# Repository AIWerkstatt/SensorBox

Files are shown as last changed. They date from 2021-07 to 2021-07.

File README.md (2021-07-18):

**[aiWerkstatt™](https://www.aiwerkstatt.com)** works on the development of a **Visual AI research platform**, 
we call the **SensorBox™**.

R&D (Research and Development) of a Visual AI (Artificial Intelligence) system requires 
the use of a flexible embedded sensor suite that allows for experimentation and that can 
be used in the real environment. Using available benchmark datasets can only get you so far, 
and may not even be representative for your particular application. Building such a 
sensor suite can be quite complex and arguably is not really part of developing a 
software application.

Our goal is to build a research platform that can be used to develop state estimation, 
mapping and scene understanding applications. Our sensor suite consists of **stereo RGB cameras**, 
a **RGB-Depth camera**, a **thermal camera**, an **ultrasonic range finder**, a 
**GNSS** (Global Navigation Satellite System) receiver, **IMU**s (Inertial Measurement Unit), 
a **pressure sensor**, a **temperature sensor** and a **power sensor**. Our embedded processing platform 
consists of an **Arduino Zero** microcontroller and an **NVIDIA Jetson Xavier NX**. Our 
embedded power source consists of a **USB-C power bank**. 

As a  research platform, we are looking for maximum flexibility and re-use. We leverage 
existing and popular eco-systems for robotics, computer vision and artificial intelligence, 
in particular the [NVIDIA Jetson](https://developer.nvidia.com/embedded-computing) embedded 
processing platform, [SparkFun](https://www.sparkfun.com)’s microcontroller and sensors 
and [Arducam](https://www.arducam.com)’s suite of cameras. 

We provide this **GitHub repository** with all design and source code files and detailed documentation 
with step-by-step instructions and **[YouTube videos](https://www.youtube.com/channel/UCgJB5recIT7bXP8dV0AoSTw/videos)** 
on how to build the SensorBox™.

So far, we completed the design, 3D printing, hardware assembly and basic software setup. 
Next, we are going to work on a ROS2 based infrastructure, a qt-based GUI, sensor calibration 
and sensor synchronization.

**[aiWerkstatt™](https://www.aiwerkstatt.com)** provides the **SensorBox™** as an **open source product** in the hope that it will provide 
researchers in Visual AI with a jump start and when used by many that it will enable 
collaborations and create synergies.

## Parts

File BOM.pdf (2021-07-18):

aiWerkstattTM | SensorBoxTM v1.0 | 1/8

# Bill of Materials (BOM)

SensorBox v1.0 | $2,015.69
Sensors & Processing and Display | $1,455.86
Embedded Processor | $502.98
NVIDIA Jetson Xavier NX Dev. Kit | 1 | $399.00
Micro SD Card | 1 | $23.99
NVMe SSD Drive | 1 | $79.99
Microcontroller | | $24.95
| 1 | $24.95
Sensors | $103.35
1 | $69.95
| 1 | $16.95

Pressure (air)

SparkFun LPS25HB Pressure Sensor | 1 | $9.95

Temperature (internal)

SparkFun TMP102 Temperature Sensor | 1 | $6.50

The complete SensorBox as shown here will cost you around $2,000 (not counting tools). But you can also get started considerably cheaper, with a NVIDIA Jetson Nano (same form factor), a low cost power bank and just the cameras.

Amazon (https://www.amazon.com/NVIDIA-Jetson-Xavier-Developer-812674024318/dp/B086874Q5R?hvadid=459454121958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)

Amazon (https://www.amazon.com/Samsung-MicroSD-Adapter-MB-ME64GA-AM/dp/B06XX29S9Q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)

Amazon (https://www.amazon.com/Samsung-970-EVO-Plus-250GB/dp/B07M7Q21N7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)

SparkFun RedBoard Turbo Dev. Board
Arduino Zero | SparkFun (https://www.sparkfun.com/products/14812)

GNSS (Global Navigation Satellite System)

SparkFun NEO-M9N GPS | SparkFun (https://www.sparkfun.com/products/15733)

IMU (Inertial Measurement Unit)

SparkFun ICM-20948 9DoF IMU | SparkFun (https://www.sparkfun.com/products/15335)

SparkFun (https://www.sparkfun.com/products/14767)

SparkFun (https://www.sparkfun.com/products/16304)

Vision Sensors | | $612.82
Stereo RGB (rolling-shutter) Cameras with IMU
Arducam Sony IMX219 Camera Module | 2 | $19.99
FPC 15 pin Ribbon Cables | 1 | $5.99
SparkFun LSM9DS1 9DoF IMU | 2 | $15.95
SparkFun Qwiic Adapter | 2 | $1.50

RGB-D Camera with IMU

Intel Realsense D435i | 1 | $199.00

Thermal Camera

FLIR Lepton 3.5 | 1 | $199.00
GroupGets PureThermal 2 | 1 | $99.00

Ultrasonic Range Finder

SparkFun Ultrasonic Range Finder | 1 | $34.95
Power | $163.77
USB-C Charger | 1 | $25.99
Poweradd USB-C Power Bank | 1 | $82.99
SparkFun USB-C Power Delivery Board | 1 | $24.95
Zio INA219 Current and Voltage Sensor | 1 | $7.95

UCTRONICS (https://www.uctronics.com/arducam-8-mp-sony-visible-light-ir-fixed-focus-camera-module-for-nvidia-jetson-nano.html)

Amazon (https://www.amazon.com/gp/product/B089LM5D1T/ref=ppx_yo_dt_b_asin_title_o04_s00?ie=UTF8&psc=1)

SparkFun (https://www.sparkfun.com/products/13944)

SparkFun (https://www.sparkfun.com/products/14495)

Intel (https://www.intelrealsense.com/depth-camera-d435i/)

GroupGets (https://store.groupgets.com/collections/frontpage/products/flir-lepton-3-5)

GroupGets (https://store.groupgets.com/products/purethermal-2)

SparkFun (https://www.sparkfun.com/products/11309)

Amazon (https://www.amazon.com/gp/product/B08F7NHMLB/ref=ox_sc_act_title_1?smid=A1AEYAFEWEFJJF&psc=1)

Amazon (https://www.amazon.com/gp/product/B015VXJL2S/ref=ppx_yo_dt_b_asin_title_o08_s00?ie=UTF8&psc=1)

SparkFun (https://www.sparkfun.com/products/15801)

SparkFun (https://www.sparkfun.com/products/15176)

Power Button | 2 | $5.95
| 1 | $9.99
Display | $47.99
UCTRONICS 5 Inch Touch Screen Display | 1 | $47.99
3D Print | $129.27
Filaments | $49.98
PETG Blue 1.75mm (1kg) | 1 | $24.99
PETG Grey 1.75mm (1kg) | 1 | $24.99
Post-Processing | | $79.29
Super Glue | 1 | $7.99
Sandpaper 150 | 1 | $4.59
Sandpaper 400 | 1 | $7.59
Wet Sandpaper 1500 | 1 | $7.59
| 1 | $8.83
Scraper | 1 | $4.65

SparkFun (https://www.sparkfun.com/products/11967)

5x DC Barrel Jack Connector 5.5mm x 2.5mm Amazon (https://www.amazon.com/gp/product/B07DJ63MJP/ref=ppx_yo_dt_b_asin_title_o03_s00?ie=UTF8&psc=1)

UCTRONICS (https://www.uctronics.com/index.php/uctronics-5-inch-touch-screen-for-raspberry-pi.html)

MatterHackers (https://www.matterhackers.com/store/l/polymaker-polylite-petg-blue-175mm-1kg/sk/MH7R7F2N)

MatterHackers (https://www.matterhackers.com/store/l/polymaker-polylite-petg-grey-175mm-1kg/sk/MUR5Z8PG)

Amazon (https://www.amazon.com/gp/product/B00JN1E4TK/ref=ox_sc_act_title_1?smid=ATVPDKIKX0DER&psc=1)

Ace Hardware (https://www.acehardware.com/departments/paint-and-supplies/painting-tools-and-supplies/sandpaper/17613)

Ace Hardware (https://www.acehardware.com/departments/paint-and-supplies/painting-tools-and-supplies/sandpaper/19807)

Ace Hardware (https://www.acehardware.com/departments/paint-and-supplies/painting-tools-and-supplies/sandpaper/19805)

Bondo Filler | Amazon (https://www.amazon.com/gp/product/B00PB3NTZ4/ref=ox_sc_act_title_3?smid=ATVPDKIKX0DER&psc=1)
| Amazon (https://www.amazon.com/Spatula-Scraper-Multipurpose-Kitchen-Pieces/dp/B088WN9LR6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)

Automotive Primer and Filler | 1 | $13.53
1 | $12.60
| 1 | $11.92
Assembly | $430.56
100x M3x6 Screws | 1 | $8.19
100x M3x5 Screws | 1 | $7.49
25x M2x6 Screws | 1 | $6.49
100x M2x4 Screws | 1 | $7.99
100x M3x6x4.5 Threaded Heat Inserts | 1 | $9.79
100x M3x4x5 Threaded Heat Inserts | 1 | $7.91
100x M2x4x3.5 Threaded Heat Inserts | 1 | $7.91
250x M2/M2/M3 Threaded Heat Inserts | 1 | $15.88
Self-Adhesive Cleat Pads | 1 | $4.99
1 | $3.59
Break Away Headers | 1 | $1.50

Amazon (https://www.amazon.com/Dupli-Color-EFP101007-General-Purpose-Sandable/dp/B000B6DG7C)

Automotive Silver Matt Spray | Amazon (https://www.amazon.com/gp/product/B00407TVGS/ref=ppx_yo_dt_b_asin_title_o01_s00?ie=UTF8&psc=1)
Automotive Clear Matt Spray | Amazon (https://www.amazon.com/gp/product/B07CZBBDF5/ref=ppx_yo_dt_b_asin_title_o01_s00?ie=UTF8&psc=1)

Amazon (https://www.amazon.com/gp/product/B00W8YSCIS/ref=ppx_yo_dt_b_asin_title_o07_s01?ie=UTF8&psc=1)

Amazon (https://www.amazon.com/gp/product/B01C3LHQ0K/ref=ppx_yo_dt_b_asin_title_o08_s00?ie=UTF8&psc=1)

Amazon (https://www.amazon.com/gp/product/B01FL88Y76/ref=ppx_yo_dt_b_asin_title_o07_s01?ie=UTF8&psc=1)

Amazon (https://www.amazon.com/gp/product/B01B1OD83Y/ref=ppx_yo_dt_b_asin_title_o00_s00?ie=UTF8&psc=1)

Amazon (https://www.amazon.com/gp/product/B087NBYF65/ref=ppx_yo_dt_b_asin_title_o07_s01?ie=UTF8&psc=1)

Amazon (https://www.amazon.com/Hilitchi-Threaded-Embedment-Projects-M2x4mmx3-5mm/dp/B07VBRF7P2)

Amazon (https://www.amazon.com/gp/product/B07VBRF7P2/ref=ppx_yo_dt_b_asin_title_o06_s00?ie=UTF8&psc=1)

Amazon (https://www.amazon.com/gp/product/B0784VYCYY/ref=ppx_yo_dt_b_asin_title_o06_s00?ie=UTF8&psc=1)

ACE Hardware (https://www.acehardware.com/departments/home-and-decor/cabinet-and-furniture-hardware/protective-furniture-pads/5044524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)

8x 14inch Cable Ties | ACE Hardware (https://www.acehardware.com/departments/lighting-and-electrical/cable-management-cable-ties-and-electrical-tape/cable-ties/34807)

SparkFun (https://www.sparkfun.com/products/116)

40x 2 pin Screw Terminal Block Connector | 1 | $6.99
SparkFun Qwicc Cable Kit | 1 | $7.95
SparkFun Qwicc Cable 50mm | 1 | $0.95
22 AWG Wires | 1 | $16.95
Heat Shrink Tubes | 1 | $7.99
100x Quick Disconnect Terminal Connector | 1 | $7.75
Duck Tape | 1 | $5.93
Double-Sided Tape | 1 | $8.99
| 1 | $9.90
| 1 | $6.24
2x USB-C direct-through Keystone Jacks | 1 | $9.90

Amazon (https://www.amazon.com/gp/product/B07B791NMQ/ref=ppx_yo_dt_b_asin_title_o00_s00?ie=UTF8&psc=1)

SparkFun (https://www.sparkfun.com/products/15081)

SparkFun (https://www.sparkfun.com/products/14426)

SparkFun (https://www.sparkfun.com/products/11367)

Amazon (https://www.amazon.com/gp/product/B073R69KNB/ref=ppx_yo_dt_b_asin_title_o05_s02?ie=UTF8&psc=1)

Amazon (https://www.amazon.com/gp/product/B01EE3QGG0/ref=ppx_yo_dt_b_asin_title_o05_s01?ie=UTF8&psc=1)

Amazon (https://www.amazon.com/3M-Contractor-Grade-Multi-Use-Silver/dp/B00DJWTGAG?s=industrial)

Amazon (https://www.amazon.com/gp/product/B07T1PWMTT/ref=ppx_yo_dt_b_asin_title_o00_s00?ie=UTF8&psc=1)

5x USB 3.0 direct-through Keystone Jacks | Amazon (https://www.amazon.com/gp/product/B078935SFG/ref=ppx_yo_dt_b_asin_title_o01_s02?ie=UTF8&psc=1)
HDMI direct-through Keystone Jack | Amazon (https://www.amazon.com/gp/product/B005VKKB7Q/ref=ppx_yo_dt_b_asin_title_o01_s01?ie=UTF8&psc=1)
| Amazon (https://www.amazon.com/gp/product/B078495TVK/ref=ppx_yo_dt_b_asin_title_o01_s03?ie=UTF8&psc=1)

PC Computer Air Filter | 1 | $8.99
2x HDMI Male to Female Cable | 1 | $7.99
2 | $6.49
DisplayPort Male to HDMI Female Cable | 1 | $13.99
HDMI Male to Male Cable | 1 | $7.36
Micro USB to USB Cable | 2 | $6.49
USB-C Male to Male 100W Cable | 1 | $9.99
USB-C Male to Male 100W Cable | 1 | $9.99
Long USB Cable | 1 | $10.99
Long HDMI Cable | 1 | $9.99
HDMI Monitor | 1 | $93.99
Dual USB & Bluetooth Keyboard and Mouse | 1 | $47.99

Amazon (https://www.amazon.com/gp/product/B000FJU8BC/ref=ppx_yo_dt_b_asin_title_o01_s03?ie=UTF8&psc=1)

Amazon (https://www.amazon.com/gp/product/B06WGPT999/ref=ppx_yo_dt_b_asin_title_o06_s00?ie=UTF8&psc=1)

90° Micro USB to USB Cable | Amazon (https://www.amazon.com/gp/product/B003YKX6WC/ref=ppx_yo_dt_b_asin_title_o01_s00?ie=UTF8&psc=1)

Amazon (https://www.amazon.com/gp/product/B019Q652AG/ref=ppx_yo_dt_b_asin_title_o02_s00?ie=UTF8&psc=1)

Amazon (https://www.amazon.com/gp/product/B07KSP1SMS/ref=ppx_yo_dt_b_asin_title_o02_s00?ie=UTF8&psc=1)

Amazon (https://www.amazon.com/6in-Micro-USB-Cable-6-inches/dp/B002L5ZEYY)

Amazon (https://www.amazon.com/gp/product/B072M7GH29/ref=ppx_yo_dt_b_asin_title_o00_s00?ie=UTF8&psc=1)

Amazon (https://www.amazon.com/gp/product/B08816SYKY/ref=ppx_yo_dt_b_asin_title_o09_s02?ie=UTF8&psc=1)

Amazon (https://www.amazon.com/gp/product/B00HSS9L6G/ref=ppx_yo_dt_b_asin_title_o04_s00?ie=UTF8&psc=1)

Amazon (https://www.amazon.com/AmazonBasics-High-Speed-HDMI-Cable-1-Pack/dp/B014I8T0YQ?s=electronics)

Amazon (https://www.amazon.com/Acer-SB220Q-Ultra-Thin-Frame-Monitor/dp/B07CVL2D2S?s=electronics)

Amazon (https://www.amazon.com/gp/product/B0899DRDYR/ref=ppx_yo_dt_b_asin_title_o07_s00?ie=UTF8&psc=1)

30x Circuit Board Jumper Caps | 1 | $5.08
Jumper Wires | 1 | $6.98
Tools | $998.38
Caliper | 1 | $8.99

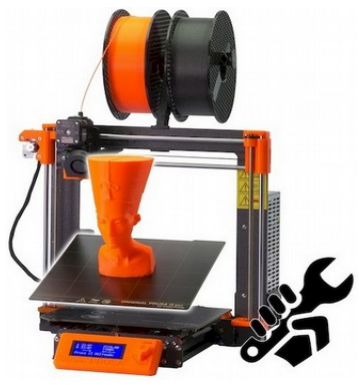
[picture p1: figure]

1 | $749.00
Carving Craft Knife | 1 | $9.99
Needle File Set | 1 | $16.05
Sander | 1 | $36.38
Sanding Discs | 1 | $14.99
Soldering Iron | 1 | $20.99
Helping Hands | 1 | $22.99

Amazon (https://www.amazon.com/gp/product/B077957RN7/ref=ppx_yo_dt_b_search_asin_title?ie=UTF8&psc=1&fpw=alm)

Amazon (https://www.amazon.com/Elegoo-EL-CP-004-Multicolored-Breadboard-arduino/dp/B01EV70C78)

Amazon (https://www.amazon.com/gp/product/B07VSVMWTJ/ref=ppx_yo_dt_b_asin_title_o00_s00?ie=UTF8&psc=1)

3D Printer | Prusa Research (https://shop.prusa3d.com/en/3d-printers/180-original-prusa-i3-mk3s-kit.html#)

Amazon (https://www.amazon.com/Mlife-Precision-Carving-Stainless-Cutting/dp/B074P34MFB)

Amazon (https://www.amazon.com/gp/product/B07TSK23LY/ref=ppx_yo_dt_b_asin_title_o07_s00?ie=UTF8&psc=1)

Amazon (https://www.amazon.com/gp/product/B08B6G2X2H/ref=ppx_yo_dt_b_asin_title_o03_s00?ie=UTF8&psc=1)

Amazon (https://www.amazon.com/gp/product/B06XQH4PVM/ref=ppx_yo_dt_b_asin_title_o03_s00?ie=UTF8&psc=1)

Amazon (https://www.amazon.com/gp/product/B06XZ31W3M/ref=ppx_yo_dt_b_asin_title_o08_s00?ie=UTF8&psc=1)

Amazon (https://www.amazon.com/gp/product/B07MDKXNPC/ref=ppx_yo_dt_b_asin_title_o08_s00?ie=UTF8&psc=1)

| 1 | $7.95
| 1 | $12.95
Crimper | 1 | $22.29
Heat Gun | 1 | $12.99
Allen Keys | 1 | $15.29
Screwdrivers | 1 | $18.69
Precision Screwdrivers | 1 | $13.89
Multimeter | 1 | $14.95

## Computers

Solder | SparkFun (https://www.sparkfun.com/products/9325)
Wire Strippers | SparkFun (https://www.sparkfun.com/products/14762) Amazon (https://www.amazon.com/IWISS-SN-28B-Crimping-AWG28-18-Dupont/dp/B00OMM4YUY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)
| Amazon (https://www.amazon.com/gp/product/B07P5WFHJ7/ref=ppx_yo_dt_b_asin_title_o05_s01?ie=UTF8&psc=1)

Amazon (https://www.amazon.com/Eklind-Tool-Company-10222-Combination/dp/B000189PRU?s=hi)

Amazon (https://www.amazon.com/VHEONET-Screwdriver-Precision-Professional-Improvement/dp/B08GX4SSJM?s=hi)

Amazon (https://www.amazon.com/dp/B07SL25J5J)

SparkFun (https://www.sparkfun.com/products/12966)

Ubuntu 18 Host Computer
preferable with a NVIDIA graphics card

Windows 10 Computer
only for use with SparkFun NEO-M9N GPS

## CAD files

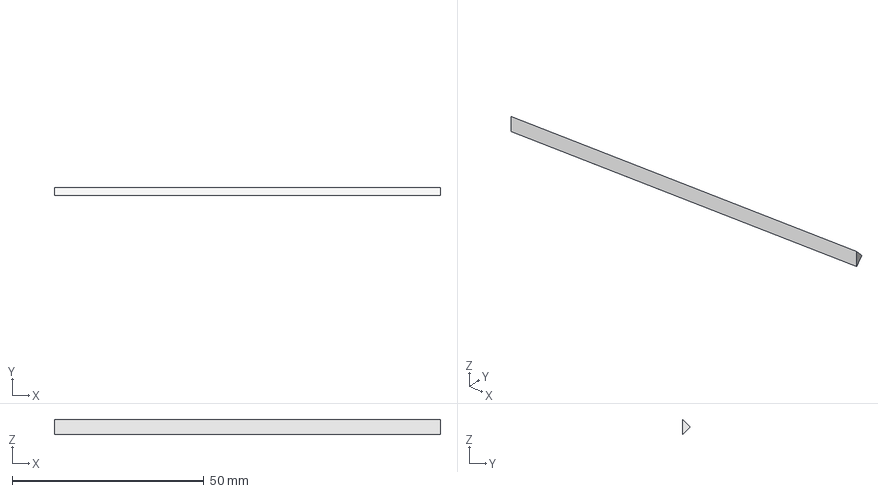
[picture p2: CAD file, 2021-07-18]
1-CAD/Design/Cover/Display_Wall_Groove_Triangle_w4xd2xl100.7.step
100.7 x 2.00 x 4.00 mm

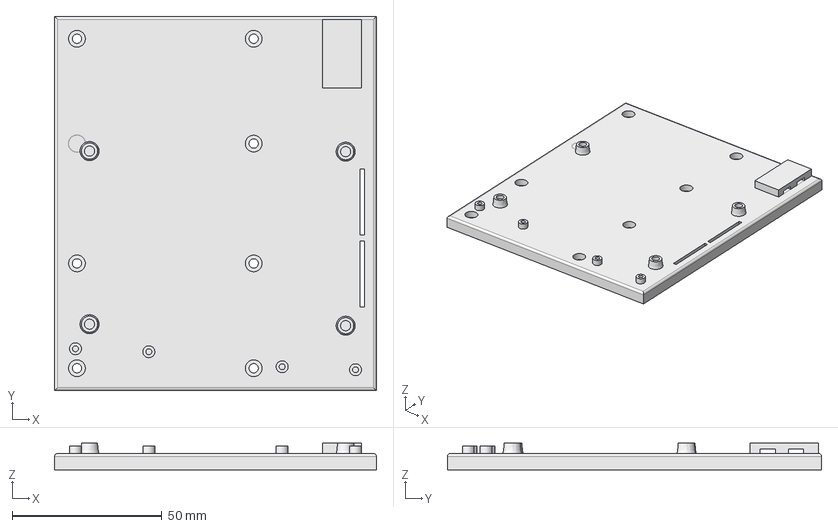
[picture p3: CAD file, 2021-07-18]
1-CAD/Design/Sensors & Processing Board/Processing_Board.FCStd
107.5 x 125.0 x 9.00 mm

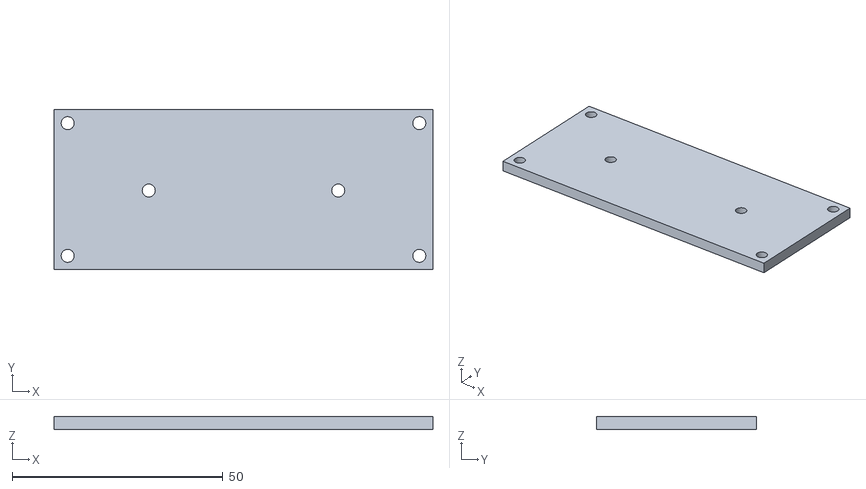
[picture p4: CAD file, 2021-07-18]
1-CAD/STL-files/IntelRS_Support.stl
90.0 x 38.0 x 3.00

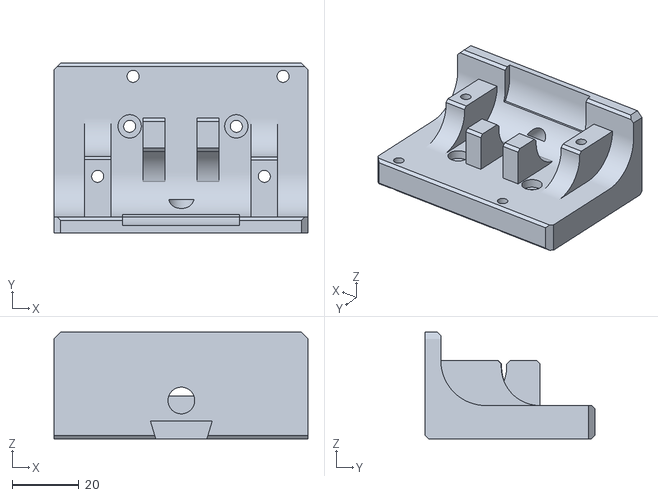
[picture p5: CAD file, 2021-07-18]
4-Setup/sw/NVIDIA_Jetson_Xavier_NX/Intel_RealSense_D435i/librealsense/examples/tracking-and-depth/bracket_t265nd435_external.stl
76.2 x 51.0 x 32.0

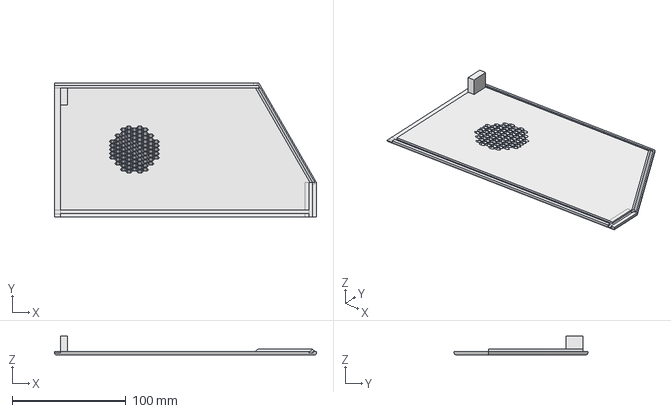
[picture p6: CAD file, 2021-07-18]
1-CAD/Design/Cover/Side_Wall.step
230.0 x 117.2 x 16.5 mm

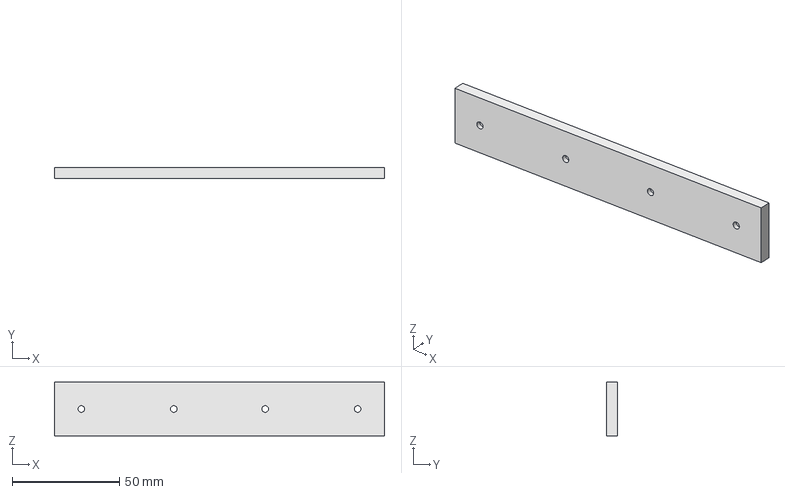
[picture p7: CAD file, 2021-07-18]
1-CAD/Design/Sensors & Processing Board/Support.step
153.5 x 5.00 x 25.0 mm

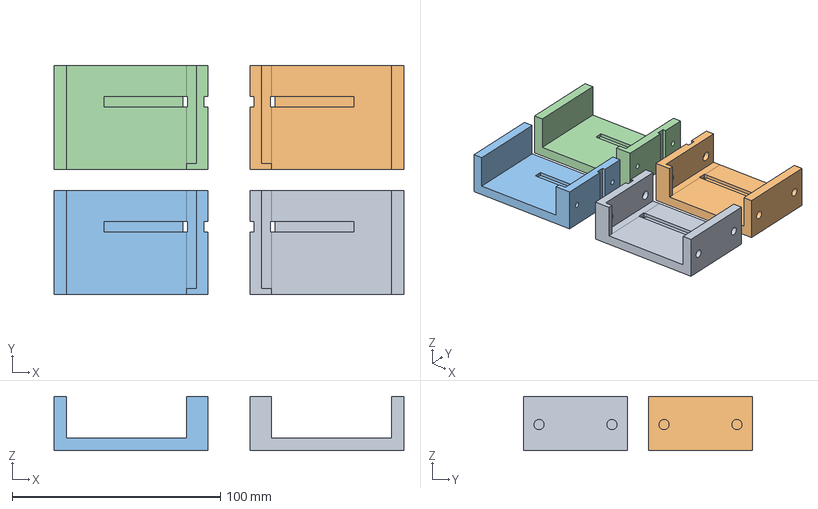
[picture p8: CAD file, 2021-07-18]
1-CAD/Design/Sensors & Processing Board/Battery_Stand.FCStd
168.0 x 110.0 x 26.0 mm
Battery Stand Blueprint (back/right)
Battery Stand (front/left) without holes in the back
Battery Stand (front/right) (Mirror #1)
Battery Stand (back/left) (Mirror #2)

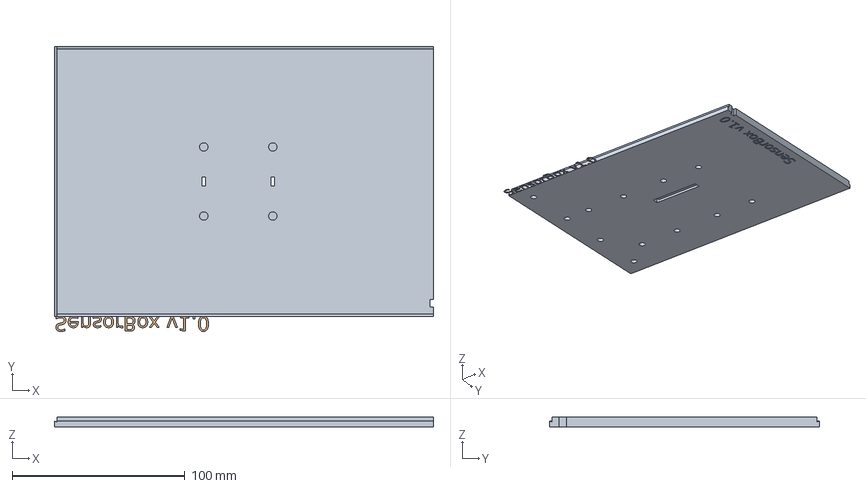
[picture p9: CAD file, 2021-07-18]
1-CAD/Design/Sensors & Processing Board/Bottom_Plate.FCStd
219.6 x 165.2 x 6.00 mm
Bottom Plate
ShapeString
Product Name

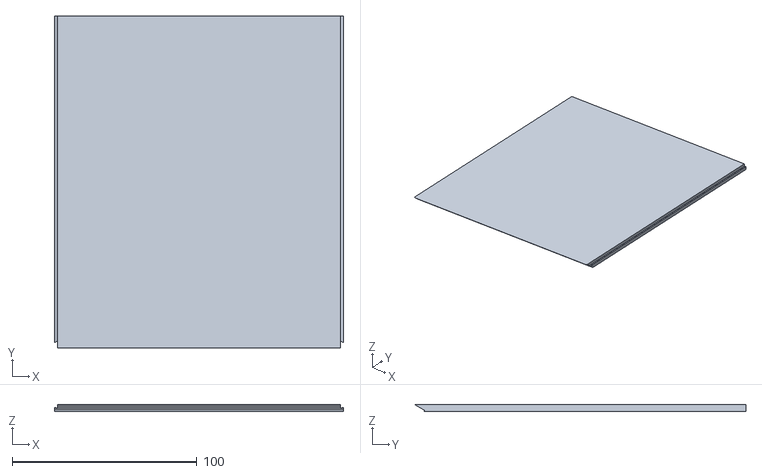
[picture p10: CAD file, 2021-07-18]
1-CAD/STL-files/Top_Wall.stl
156.5 x 179.6 x 4.00

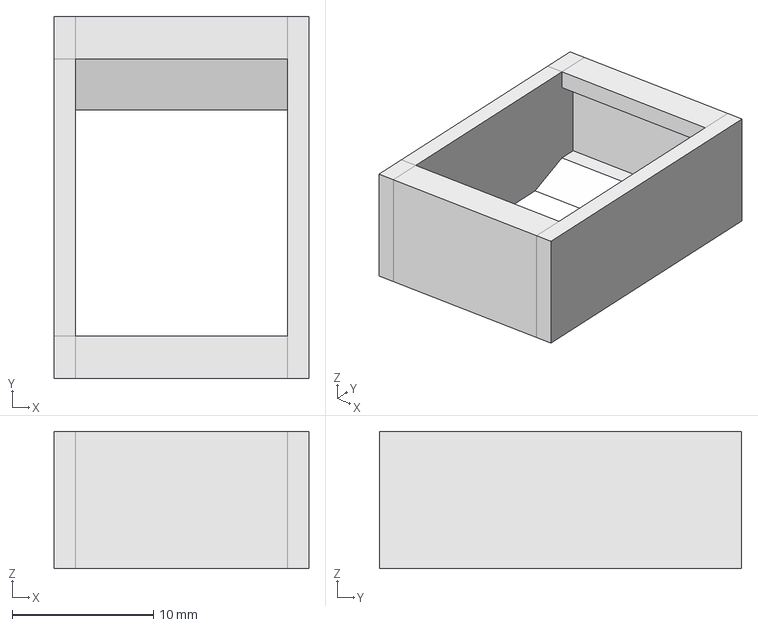
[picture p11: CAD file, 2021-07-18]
1-CAD/Design/Cover/Keystone_Insert.step
18.0 x 25.6 x 9.70 mm

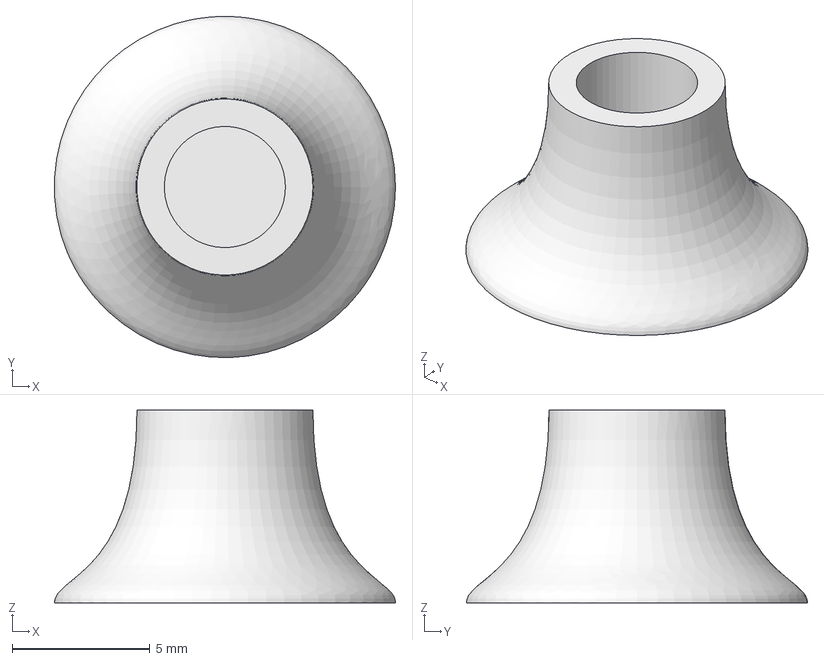
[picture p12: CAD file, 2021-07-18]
1-CAD/Design/Sensors & Processing Board/MXxXxX_Stand.FCStd
12.4 x 12.4 x 7.00 mm

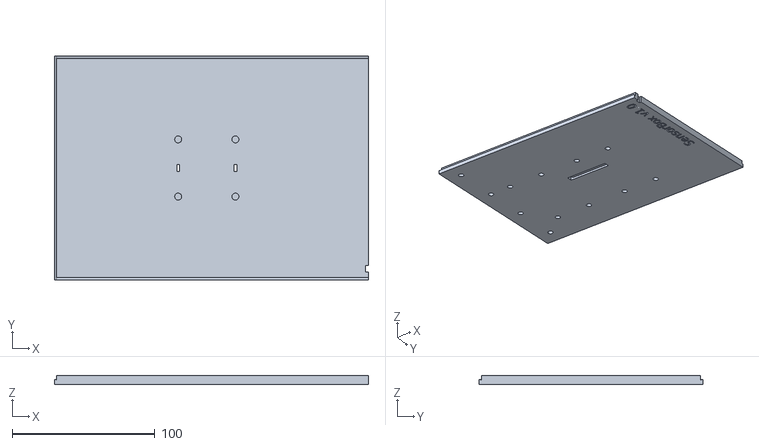
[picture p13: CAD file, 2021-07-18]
1-CAD/STL-files/Bottom_Plate.stl
219.6 x 156.5 x 6.00

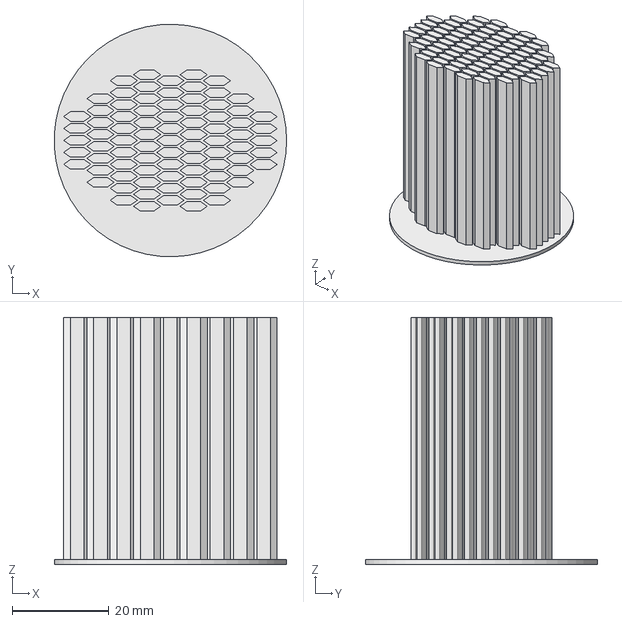
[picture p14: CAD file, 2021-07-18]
1-CAD/Design/Cover/Air_Holes.step
48.0 x 48.0 x 51.0 mm

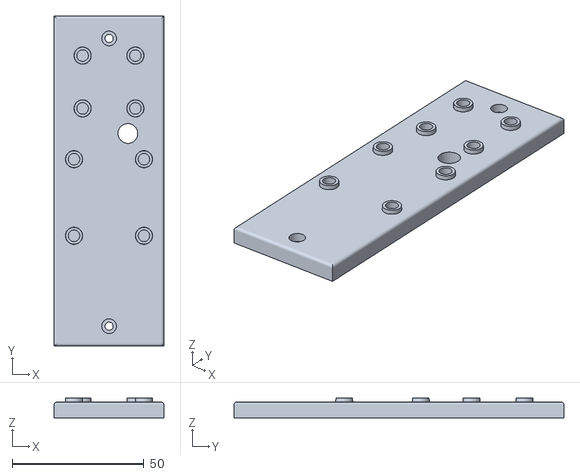
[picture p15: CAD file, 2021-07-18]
1-CAD/STL-files/Power_Board.stl
41.6 x 125.0 x 7.50

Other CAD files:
1-CAD/STL-files/Processing_Board.stl
1-CAD/Design/Cover/Display_Wall_Groove_Railing_Triangle.FCStd
1-CAD/STL-files/Battery_Stand.stl
1-CAD/Design/Cover/Display_Wall_Groove_Triangle.FCStd
1-CAD/Design/Cover/Air_Holes.FCStd
1-CAD/Design/Cover/Back_Wall.FCStd
1-CAD/Design/Cover/Display_Wall.FCStd
1-CAD/Design/Cover/Display_Wall.step
1-CAD/Design/Cover/Display_Wall_Groove_Railing_Triangle_w3.9xd2xl100.7.step
1-CAD/Design/Cover/Keystone_Insert.FCStd
1-CAD/Design/Cover/Side_Wall.FCStd
1-CAD/Design/Cover/Side_Wall_Left.FCStd
1-CAD/Design/Cover/Side_Wall_Right.FCStd
1-CAD/Design/Cover/Top_Wall.FCStd
1-CAD/Design/Sensors & Processing Board/Intel_RealSense_Support.FCStd
1-CAD/Design/Sensors & Processing Board/M2x6x3.5_Stand.step
1-CAD/Design/Sensors & Processing Board/M3x6x4.5_Stand.step
1-CAD/Design/Sensors & Processing Board/Power_Board.FCStd
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

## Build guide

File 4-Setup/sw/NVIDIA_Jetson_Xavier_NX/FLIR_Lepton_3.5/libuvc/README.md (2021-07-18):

`libuvc` is a cross-platform library for USB video devices, built atop `libusb`.
It enables fine-grained control over USB video devices exporting the standard USB Video Class
(UVC) interface, enabling developers to write drivers for previously unsupported devices,
or just access UVC devices in a generic fashion.

## Getting and Building libuvc

Prerequisites: You will need `libusb` and [CMake](http://www.cmake.org/) installed.

To build, you can just run these shell commands:

    git clone https://github.com/groupgets/libuvc
    cd libuvc
    mkdir build
    cd build
    cmake ..
    make && sudo make install

and you're set! If you want to change the build configuration, you can edit `CMakeCache.txt`
in the build directory, or use a CMake GUI to make the desired changes.

## Developing with libuvc

The documentation for `libuvc` can currently be found at https://int80k.com/libuvc/doc/.

Happy hacking!

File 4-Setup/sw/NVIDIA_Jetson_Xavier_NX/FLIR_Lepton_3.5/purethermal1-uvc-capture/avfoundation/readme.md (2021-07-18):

About PT1Recorder
================

This example very lightly modified from Apple's AVRecorder example.

PT1Recorder demonstrates usage of AV Foundation capture API for recording movies and using transport controls.

The main components are:

• AVRecorderDocument.[h,m] -- The core PT1Recorder code
• AVCaptureDeviceFormat_AVRecorderAdditions.[h,m] -- Prints a pretty device format NSString
• AVFrameRateRange_AVRecorderAdditions.[h,m] -- Prints a pretty frame rate NSString

Using the Sample
----------------
Begin and complete video recording with the Record button. If the selected video device supports transport controls, use the Rewind, Play, Stop, and FF buttons to control the tape.

How It Works
------------

PT1Recorder makes use of the following AV Foundation AVCapture classes to provide movie recording:

AVCaptureDevice
AVCaptureFileOutput
AVCaptureInput
AVCaptureMovieFileOutput
AVCaptureOutput
AVCaptureSession
AVCaptureVideoPreviewLayer

See the AV Foundation documentation for more information.

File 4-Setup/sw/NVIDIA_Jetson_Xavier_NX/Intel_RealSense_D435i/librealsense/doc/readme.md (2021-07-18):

## Useful Links
* White papers and further documents are available at: [intel-realsense-downloads](https://realsense.intel.com/intel-realsense-downloads/)
* [Intel RealSense Community](https://communities.intel.com/community/tech/realsense) - Official support, Q&A and other useful content
* [Support Site](http://www.intel.com/content/www/us/en/support/emerging-technologies/intel-realsense-technology.html) - Contains content and web ticket capability for 1:1 interaction
* [Intel RealSense Stereoscopic Depth Cameras](https://arxiv.org/abs/1705.05548) - A technical paper describing the R200, LR200, SR300 and RS400 in detail. Includes theoretical background, performance expectations, post-processing suggestions, etc.  
* [Build an Autonomous Mobile Robot with the Intel® RealSense™ D400 Series Camera, ROS*, and SAWR](https://software.intel.com/en-us/articles/build-an-autonomous-mobile-robot-with-the-intel-realsense-camera-ros-and-sawr)

## librealsense Wiki
* [API How-To](https://github.com/IntelRealSense/librealsense/wiki/API-How-To) - List ot questions and answers related to the camera API
* [Troubleshooting Q&A](https://github.com/IntelRealSense/librealsense/wiki/Troubleshooting-Q&A) - List of questions and answers related to camera setup
* [Build Configuration](https://github.com/IntelRealSense/librealsense/wiki/Build-Configuration) - List of supported CMake flags
* [Projection In RealSense SDK 2.0](https://github.com/IntelRealSense/librealsense/wiki/Projection-in-RealSense-SDK-2.0) - A comprehensive document on Projection, Deprojection, and related helper processing-blocks the SDK provides

## Documentation

* [Depth from Stereo](depth-from-stereo.md) - Tutorial introducing users to depth from stereo technology 
* [API Architecture](api_arch.md) - Overview of the high-level concepts
* [C API](../include/librealsense2) - With doxygen-style API comments
  * [Latest Doxygen Output](http://intelrealsense.github.io/librealsense/doxygen/annotated.html)
  * To build documentation locally from sources, on Ubuntu run the following commands:
    * `sudo apt-get install doxygen`
    * `cd doc/doxygen`
    * `doxygen doxyfile`
  * Please also refer to [API How-To](https://github.com/IntelRealSense/librealsense/wiki/API-How-To) for further doc how to use the APIs
* [Frame Management](frame_lifetime.md) - Frame Memory Management, Threading Model and Synchronization
* [Frame Metadata](frame_metadata.md) - Support for frame-metadata attributes
* [Post-Processing Filters](post-processing-filters.md) - Post-acquisition Depth enhancement techniques
* [Getting Started](stepbystep/getting_started_with_openCV.md) - Getting started with OpenCV
* [Error Handling](error_handling.md) - Documents librealsense error handling policy
* Device specific topics:
  * [D400 at realsense.intel.com/](https://realsense.intel.com/stereo) - Camera specifications
  * [D400 Advanced Mode](rs400/rs400_advanced_mode.md) - Overview of the Advanced Mode APIs
  * [D400 cameras with Raspberry Pi](./RaspberryPi3.md) - Example of low-end system without USB3 interface
  * [D400 cameras on **rooted** Android devices](./android.md) - Instructions of how to build the RealSense SDK for Android OS.
  * [D435i depth camera with IMU](./d435i.md) - An introduction to the D435i depth camera and it's IMU
  * [T265 tracking module](./t265.md) - An introduction to the T265 tracking module
* [Record and Playback](../src/media/readme.md) - SDK Record and Playback functionality using ROS-bag file format

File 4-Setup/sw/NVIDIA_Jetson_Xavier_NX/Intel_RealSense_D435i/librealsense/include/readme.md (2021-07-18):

# librealsense2 API

# File-System Structure

Under `librealsense2` folder you will find two subfolers:
* [h](./librealsense2/h) - Contains headers for the C language
* [hpp](./librealsense2/hpp) - Contains headers for the C++ language, depends on C headers

In addition, you can include [<librealsense2/rs.h>](./librealsense2/rs.h) and [<librealsense2/rs.hpp>](./librealsense2/rs.hpp) to get most of SDK functionality in C and C++ respectively. 

[<librealsense2/rs_advanced_mode.h>](./librealsense2/rs_advanced_mode.h) and [<librealsense2/rs_advanced_mode.hpp>](./librealsense2/rs_advanced_mode.hpp) can be included to get the extra [Advanced Mode](../doc/rs400_advanced_mode.md) functionality (in C and C++ respectively).

[<librealsense2/rsutil.h>](./librealsense2/rsutil.h) contains mathematical helper functions for projection of 2D points into 3D space and back. 

# Files and Classes

> For full up-to-date class documentation see [Doxygen class-list](http://intelrealsense.github.io/librealsense/doxygen/annotated.html)

## [rs_types.hpp](librealsense2/hpp/rs_types.hpp):

This file contains common functionality like the exception types. See [Error Handling](..doc/error_handling.md)

|Class|Description|
|-----|---|
|[error](librealsense2/hpp/rs_types.hpp#L76)| Common base-class for all exceptions thrown from the SDK |
|[recoverable_error](librealsense2/hpp/rs_types.hpp#L113)| Base class for all recorverable (in software) errors |
|[unrecoverable_error](librealsense2/hpp/rs_types.hpp#L114)| Base class for non-recoverable errors |
|[camera_disconnected_error](librealsense2/hpp/rs_types.hpp#L115)| Camera Disconnected error |
|[backend_error](librealsense2/hpp/rs_types.hpp#L116)| Error from the underlying OS-specific driver |
|[device_in_recovery_mode_error](librealsense2/hpp/rs_types.hpp#L117)| Device requires firmware update |
|[invalid_value_error](librealsense2/hpp/rs_types.hpp#L118)| Invalid input was passed to a function |
|[wrong_api_call_sequence_error](librealsense2/hpp/rs_types.hpp#L119)| Methods were called in wrong order |
|[not_implemented_error](librealsense2/hpp/rs_types.hpp#L120)| Functionality is not available error |

## [rs_context.hpp](librealsense2/hpp/rs_context.hpp):
Context can be used to enumerate and iterate over connected device, and also get notifications of device events. 

|Class|Description|
|-----|---|
|[context](librealsense2/hpp/rs_context.hpp#L81)| Context serve as a factory for all SDK devices |
|[device_hub](librealsense2/hpp/rs_context.hpp#L185)| Helper class that simplifies handling device change events |
|[event_information](librealsense2/hpp/rs_context.hpp#L16)| Information about device change |

## [rs_device.hpp](librealsense2/hpp/rs_device.hpp):
This file defines the concept of RealSense device. 

|Class|Description|
|-----|---|
|[device](librealsense2/hpp/rs_device.hpp#L109)| Encapsulates Intel RealSense device |
|[device_list](librealsense2/hpp/rs_device.hpp#L186)| Wrapper around list of devices |
|[debug_protocol](librealsense2/hpp/rs_device.hpp#L151)| Debug-extension that allows to send data directly to the firmware |

## [rs_processing.hpp](librealsense2/hpp/rs_processing.hpp):
The SDK offers many types of post-processing in form of the Processing Blocks. These primitives can be pipelined using queues and configured using options. 

|Class|Description|
|-----|---|
|[syncer](librealsense2/hpp/rs_processing.hpp#L260)| Processing block that accepts frames one-by-one and outputs coherent framesets|
|[frame_queue](librealsense2/hpp/rs_processing.hpp#L136)| Basic primitive abstracting a concurrent queue of frames|
|[processing_block](librealsense2/hpp/rs_processing.hpp#L105)| Base class for frame processing functions |
|[pointcloud](librealsense2/hpp/rs_processing.hpp#L196)| Processing block that accepts depth and texture frames and outputs 3D points with texture coordinates |
|[asynchronous_syncer](librealsense2/hpp/rs_processing.hpp#L232)| Non-blocking version of the syncher processing block |
|[align](librealsense2/hpp/rs_processing.hpp#L316)| Processing block that accepts frames from different viewports and generates new synthetic frames from a single given viewport |
|[colorizer](librealsense2/hpp/rs_processing.hpp#L356)| Processing block that accepts depth frames in Z16 format and outputs depth frames in RGB format, applying some depth coloring |
|[decimation_filter](librealsense2/hpp/rs_processing.hpp#L391)| Processing block that intelligently reduces the resolution of a depth frame |
|[temporal_filter](librealsense2/hpp/rs_processing.hpp#L428)| Processing block that filters depth data by looking into previous frames |
|[spatial_filter](librealsense2/hpp/rs_processing.hpp#L465)| Processing block that applies edge-preserving smoothing of depth data|

## [rs_sensor.hpp](librealsense2/hpp/rs_sensor.hpp):
RealSense devices contain sensors. Sensors are units of streaming, each sensor can be controlled individually. 

|Class|Description|
|-----|---|
|[sensor](librealsense2/hpp/rs_sensor.hpp#L392)| Base class for all supported sensors|
|[roi_sensor](librealsense2/hpp/rs_sensor.hpp#L446)| Sensor that has the ability to focus on a given ROI|
|[notification](librealsense2/hpp/rs_sensor.hpp#L15)| Asynchronious message that can be passed to the application |
|[depth_sensor](librealsense2/hpp/rs_sensor.hpp#L479)| Sensor that can provide depth frames |

## [rs_frame.hpp](librealsense2/hpp/rs_frame.hpp):
The output of sensors are frames. There are different kinds of frames, not all video frames. 

|Class|Description|
|-----|---|
|[frame](librealsense2/hpp/rs_frame.hpp#L157)| Base class for all frames |
|[points](librealsense2/hpp/rs_frame.hpp#L423)| Set of 3D points with texture coordinates |
|[video_frame](librealsense2/hpp/rs_frame.hpp#L348)| 2D image (with width, height and bpp) |
|[depth_frame](librealsense2/hpp/rs_frame.hpp#L480)| Depth frame |
|[frameset](librealsense2/hpp/rs_frame.hpp#L502)| A set of frames |
|[stream_profile](librealsense2/hpp/rs_frame.hpp#L24)| Base class for sensor configuration |
|[video_stream_profile](librealsense2/hpp/rs_frame.hpp#L113)| Video stream configuration |

## [rs_pipeline.hpp](librealsense2/hpp/rs_pipeline.hpp):
Pipeline is a high-level primitive combining several sensors and processing steps into one simple API. 

|Class|Description|
|-----|---|
|[pipeline](librealsense2/hpp/rs_pipeline.hpp#L345)| High level data-processor combining several sensors, queues and processing blocks |
|[pipeline_profile](librealsense2/hpp/rs_pipeline.hpp#L22)| Selected pipeline configuration |
|[config](librealsense2/hpp/rs_pipeline.hpp#L128)| Desired pipeline configuration |

## [rs_record_playback.hpp](librealsense2/hpp/rs_record_playback.hpp):
This file adds playback and record capability using ROS-bag files. See [src/media](src/media)

|Class|Description|
|-----|---|
|[playback](librealsense2/hpp/rs_record_playback.hpp#L30)| Device that mimiks live device from given input file |
|[recorder](librealsense2/hpp/rs_record_playback.hpp#L206)| Device that records live device into an output file |

## [rs_internal.hpp](librealsense2\hpp\rs_internal.hpp):
This file is not intented to be included by SDK users, but rather is used in SDK unit-tests. It allows to record everything that will happen in a specific test into a file and later use that file for dependency injection. 

|Class|Description|
|-----|---|
|[recording_context](librealsense2\hpp\rs_internal.hpp#L19)| Context that records all backend activity to file |
|[mock_context](librealsense2\hpp\rs_internal.hpp#L41)| Context that replays all activity from file |

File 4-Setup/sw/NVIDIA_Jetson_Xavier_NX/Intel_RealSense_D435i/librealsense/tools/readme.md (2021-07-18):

# Tools for Intel® RealSense™ Camera

1. [RealSense-Viewer](./realsense-viewer) - This application allows you to quickly access your Intel® RealSense™ Depth cameras and modules.  It allows you to view the depth stream, record and playback streams, configure your camera and much more.
2. [Depth Quality Tool](./depth-quality) - Application that calculates and visualizes depth metrics to assess and characterize the quality of the depth data.
3. [Convert Tool](./convert) - Console application for converting ROS-bag files to various formats
4. [Recorder](./recorder) - Simple command line data recorder

### Debug Tools

3. [Enumerate-Devices](./enumerate-devices) - Console application providing information about connected devices
4. [Firmware-Logger](./fw-logger) - Console application for collecting internal camera logs.
5. [Data-Collect](./data-collect) - Console application capable of generating CSV report of frame statistics
6. [Terminal](./terminal) - Troubleshooting tool that sends commands to the camera firmware
7. [ROS Bag Inspector](./rosbag-inspector) - GUI application for inspecting `.bag` files

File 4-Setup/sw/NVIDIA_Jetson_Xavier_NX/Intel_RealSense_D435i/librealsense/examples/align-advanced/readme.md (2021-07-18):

# rs-align-advanced Sample

## Overview

This sample demonstrates one possible use-case of the `rs2::align` object, which allows users to align between the depth and other streams and vice versa. <br>

The alignment utility performs per-pixel geometric transformation based on the depth data provided and is not suited for aligning images that are intrinsically 2D, such Color, IR or Fisheye. In addition the transformation requires undistorted (rectified) images to proceed, and therefore is not applicable to the IR calibration streams.  

In this example, we align depth frames to their corresponding color frames.
We generate a new frame sized as color stream but the content being depth data calculated in the color sensor coordinate system. In other word to reconstruct a depth image being "captured" using the origin and dimensions of  the color sensor.
Then, we use the original color and the re-projected depth frames (which are aligned at this stage) to determine the depth value of each color pixel.

Using this information, we "remove" the background of the color frame that is further (away from the camera) than some user-define distance.

The example displays a GUI for controlling the maximum distance to show from the original color image.

## Expected Output

The application should open a window and display a video stream from the camera.

<p align="center">screenshot gif</p>

The window should have the following elements:
- On the left side of the window is a vertical slider for controlling the depth clipping distance.
- A color image with grayed out background
- A corresponding (colorized) depth image.

## Code Overview

As with any SDK application we include the Intel RealSense Cross Platform API:

```cpp
#include <librealsense2/rs.hpp>
```

In this example we will also use the auxiliary library of `example.hpp`:

```cpp
#include "../example.hpp"    
```

`examples.hpp` lets us easily open a new window and prepare textures for rendering.

We include 2 more header files which will help us to render GUI controls in our window application:

```cpp
#include <imgui.h>
#include "imgui_impl_glfw.h"
```

These headers are part of the [ImGui](https://github.com/ocornut/imgui) library which we use to render GUI elements.

Next, we declare several functions to help the code look clearer:
```cpp
void render_slider(rect location, float& clipping_dist);
void remove_background(rs2::video_frame& color, const rs2::depth_frame& depth_frame, float depth_scale, float clipping_dist);
float get_depth_scale(rs2::device dev);
rs2_stream find_stream_to_align(const std::vector<rs2::stream_profile>& streams);
bool profile_changed(const std::vector<rs2::stream_profile>& current, const std::vector<rs2::stream_profile>& prev);
```

`render_slider(..)`  is where all the GUI code goes, and we will not cover this function in this overview.

`remove_background(..)` takes depth and color images (that are assumed to be aligned to one another), the depth scale units, and the maximum distance the user wishes to show, and updates the color frame so that its background (any pixel with depth distance larger than the maximum allowed) is removed.

`get_depth_scale(..)` tries to find a depth sensor from the pipeline's device and retrieves its depth scale units.

`find_stream_to_align(..)` goes over the given streams and verify that it has a depth profile and tries to find another profile to which depth should be aligned.

`profile_changed()` checks if the current streaming profiles contains all the previous one.

Heading to `main`:

We first define some variables that will be used to show the window and render the images and GUI to the screen:

```cpp
// Create and initialize GUI related objects
window app(1280, 720, "CPP - Align Example"); // Simple window handling
ImGui_ImplGlfw_Init(app, false);      // ImGui library intializition
rs2::colorizer c;                          // Helper to colorize depth images
texture renderer;                     // Helper for renderig images
```

Next, we define a `rs2::pipeline` which is a top level API for using RealSense depth cameras.
`rs2::pipeline` automatically chooses a camera from all connected cameras, so we can simply call `pipeline::start()` and the camera is configured and streaming:

```cpp
// Create a pipeline to easily configure and start the camera
rs2::pipeline pipe;
//Calling pipeline's start() without any additional parameters will start the first device
// with its default streams.
//The start function returns the pipeline profile which the pipeline used to start the device
rs2::pipeline_profile profile = pipe.start();
```

At this point of the program the camera is configured and streams are available from the pipeline.

Before actually using the frames, we try to get the depth scale units of the depth camera. Depth scale units are used to convert the depth pixel data (16-bit unsigned) into metric units.

```cpp
// Each depth camera might have different units for depth pixels, so we get it here
// Using the pipeline's profile, we can retrieve the device that the pipeline uses
float depth_scale = get_depth_scale(profile.get_device());
```

These units are expressed as depth in meters corresponding to a depth value of 1. For example if we have a depth pixel with a value of 2 and the depth scale units are 0.5 then that pixel is `2 X 0.5 = 1` meter away from the camera.

Then, we create an `align` object:

```cpp
//Pipeline could choose a device that does not have a color stream
//If there is no color stream, choose to align depth to another stream
rs2_stream align_to = find_stream_to_align(profile.get_streams());

// Create a rs2::align object.
// rs2::align allows us to perform alignment of depth frames to others frames
//The "align_to" is the stream type to which we plan to align depth frames.
rs2::align align(align_to);
```

`rs2::align` is a utility class that performs image alignment (registration) of 2 frames.
Basically, each pixel from the first image will be transformed so that it matches its corresponding pixel in the second image.
A `rs2::align` object transforms between two input images, from a source image to some target image which is specified with the `align_to` parameter.

Now comes the interesting part of the application. We start our main loop, which breaks only when the window is closed:

```cpp
while (app) // Application still alive?
{
```

Inside the loop, the first thing we do is block the program until the `align` object returns a `rs2::frameset`. A `rs2::frameset` is an object that holds a set of frames and provides an interface for easily accessing them.

```cpp
  // Using the align object, we block the application until a frameset is available
  rs2::frameset frameset = pipe.wait_for_frames();
```

The `frameset` returned from `wait_for_frames` should contain a set of aligned frames. In case of an error getting the frames an exception could be thrown, but if the pipeline manages to reconfigure itself with a new device it will do that and return a frame from the new device.
In the next lines we check if the pipeline switched its device and if so update the align object and the rest of objects required for the sample.

```cpp
// rs2::pipeline::wait_for_frames() can replace the device it uses in case of device error or disconnection.
// Since rs2::align is aligning depth to some other stream, we need to make sure that the stream was not changed
//  after the call to wait_for_frames();
if (profile_changed(pipe.get_active_profile().get_streams(), profile.get_streams()))
{
    //If the profile was changed, update the align object, and also get the new device's depth scale
    profile = pipe.get_active_profile();
    align_to = find_stream_to_align(profile.get_streams());
    align = rs2::align(align_to);
    depth_scale = get_depth_scale(profile.get_device());
}
```

At this point the `align` object is valid and will be able to align depth frames with other frames.

```cpp
    //Get processed aligned frame
    auto processed = align.process(frameset);

    // Trying to get both color and aligned depth frames
    rs2::video_frame other_frame = processed.first_or_default(align_to);
    rs2::depth_frame aligned_depth_frame = processed.get_depth_frame();

    //If one of them is unavailable, continue iteration
    if (!aligned_depth_frame || !other_frame)
    {
        continue;
    }
```
Notice that the color frame is of type `rs2::video_frame` and the depth frame if of type `rs2::depth_frame` (which derives from `rs2::video_frame` and adds special depth related functionality).

After getting the two aligned color and depth frames, we call the `remove_background(..)` function to strip the background from the color image.
This is a simple function that performs a naive algorithm for background segmentation.
```cpp
    // Passing both frames to remove_background so it will "strip" the background
    // NOTE: in this example, we alter the buffer of the color frame, instead of copying it and altering the copy
    //  This behavior is not recommended in real application since the color frame could be used elsewhere
    remove_background(color_frame, aligned_depth_frame, depth_scale, depth_clipping_distance);

```

The  rest of the loop contains code that takes care of rendering and GUI controls. We will not elaborate on it. Let's go over `remove_background(..)` instead:

```cpp
void remove_background(rs2::video_frame& other_frame, const rs2::depth_frame& depth_frame, float depth_scale, float clipping_dist)
{
```

In the beginning of function, we take a pointer to the raw buffer of both frames, so that we could alter the color image (instead of creating a new buffer).

```cpp
    const uint16_t* p_depth_frame = reinterpret_cast<const uint16_t*>(depth_frame.get_data());
    uint8_t* p_other_frame = reinterpret_cast<uint8_t*>(const_cast<void*>(other_frame.get_data()));
```

Next, we go over each pixel of the frame.

```cpp
    //Using OpenMP to try to parallelise the loop
    #pragma omp parallel for schedule(dynamic)
    for (int y = 0; y < height; y++)
    {
        auto depth_pixel_index = y * width;
        for (int x = 0; x < width; x++, ++depth_pixel_index)
        {
```
Calculate the depth distance of that pixel:
```cpp
            // Get the depth value of the current pixel
            auto pixels_distance = depth_scale * p_depth_frame[depth_pixel_index];

```

If that distance is invalid (`pixels_distance <= 0.f`) or further away than the maximum distance that the user requested (`pixels_distance > clipping_dist`) then we should strip off that pixel from the resulted color image.
```cpp
            // Check if the depth value is invalid (<=0) or greater than the threashold
            if (pixels_distance <= 0.f || pixels_distance > clipping_dist)
            {
```
By "strip off" we mean that we simply paint that pixel with a gray color.

```cpp
                // Calculate the offset in other frame's buffer to current pixel
                auto offset = depth_pixel_index * other_bpp;

                // Set pixel to "background" color (0x999999)
                std::memset(&p_other_frame[offset], 0x99, other_bpp);
            }
        }
    }
```

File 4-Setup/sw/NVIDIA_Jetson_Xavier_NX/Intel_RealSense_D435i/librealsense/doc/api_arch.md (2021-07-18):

# API Architecture

RealSense API provides access to configuration, control and streaming of data from RealSense depth cameras. You can get started with the  basic functionality using the high level API, or get full control of all camera settings using the low level API:

1. [High-Level Pipeline API](#high-level-pipeline-api)  
The Pipeline interface configures the Intel® RealSense™ device with the best recommended settings and manages hardware resources and threading. It is accompanied by processing blocks, which abstract and simplify common processing of the camera raw data. Use this API when you require the Camera to work but do not need to fine tune the camera settings or control the streamings threads. Recommended for **Application Developers**.

2. [Low-Level Device API](#low-level-device-api)  
 The Low Level Device interface enables you to take direct control of the individual device sensors, fine tune all camera settings, and manage the streaming threads, time synchronization and spatial mapping. Recommended for **Advanced Researches**, **Framework and Tool Developers** and Developers in emerging fields like **VR/AR**.

## High-Level Pipeline API

The High-Level Pipeline API allows the developer to focus on the output of the camera, or selected processing blocks. The `pipeline` class selects the best camera settings, according to the output required by the application. It acquires and activates the camera, manages the different streams threads, and provides time synchronized frames of the active streams. The pipeline provides access to the low level device interface, which it encapsulates. Thus, the sensors information and fine tuning capabilities are still accessible to the application.   
The pipeline API is accompanied by the processing blocks, which provide tools to execute common image processing operations:

* **Synchronize** any set of different asynchronous streams with respect to hardware timestamps using the `syncer` class
* **Align** streams to a common viewport, using the `align` class. You can also use your own calibration data to align devices that were not otherwise calibrated.
* **Project** depth data into the 3D space using the `pointcloud` class. 
* Future releases will add **computer vision plugins** capabilities to the pipeline, for easy enriching available outputs based on camera streams. The pipeline makes sure all synchronization and alignment requirements of those plugins are met and takes care of threading and resource management.

## Low-Level Device API
Intel RealSense™ devices use sensors, some commonplace like a regular RGB camera and some more exotic like the D400 Stereo module or SR300 Structured-Light sensor:
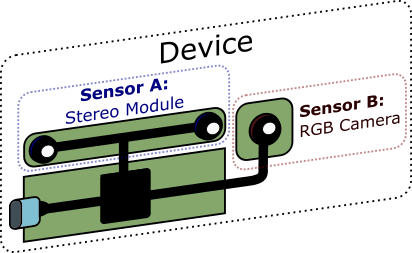
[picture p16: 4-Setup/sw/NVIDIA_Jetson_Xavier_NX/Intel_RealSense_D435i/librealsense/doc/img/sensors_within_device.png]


The Low-Level Device API provides you with the means to take direct control of the individual device sensors.   
* Each sensor has its own power management and control.  
* Different sensors can be safely used from different applications and can only influence each other indirectly.
* Each sensor can offer one or more streams of data (images, motion). Streams must be configured together and are usually dependent on each other. For example, D400 depth stream depends on infrared data, so the streams must be configured with a single resolution.
* All sensors provide streaming as minimal capability, but each individual sensor can be extended to offer additional functionality. For example, most video devices let the user configure a custom region of interest for the auto-exposure mechanism.
* Standard video sensors pass UVC / HID compliance and can be used without custom drivers.

Intel RealSense™ D400 stereo module offers **Advanced Mode** functionality, letting you control the various ASIC registers responsible for depth generation.  

The user of the device interface provides a callback to be invoked whenever new data frames become available. This callback runs immediately on the OS thread providing the best possible latency. 
The callback provides a frame with the relevant data type according to the stream, which produced the data. Data frames can be extended to offer the additional functionality relevant to their stream type. For example, video stream frame data includes image resolution and information how to parse the image raw buffer.

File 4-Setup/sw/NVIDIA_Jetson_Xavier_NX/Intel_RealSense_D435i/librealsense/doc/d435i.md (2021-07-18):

# D435i

The **Intel® RealSense™ D435i** is a depth camera which includes a [Bosch BMI055](https://www.bosch-sensortec.com/bst/products/all_products/bmi055) 6-axis inertial sensor in addition to the depth camera which measures linear accelerations and angular velocities. Each IMU data packet is timestamped using the depth sensor hardware clock to allow temporal synchronization between gyro, accel and depth frames.

## Should I use a T265 in addition to or instead of the D435i?

The [T265](./t265.md) is designed to produce high accuracy, low latency 6 degree of freedom position data without using any additional computational resources. It does not contain a depth camera but can be used in combination with any of the D400 series depth cameras (including the D435i).

## <a name="origin">Sensor origin and coordinate system</a>
The IMU sensor location and orientation relative to the depth sensors are conveniently embedded into the sensor's extrinsic data. In order to align and them with SDK-wide established [orientation convention](https://github.com/IntelRealSense/librealsense/wiki/Projection-in-RealSense-SDK-2.0#point-coordinates) using the depth sensor as coordinate system origin, each IMU sample is multiplied internally by the extrinsic matrix.

The resulting orientation angles and acceleration vectors share the coordinate system with the depth sensor.  
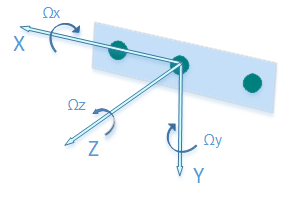
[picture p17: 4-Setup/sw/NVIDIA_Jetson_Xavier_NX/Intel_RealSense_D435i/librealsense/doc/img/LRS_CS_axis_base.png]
D400 Depth Sensor Orientation angles
  
1.  The positive x-axis points to the right.  
2.  The positive y-axis points down.  
3.  The positive z-axis points forward  

The coordinate system is also compatible with the [OpenCV pinhole camera model](https://docs.opencv.org/3.4.0/d9/d0c/group__calib3d.html)  

Note: The accelerometer is an intertial sensor and it measures [inertial force](https://www.merriam-webster.com/dictionary/inertial%20force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,the%20mass%20of%20the%20body). So when the camera is idle, the accelerometer doesn’t measure G-force, but rather the force that resists to G. The resisting force aims up to the ceiling, and according to the coordinate System the positive Y-axis looks “down” and therefore the actual reading (the white line) is -9.8

## <a name="imu_calibration">IMU calibration</a>
The D435i IMU sensor does not include internal calibration, which may manifest itself with non-zero angular velocities produced at idle mode and the gravity (accel) force measured being not equal to 9.80665.

A [complementary calibration tool](https://github.com/IntelRealSense/librealsense/tree/development/tools/rs-imu-calibration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) has been developed and published as part of the SDK.  

Running the calibration routine will calculate IMU intrinsics and store them on device's NVRAM for later use in SDK.

The depth<->IMU sensor extrinsic (rigid body transformation) is precalculated based on mechanical drawings and cannot be modified.
 
When initialized, the SDK will query the device for the existance of the IMU calibration data, and if present - apply it to the raw IMU samples produced by the device.

## Integration with the SDK
The following `librealsense` tools and demos are IMU ready:
 - `rs-capture` - 2D Visualization
 - `rs-enumerate-devices` - list the IMU and tracking profiles (FPS rates and formats).  
 - `rs-data-collect` - Store and serialize IMU in Excel-friendly csv format. The tool uses low-level sensor API to minimize software-imposed latencies. Useful for performance profiling.  
 - `realsense-viewer` - Provides 2D visualization of IMU data.

The IMU and data streams are fully compatible with SDK's embedded recorder utility.  

## API
The IMU is treated by the SDK like any other supported sensor. Therefore the sensor access and invocation API calls are similar to those of the depth/rgb sensors of D400 and SR300:

```cpp
rs2::pipeline pipe;

rs2::config cfg;
cfg.enable_stream(RS2_STREAM_GYRO);
cfg.enable_stream(RS2_STREAM_ACCEL);

pipe.start(cfg);

while (app) // Application still alive?
{
    rs2::frameset frameset = pipe.wait_for_frames();

    // Find and retrieve IMU data
    if (rs2::motion_frame accel_frame = frameset.first_or_default(RS2_STREAM_ACCEL))
    {
        rs2_vector accel_sample = accel_frame.get_motion_data();
        //std::cout << "Accel:" << accel_sample.x << ", " << accel_sample.y << ", " << accel_sample.z << std::endl;
        //...
    }

    if (rs2::motion_frame gyro_frame = frameset.first_or_default(RS2_STREAM_GYRO))
    {
        rs2_vector gyro_sample = gyro_frame.get_motion_data();
        //std::cout << "Gyro:" << gyro_sample.x << ", " << gyro_sample.y << ", " << gyro_sample.z << std::endl;
        //...
    }
}
```

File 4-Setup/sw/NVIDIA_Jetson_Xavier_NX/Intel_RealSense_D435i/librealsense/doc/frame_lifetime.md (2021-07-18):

# Frame Management

librealsense2 provides flexible model for frame management and synchronization. The document will overview frame memory management, passing frames between threads and synchronization. 

## API Overview

The core C++ abstraction when dealing is the `rs2::frame` class and the `rs2::device::start` method. All other management and synchronization primitives can be derived from those two APIs. 
```cpp
/**
 * Start passing frames into user provided callback
 * \param[in] callback   Stream callback, can be any callable object accepting rs2::frame
 */
template<class T>
void start(T callback) const;
```
Once you call start, the library will start dispatching new frames from selected device into the callback you provided. 
The callback will be invoked from the same thread handling the low-level IO ensuring minimal latency. Any object implementing `void operator()(rs2::frame)` can be used as a callback. In particular, you can pass an anonymous function (lambda with capture) as the frame callback:
```cpp
dev.start([](rs::frame f){
    std::cout << "This line be printed every frame!" << std::endl; 
}); 
```
As a side-note, `rs2::device::stop` will block until all pending callbacks return. This way within callback scope you can be sure the device object is available. 

## Frame Memory Management

`rs2::frame` is a smart reference to the underlying frame - as long as you hold ownership of the `rs2::frame` the underlying memory is exclusively yours and will not be modified or freed. 
* If no processing was necessary on the frame, `rs2::frame::get_data` will provide a direct pointer to the buffer provided by the underlying driver stack. No extra memory copies are performed in this case. 
* If some processing was required (for example, whenever you configure `RS2_FORMAT_RGB8` it is likely librealsense will do the conversion from `YUY` format internally) librealsense will store the processing output in an internal buffer, and `rs2::frame::get_data` will point to it. 
* You can extend the lifetime of the `rs2::frame` object by moving it out of the callback into some global, thread-safe, data structure. (See below) Moving `rs2::frame` does not involve a mem-copy of its content. 
* Except some initial stabilization period, librealsense ensures no heap allocations are being made when using frame callbacks. (This also applies to `rs2::frame_queue` but not to `rs2::syncer` primitive)
* If you are not releasing `rs2::frame` objects in less then the `1000 / fps` milliseconds, you will likely encounter frame drops. These events will be visible in the log, if you decrease the severity to DEBUG level. 

## Frames and Threads

Callbacks are invoked from an internal thread to minimize latency. If you have a lot of processing to do, or simply want to handle the frame in your main event loop, librealsense provides `rs2::frame_queue` primitive to move frames from one thread to another in a thread-safe fashion:
```cpp
rs2::frame_queue q;

dev.start([](rs2::frame f){
    q.enqueue(std::move(f)); // enqueue any new frames into q
});

while(true)
{
    rs2::frame f = q.wait_for_frame(); // wait until new frame is available and dequeue it
    // handle frames in the main event loop
}
```
Since `rs2::frame_queue` implements `operator()` you can also pass the queue directly to `start`:
```cpp
rs2::frame_queue q;
dev.start(q);
```
You could also have a separate queue for each stream type:
```cpp
rs2::frame_queue depth_q;
dev.start(RS2_STREAM_DEPTH, depth_q);
rs2::frame_queue ir_q;
dev.start(RS2_STREAM_INFRARED, ir_q);
```
This is particularly handy if you want to set-up different processing pipeline for each stream type. 

## Frame-Drops vs. Latency

There are two common types of applications of the streaming API:
* Those who need the most relevant data as soon as possible (low latency) 
* Those who want all the data, but don't mind waiting for it (low frame-drops)

librealsense provides some degree of control over this trade-off using `RS2_OPTION_FRAMES_QUEUE_SIZE` option. If you increase this number, your application will consume more memory and some frames might potentially wait in line more time, but frame drops will be less likely to happen. On the flip side, if you decrease this number, you will get frames faster, but if new frame will arrive while you are busy it will get dropped. 

## Frame Syncer

Often the input to an image processing application is not simply a frame, but rather a coherent set of frames, preferably taken at the same time. librealsense provides `rs2::syncer` primitive to help with this problem:
```cpp
auto sync = dev.create_syncer(); // syncronization algorithm can be device specific
dev.start(sync);
while(true)
{
    auto frameset = sync.wait_for_frames(); // wait for a coherent set of frames
    for (auto&& frame : frameset)
    {
        // handle frame
    }
}
```
* In general, there is no guarantee on the quality of the temporal synchronization. 
* If hardware timestamps are available, librealsense will take advantage of them.
* If the device supports hardware sync, librealsense will try to take advantage of it if it's enabled, but will not implicitly enable it. 
* You can also use a single `rs2::syncer` to synchronize between devices, assuming it makes sense.

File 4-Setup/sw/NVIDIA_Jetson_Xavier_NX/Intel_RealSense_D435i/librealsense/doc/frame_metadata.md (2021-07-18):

# Frame Metadata

Frame metadata is a set of parameters (or attributes) that provide a snapshot of the sensor configuration and/or system state present during the frame's generation.
The attributes are recalculated and updated on per-frame basis.
`librealsense2` supports querying a set predefined attributes as part of the frame data available to the end-user.
In this explanatory we will overview
- The Design and implementation of frame metadata in `librealsense2`
- The Metadata support by Intel® RealSense™ devices

## Software Design and Implementation
The library's approach on metadata is that any piece of data that provides an unique frame-related info is a potential attribute. Therefore `librealsense2` does not limit itself to hardware-originated data, but establishes an infrastructure to capture and encapsulate  software-originated attributes as well.

The low-level design and implementation follows those two guidelines:
- All the attributes shall be prepared, packed and distributed as an integral part of `rs2_frame` object.
- A metadata handler class is the basic execution unit responsible to parse and provide a single attribute.

# Metadata Registration
When a new device is recognized by `librealsense2` the internal resources for its management, including UVC endpoint classes, are allocated. The UVC endpoints perform registration for the specific metadata attributes. In the process a dedicated metadata parser class will be assigned to handle the actual job of de-serializing and validating an attribute.    
Note that each metadata attribute requires an explicit parser, and querying an unregistered attribute will result in an appropriate exception raised by the library.  
With the metadata handlers in place, the inbound frames for the specific endpoint can be queried for the requested attributes.  

The metadata registration flow is summarized in the following diagram*:  
>**Note** the diagrams present the high-level design. The actual implementation may differ.  

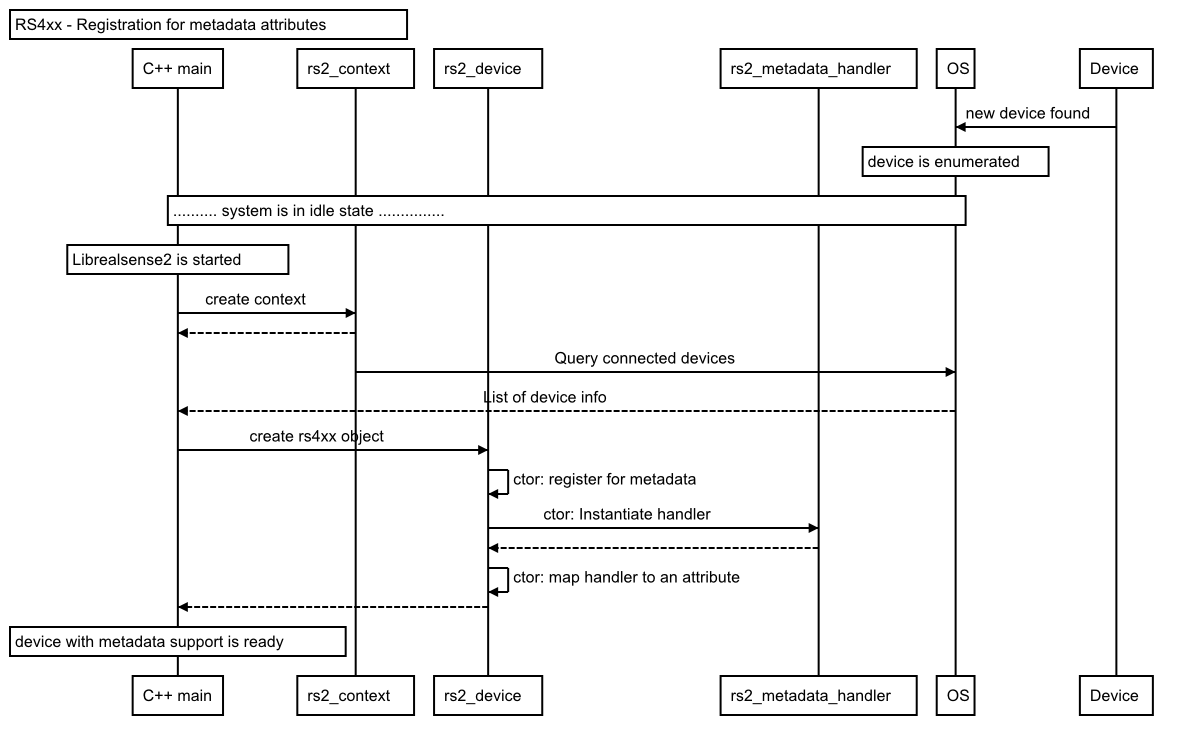
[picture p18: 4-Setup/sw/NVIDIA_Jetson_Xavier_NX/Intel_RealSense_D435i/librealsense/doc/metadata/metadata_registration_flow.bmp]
register for metadata


# Metadata Acquisition
When a new frame is received by Host, `librealsense2` backend is responsible to process and attach the metadata attributes.  
For hardware-generated attributes, the backend will checks whether the metadata payload is valid. If positive, the metadata payload will be stored along with the pixels data in `rs2_frame` object. Since querying the attributes is optional and in many cases will not be requested, the payload is stored as raw data, and the library waits for the appropriate API calls to do the actual attribute parsing.  
The backend is also responsible to prepare and attach the software-generated attributes to the frame data. And contrary to hardware-originated data, those attributes will be generated to all frames.

Metadata attributes propagation from the library to the user code is described in the following diagram:  
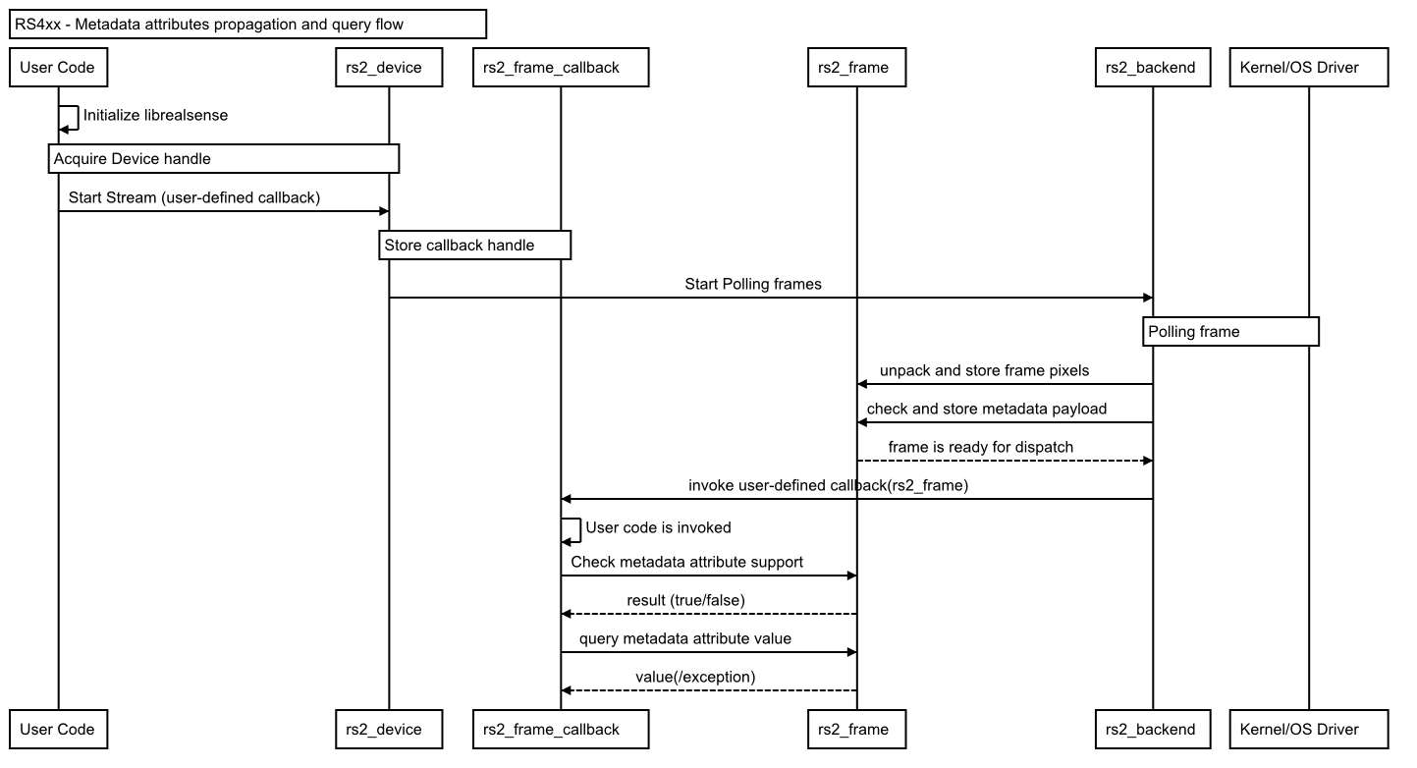
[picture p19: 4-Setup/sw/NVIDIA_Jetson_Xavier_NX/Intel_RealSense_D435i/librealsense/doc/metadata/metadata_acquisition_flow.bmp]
metadata acquisition


## Metadata Query API
`librealsense2` introduces two functions into its public API to query metadata attributes:
```cpp
/**
* determine device metadata
* \param[in] frame      frame handle returned from a callback
* \param[in]            the metadata attribute to check for support
* \return               true if device has this metadata
*/
int rs2_supports_frame_metadata(const rs2_frame* frame, rs2_frame_metadata frame_metadata, rs2_error** error);
```
verifies that the hardware and software-applied preconditions for metadata parsing are met:
- the attribute was registered for retrieval
- metadata payload is valid*
- the specific attribute is included in the payload data blocks*
> **Note** * applicable for hardware-originated metadata payload.  

```cpp
/**
* retrieve metadata from frame handle
* \param[in] frame      handle returned from a callback
* \param[in] frame_metadata  the rs2_frame_metadata whose latest frame we are interested in
* \return            the metadata value
**/
 rs2_metadata_t rs2_get_frame_metadata(const rs2_frame* frame, rs2_frame_metadata frame_metadata, rs2_error** error);
```
will invoke the metadata parser to read the actual value from metadata payload. In case the attribute's origin is other than the payload, such as Auto-Exposure for Fisheye stream, then its value will be calculated internally by librealsense2.  

# Librealsense2 API for Metadata
The envisaged mode of querying metadata attribute is `check-then-query`
```cpp
  rs2_metadata_t val = 0;
  ...
  if (rs2_supports_frame_metadata(.., attribute,...))
     val = rs2_get_frame_metadata(.., attribute,...)
 ```
Calling __*rs2_get_frame_metadata*__ without testing for attribute support may result in `librealsense2` generating an exception. This is a design decision consistent with the error-handling model employed by librealsense2.  

## Employing metadata attributes in demos
The samples that demonstrate querying and retrieval of metadata are `rs-save-to-disk` and `rs-config-ui`.
 - `rs-save-to-disk` saves the metadata attributes available for each stream into a comma-separated text file. For instance, for the Depth stream the possible [output ](metadata/rs-save-to-disk-output-DEPTH-metadata.csv) is:  

Stream |Depth
:-----:|------:|
Metadata Attribute|  Value
FRAME_COUNTER |41
FRAME_TIMESTAMP|179708225
SENSOR_TIMESTAMP|179671458
ACTUAL_EXPOSURE|6951
GAIN_LEVEL|16
AUTO_EXPOSURE|1  
TIME_OF_ARRIVAL|1523871918775
BACKEND_TIMESTAMP|1523871918741
ACTUAL_FPS|30

 - `rs-config-ui` includes a checkbox in the upper-right corner of  stream's canvas, clicking on which will bring up an overlay window with the metadata attributes available.  

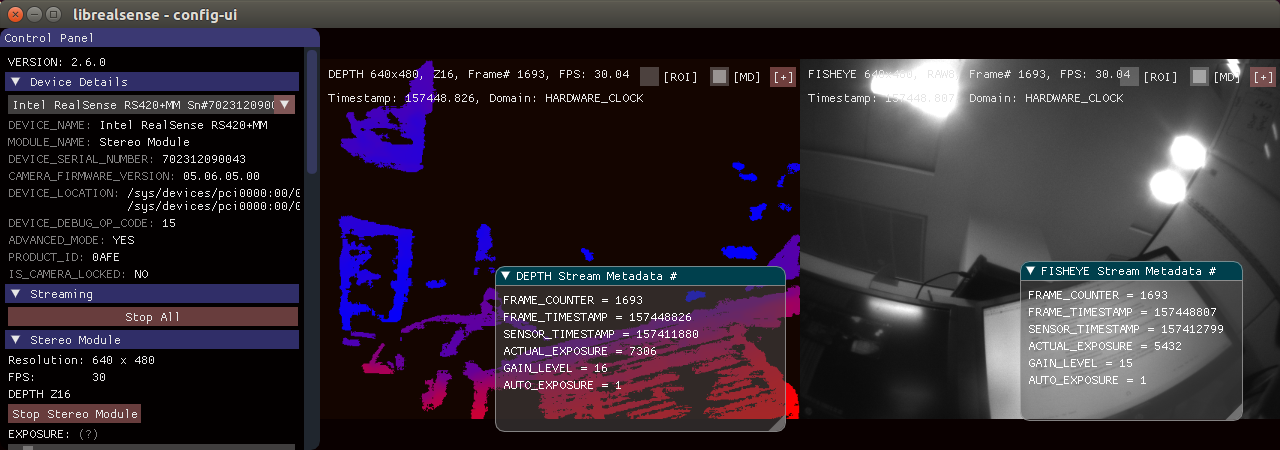
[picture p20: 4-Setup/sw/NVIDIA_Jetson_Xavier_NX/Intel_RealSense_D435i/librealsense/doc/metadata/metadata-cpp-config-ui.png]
Demo Presenting metadata attributes


# Metadata Support for Intel® RealSense™ devices
In order for `librealsense2` to get access for device-generated attributes the following system preconditions shall be met:
- OS shall support metadata provision - for Linux the specific kernel patches shall be applied.  
- Device firmware shall declare and implement metadata attributes payload.

## OS support
***Linux OS*** -  the standard Linux UVC driver does not provide metadata support.
`librealsense2` package includes metadata patch for `uvcvideo` kernel object. The patches are intended to be deployed with Ubuntu 14, 16.01/02 LTS with kernel versions 4.4, 4.8 and 4.10, and are applied as part of Linux backend installation . See [Linux installation-guide](./installation.md) for more details.
The patches were also successfully ported to Yocto-based distribution and made available for Yocto Reference Kit based on Poky 2.1.2 with kernel version 4.4.26.

***Windows OS*** - Metadata extraction is supported by Microsoft starting with Windows10. Check [Windows installation  guide](./installation_windows.md) for details.  

## Metadata attributes in RS400 Devices
The device firmware implements a custom metadata payload compatible with [Microsoft Extensions for UVC ](https://docs.microsoft.com/en-us/windows-hardware/drivers/stream/uvc-extensions-1-5) spec, and emits metadata attributes in the frame payload header.

The custom payload comprise of several data chunks ("C" structs) with multiple attributes each. The chunks are categorized as  `calibration/configuration/capture/status`.  
During streaming the chunks are arranged into ordered sets. For instance, given attributes chunks named `a,b,c,d,e,f,g`, the possible sets could be `{a,b,c,d}`, `{a,f,g,d}`,`{d,e,f,g}`.  The design requires ,though, that the *essential frame attributes, such as Frame Number and Timestamp shall be included in all configured sets*, to allow a consistent track of the frames arrived.  

During the regular operation course the firmware internal state machine decides which attributes set to generate for the current frame. For instance, the first frames will be dispatched with `configuration/calibration` payloads, while the rest will carry the `capture` attributes.  
From the user's perspective it means that a properly registered metadata attribute may still not be available for some frames, as metadata generation is governed by firmware design.

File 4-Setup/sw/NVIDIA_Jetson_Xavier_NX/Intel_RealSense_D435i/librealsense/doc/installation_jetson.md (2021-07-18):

# NVidia Jetson Devices

**NOTE**: See [support-matrix.md](./support-matrix.md) to learn more about Jetson support for RealSense devices.

> Check out [www.jetsonhacks.com](http://www.jetsonhacks.com/) for great content on everything Jetson! (not affiliated with Intel RealSense)

## Getting started

1. **Prerequisites:**

  * NVIDIA® **Jetson Nano™**, **Jetson TX2™** and **Jetson AGX Xavier™** board (may also work on other Jetson devices)
  * RealSense **D415**, **D435**, **D435i**, **D455**, **L515**, **SR300** and **T265** Camera devices.

2. **Establish Developer's Environment**
Follow [official instructions](https://developer.nvidia.com/embedded/learn/getting-started-jetson) to get your board ready. This guide will assume you are using **NVIDIA® L4T Ubuntu 16.04/18.04** image. Note that in most cases it is necessary to install a toll named "SDK Manager" to flash and install **Jetson** boards with both the L4T (Linux for Tegra) and NVIDIA-specific software packages (CUDA, Tensor Flow, AI, etc.)
For **Jetson Nano™** we strongly recommend enabling the Barrel Jack connector for extra power (See [jetsonhacks.com/jetson-nano-use-more-power/](https://www.jetsonhacks.com/2019/04/10/jetson-nano-use-more-power/) to learn how)

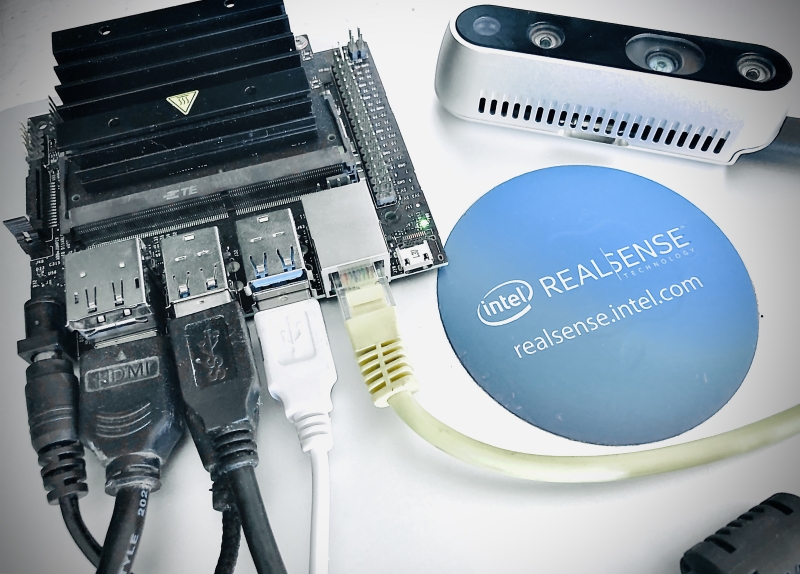
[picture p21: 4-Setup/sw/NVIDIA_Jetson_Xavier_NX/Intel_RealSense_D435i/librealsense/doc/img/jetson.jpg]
Jetson Nano
  

3. **Choose LibRealSense SDK Backend**  
Librealsense2 SDK supports two API for communication with RealSense device on Linux platforms:
    1. Linux native kernel drivers for UVC, USB and HID (Video4Linux and IIO respectively)
    2. Using `RSUSB` - user-space implementation of the UVC and HID data protocols, encapsulated and activated by selecting the SDK's `-DFORCE_RSUSB_BACKEND` flag (a.k.a. `-DFORCE_LIBUVC` with SDK versions prior to v.2.30).  

  When the second method is selected Librealsense2 communicates with the devices using the standard USB driver, while the higher-level protocols  (UVC/HID) stacks are compiled directly into the SDK.
  Currently the two interfaces are mutually-exclusive, thus the choice taken during the SDK configuration stage (CMakes) predefines the selected backend API.

  As a general rule it is recommended to use the native kernel drivers, especially in production environment.
The second method augments the native installation and allows for a fully-functional SDK deployment at the expense of certain performance and functional limitations (e.g. multi-cam).
The list of requirements for the second method comprise of a basic USB driver and GCC compiler, thus making it attractive for prototyping and demos in new/previously-unsupported environments.

  If that's the case, what is the dilemma?

  In order to enable the full capabilities of RealSense devices certain modifications in the kernel (driver) modules shall be applied, such as support of Depth-related streaming formats and access to per-frame metadata attributes. There is a small set of generic kernel changes that are mostly retrofitted with more advanced kernel versions aimed at improving the overall drivers stability.

  NVIDIA's L4T delivers an Ubuntu-based distribution with a customized kernel based on version 4.9. The way the kernel is configured and deployed is different from a desktop Ubuntu image with two notable differences being the list of kernel modules included in default configuration and the way a new image is flashed.

  And while it is possible to rebuild and flash a new kernel image the procedure can be perceived as challenging and shall be performed with extra caution.
This guide comes with a script that allows to modify the kernel modules with Librealsense2-related patches without replacing the kernel image. The script has been verified with **Jetson AGX Xavier™** board using L4T versions 4.2.3, 4.3 and 4.4 (Sept 2020). Scroll to the end of the guide for details.

4. **Install with Debian Packages**  
Note that this method provides binary installation compiled using the `-DFORCE_RSUSB_BACKEND=true` option elaborated above.

  1. Register the server's public key:  
  ```
  sudo apt-key adv --keyserver keys.gnupg.net --recv-key F6E65AC044F831AC80A06380C8B3A55A6F3EFCDE || sudo apt-key adv --keyserver hkp://keyserver.ubuntu.com:80 --recv-key F6E65AC044F831AC80A06380C8B3A55A6F3EFCDE
  ```

    > In case the public key cannot be retrieved, check and specify proxy settings: `export http_proxy="http://<proxy>:<port>"`, and rerun the command. See additional methods in the following [link](https://unix.stackexchange.com/questions/361213/unable-to-add-gpg-key-with-apt-key-behind-a-proxy).  

  2. Add the server to the list of repositories:

  * Ubuntu 16:  
  ```
  sudo add-apt-repository "deb https://librealsense.intel.com/Debian/apt-repo xenial main" -u
  ```

  * Ubuntu 18:
  ```
  sudo add-apt-repository "deb https://librealsense.intel.com/Debian/apt-repo bionic main" -u
  ```

  3. Install the SDK:
  ```
  sudo apt-get install librealsense2-utils
  sudo apt-get install librealsense2-dev
  ```
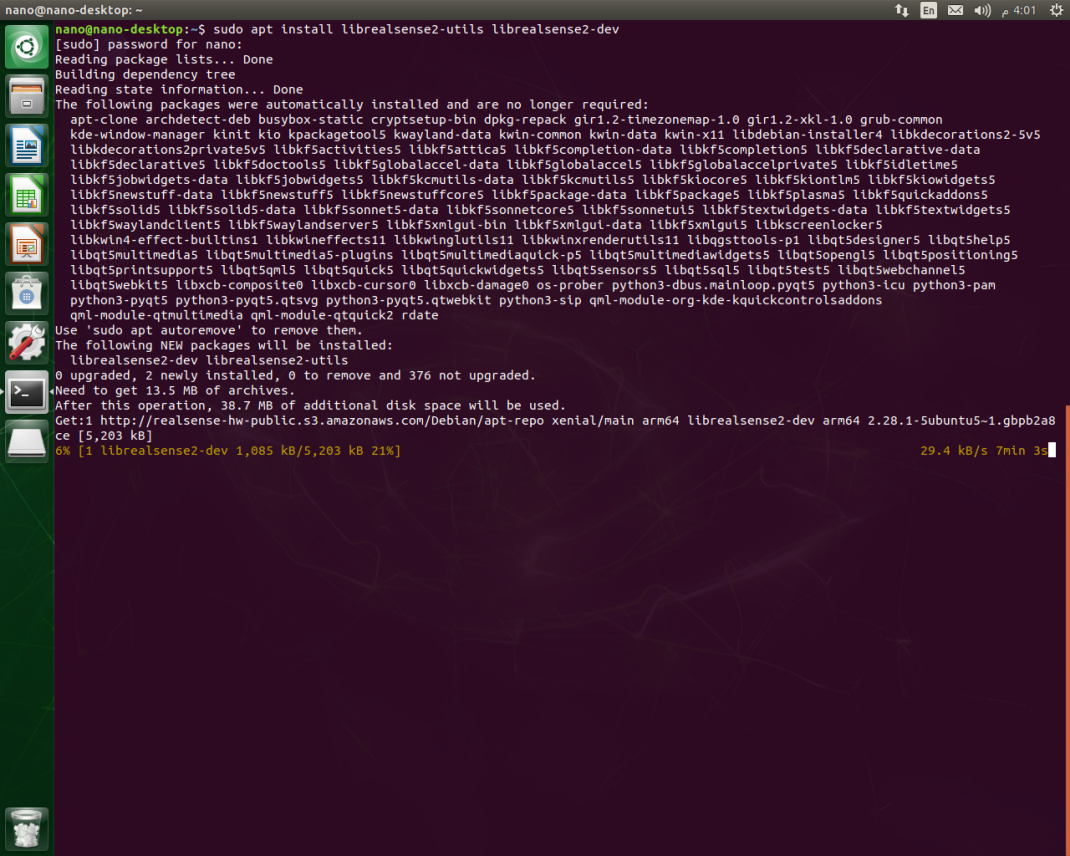
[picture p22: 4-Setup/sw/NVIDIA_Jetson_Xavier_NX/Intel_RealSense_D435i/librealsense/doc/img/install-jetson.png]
installation
  

  > With `librealsense2-dev` package installed, you can compile an application with **librealsense** using `g++ -std=c++11 filename.cpp -lrealsense2` or an IDE of your choice. To get started with RealSense using **CMake** check out [librealsense/examples/cmake](https://github.com/IntelRealSense/librealsense/tree/master/examples/cmake)

  4. Reconnect the RealSense device and run: `realsense-viewer` to verify the installation:

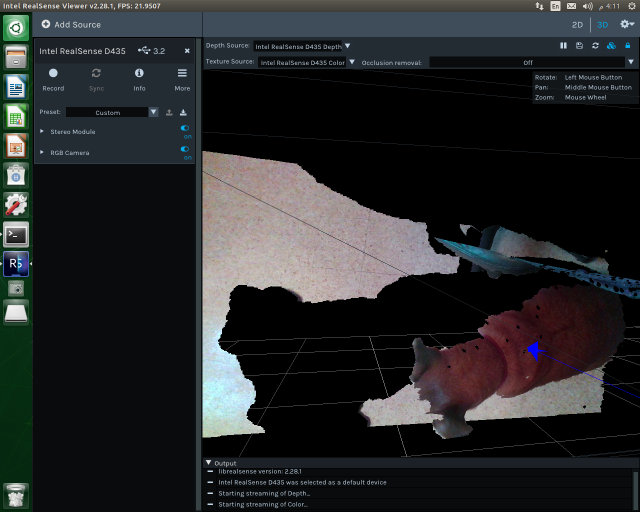
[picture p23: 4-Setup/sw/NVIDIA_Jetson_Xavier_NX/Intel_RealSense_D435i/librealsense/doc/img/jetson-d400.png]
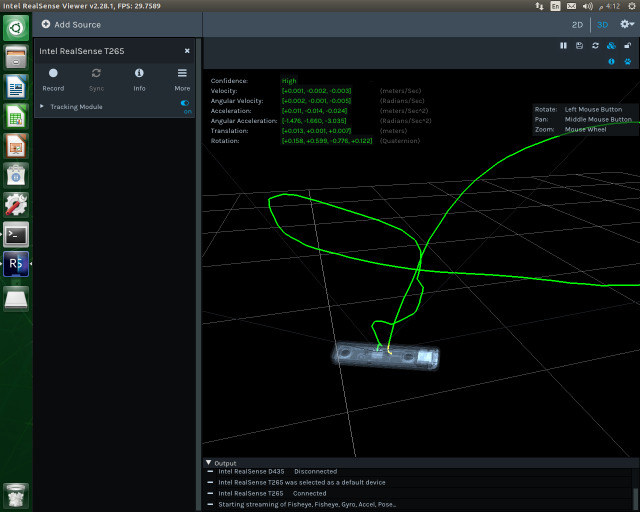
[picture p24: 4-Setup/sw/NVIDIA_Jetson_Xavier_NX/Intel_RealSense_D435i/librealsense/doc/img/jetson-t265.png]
t265
   

  You can also double-TAB after typing `rs-` to see the full list of SDK examples.
  
## Building from Source using RSUSB Backend

**Use the RSUSB backend without the kernel patching**

  * In order to build the SDK using the `RSUSB` method and avoid the kernel patching procedure, please refer to [libuvc_installation.sh](https://github.com/IntelRealSense/librealsense/blob/master/scripts/libuvc_installation.sh) script for details. If you have CUDA dev-kit installed, don't forget to add `-DBUILD_WITH_CUDA=true` for optimal performance.
    
 ## Building from Source using Native Backend
 
 **Use the V4L Native backend by applying the kernel patching**
 
   The method was verified with **Jetson AGX** boards with JetPack **4.2.3**[L4T 32.2.1,32.2.3], **4.3**[L4T 32.3.1] and **4.4**[L4T 32.4.3].
   
   The medhoe has not yet been verified on the **Jetson Nano** board.
  
  * **Prerequisite**
  
    * Verify the board type and Jetpack versions compatibility.  
    * Verify internet connection.  
    * Verify the available space on flash, the patching process requires **~2.5Gb** free space  
       >df -h
        
    * Configure the Jetson Board into Max power mode (desktop -> see the upper right corner)  
    * Disconnect attached USB/UVC cameras (if any).  
     
  * **Build and Patch Kernel Modules for Jetson L4T** 
  
    1. Navigate to the root of libreansense2 directory.  
    2. Run the script (note the ending characters - `L4T`)  
    ```
    ./scripts/patch-realsense-ubuntu-L4T.sh  
    ```
    * The script will run for about 30 minutes depending on internet speed and perform the following tasks:  
    
      a. Fetch the kernel source trees required to build the kernel and its modules.  
      b. Apply Librealsense-specific kernel patches and build the modified kernel modules.  
      c. Try to insert the modules into the kernel.  
      
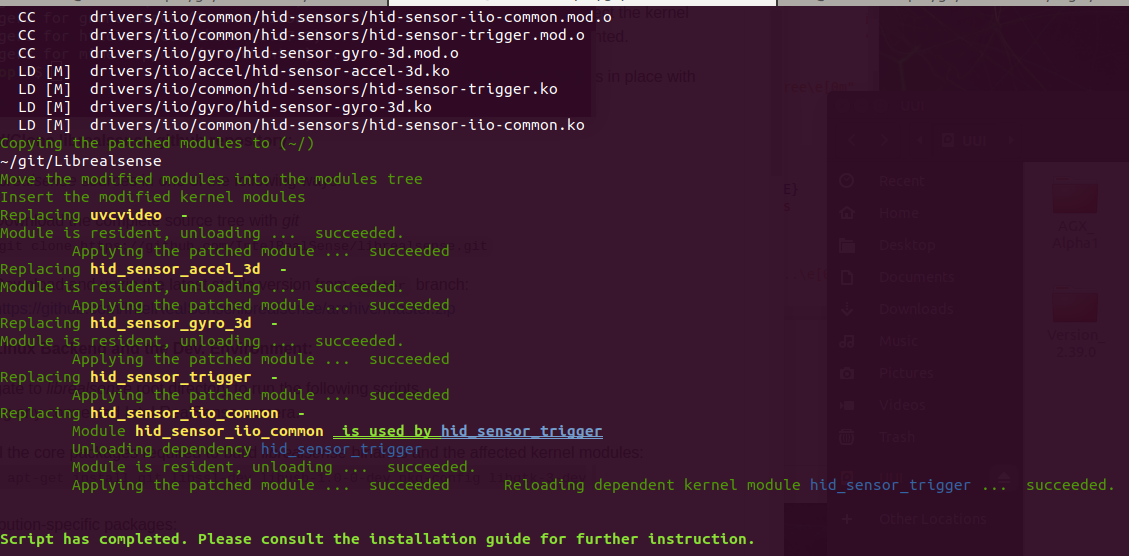
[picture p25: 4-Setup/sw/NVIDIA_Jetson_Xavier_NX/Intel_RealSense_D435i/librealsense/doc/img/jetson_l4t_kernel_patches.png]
    

  * **Build librealsense2 SDK**  
  
    1. Navigate to the SDK's root directory.  
    2. Follow the [Ubuntu installation guide](./installation.md) to install the missing components and configuration items:  
    ```
    sudo apt-get install git libssl-dev libusb-1.0-0-dev pkg-config libgtk-3-dev -y
    ./scripts/setup_udev_rules.sh  
    mkdir build && cd build  
    cmake .. -DBUILD_EXAMPLES=true -DCMAKE_BUILD_TYPE=release -DFORCE_RSUSB_BACKEND=false -DBUILD_WITH_CUDA=true && make -j$(($(nproc)-1)) && sudo make install
    ```
       The CMAKE `-DBUILD_WITH_CUDA=true` flag assumes CUDA modules are installed. If not, please reconnect the board to the Ubuntu Host PC and use NVIDIA `SDK Manager` tool to install the missing components.

  * **Connect Realsense Device, run `realsense-viewer` and inspect the results**
  
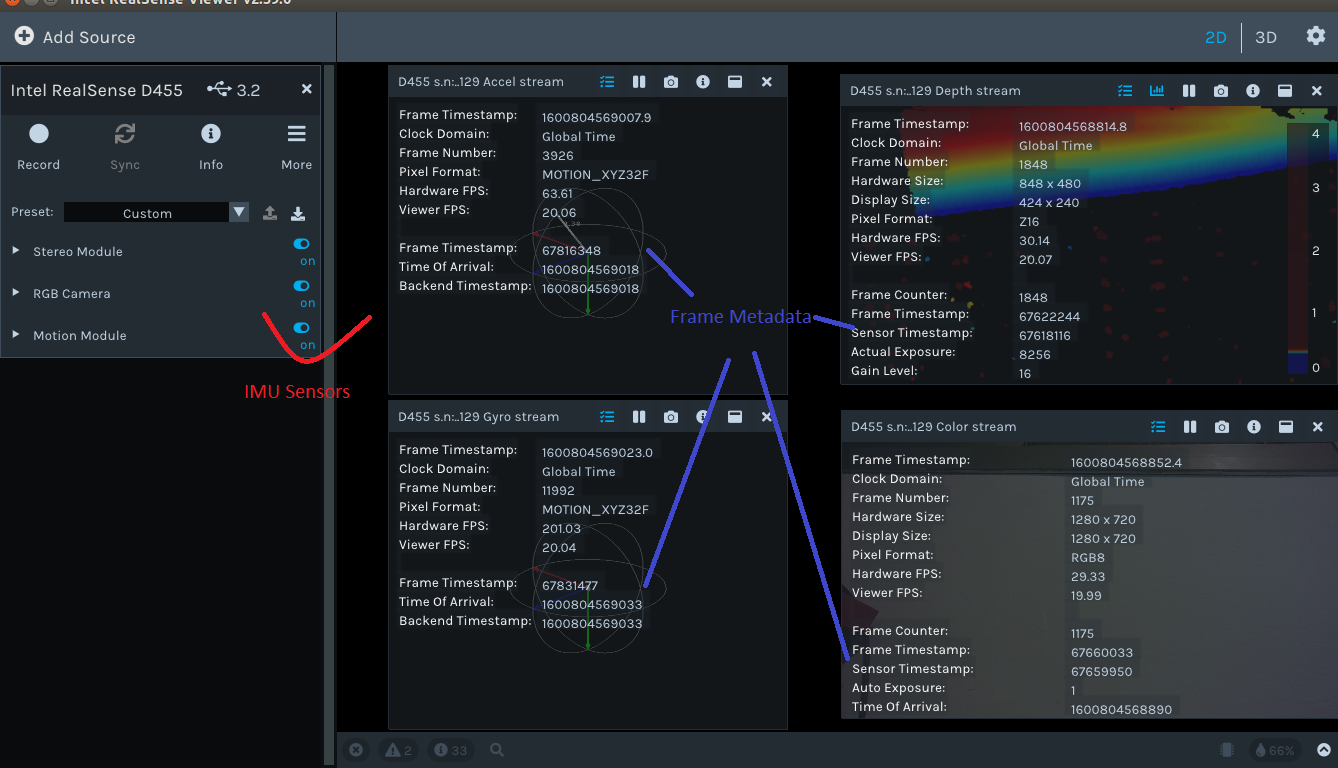
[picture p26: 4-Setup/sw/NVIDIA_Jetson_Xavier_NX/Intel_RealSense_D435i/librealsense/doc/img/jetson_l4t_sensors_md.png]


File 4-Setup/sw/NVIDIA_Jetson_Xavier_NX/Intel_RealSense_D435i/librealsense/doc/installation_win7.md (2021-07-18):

# Windows 7 Installation

> **Note:** Intel RealSense products are being regularly validated and receive official support for Windows 10 and Linux eco-systems. Not all product features are enabled on Windows 7. 

> We are constantly expanding the list of supported platforms, devices and features based on customer and community feedback. If your use case is not yet covered, please open [a new issue](https://github.com/IntelRealSense/librealsense/issues/new)

## Getting Started

1. Download [Intel RealSense SDK Installer for Windows 7](https://github.com/IntelRealSense/librealsense/releases/download/v2.16.1/Intel.RealSense.SDK.Win7.exe)
2. Connect the camera (the device must be connected to install the driver)
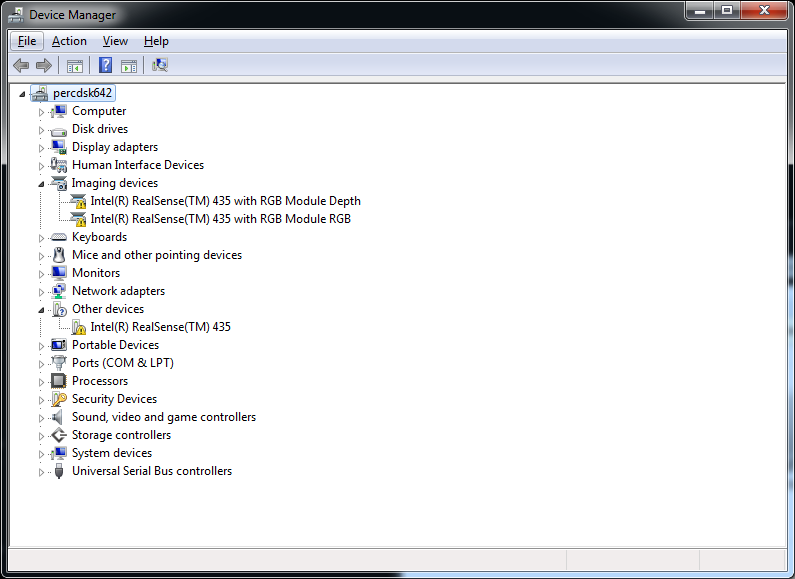
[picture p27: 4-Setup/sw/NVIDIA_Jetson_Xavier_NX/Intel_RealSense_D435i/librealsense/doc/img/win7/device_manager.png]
dev_man
3. Check the device manager:<br /><br />
> Out of the box Windows 7 will not recognize the D4xx cameras using the inbox driver. 
4. Run the installer and make sure to check **Win7 Drivers**:<br/>
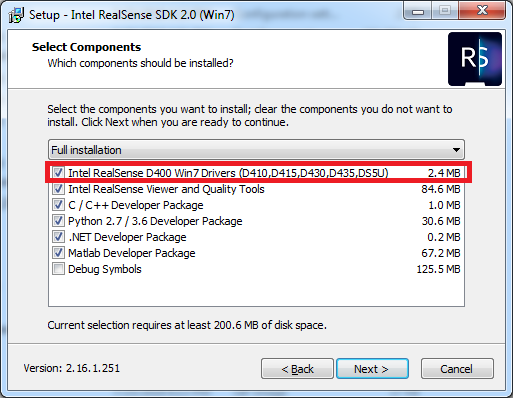
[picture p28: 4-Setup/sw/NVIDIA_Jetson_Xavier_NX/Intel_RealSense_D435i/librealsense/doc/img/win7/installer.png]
install

5. The installer will prompt to install the driver. This is a one-time step:<br/>
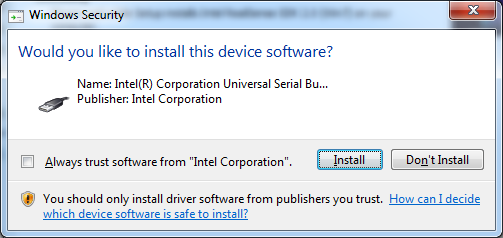
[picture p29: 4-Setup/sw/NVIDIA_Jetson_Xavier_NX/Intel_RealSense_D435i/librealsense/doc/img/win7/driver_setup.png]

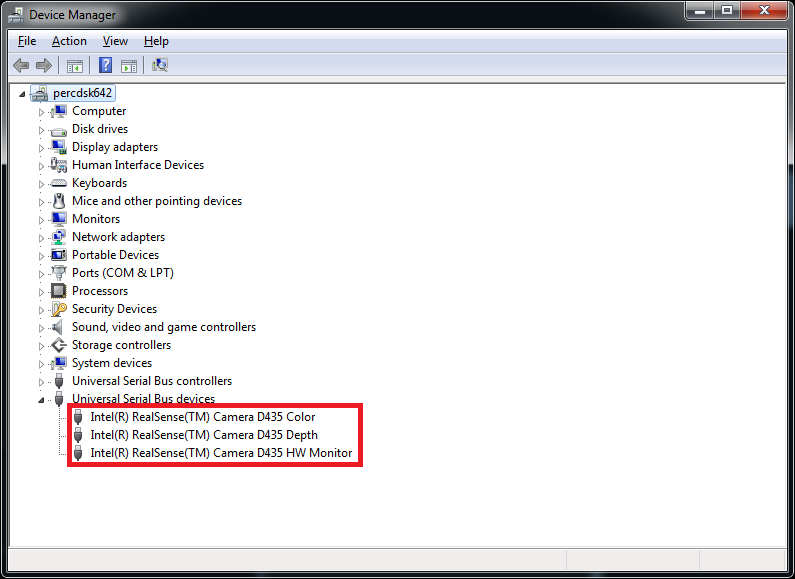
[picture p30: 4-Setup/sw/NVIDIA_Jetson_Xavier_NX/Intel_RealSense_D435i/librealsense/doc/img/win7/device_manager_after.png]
after


## Supported Devices:
1. Intel(R) RealSense(TM) D410 Module
2. Intel(R) RealSense(TM) D415 Camera
3. Intel(R) RealSense(TM) D430 Module
4. Intel(R) RealSense(TM) D435 Camera

## Known Limitations:
1. Multiple cameras are likely not to work at the moment (not validated)

## Building from Source
The binaries supporting Win7 differ from ones supporting Win10. When building on Win7, CMake will automatically generate binaries for Win7. 
You can also build for Win7 from Win10 by adding `-DFORCE_WINUSB_UVC=true` to CMake flags.
Signed drivers are still required when building from source (can be extracted from the Win7 installer and freely redistributed)

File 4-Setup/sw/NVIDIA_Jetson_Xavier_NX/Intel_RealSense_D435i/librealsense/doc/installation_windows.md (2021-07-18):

# Windows 8.1 & Windows 10 Installation

**Note:** Due to the USB 3.0 translation layer between native hardware and virtual machine, the librealsense team does not recommend or support installation in a VM.

librealsense shall be built on Windows using [CMake v3.8+](https://cmake.org/download/) and Visual Studio 2015 / 2017:  
(MSVC2013 and older are not fully compatible with the C++11 feature-set).
<a name="cmake_snapshot_win">
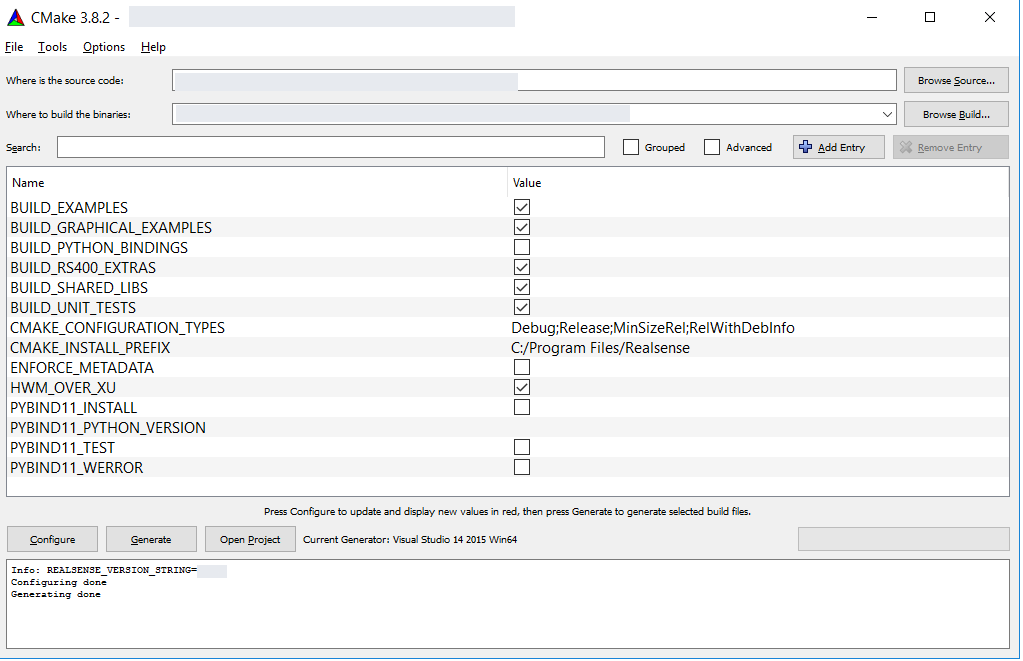
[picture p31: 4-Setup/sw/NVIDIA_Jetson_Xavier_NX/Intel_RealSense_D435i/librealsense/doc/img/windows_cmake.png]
Windows CMake
   
</a>
![link text][Win_cmake_image]

Don't forget to check `BUILD_EXAMPLES` if you wish to use librealsense samples.

## Windows 8.1:
When working on Windows 8.1, make sure you have [KB3075872](https://support.microsoft.com/en-us/kb/3075872) and [KB2919355](https://support.microsoft.com/en-us/kb/2919355) installed. These patches are addressing issues specific to 8.1 video drivers, that were later resolved in Windows 10.

## Enabling metadata on Windows
Metadata attributes is an advanced capability provided by librealsense.
Read more on this feature in [link](./frame_metadata.md).  
Follow the instructions to enable metadata generation:  

Prerequisites:
- Windows 10 with administrator login.
- WinSDK ver 10 (10.0.15063) or later.

#### Installation:
- Verify OS version:
 - Run `winver` command from desktop/terminal - "Version 1607" or later is expected.  
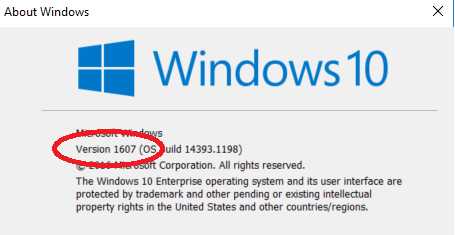
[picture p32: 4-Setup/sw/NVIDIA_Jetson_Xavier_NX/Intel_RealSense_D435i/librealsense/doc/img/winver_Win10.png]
winver
 

- Install WinSDK ver10:
 - Navigate to "Control Panel" -> "Programs and Features"
 - Double-click on "Microsoft Visual Studio" and select "Modify"
 - Check that SDK version 10.0.10586 or later is present, install if needed:
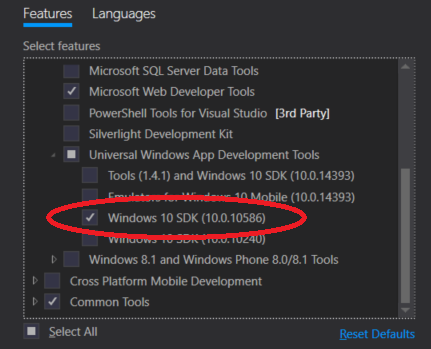
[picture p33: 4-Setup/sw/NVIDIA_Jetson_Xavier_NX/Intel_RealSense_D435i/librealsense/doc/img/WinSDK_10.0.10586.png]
winsdk
 

 ##### Update Registry:
  - Windows OS requires a dedicated registry entry to be present for each unique video device in order to provide metadata.  

  ###### Use automation script:
  - Launch Windows `Powershell` tool as *_Admin_* and navigate to the script directory
  - Run the following:  
    `PS > .\realsense_metadata_win10.ps1 <optional:operation>`  
    The supported parameters are
    - `-op install` adds registry keys for connected Intel Realsense devices
    - `-op install_all` adds keys for all RealSense devices logged in the registry
    - `-op remove` removes registry keys for connected Intel Realsense devices
    - `-op remove_all` removes the keys for all RealSense devices logged in the registry
    Running the script without arguments will is similar to `-op install` operation.  

  -  If you receive `... cannot be
loaded because running scripts is disabled on this system` message, run:

    `PS > Set-ExecutionPolicy RemoteSigned` , answer `Y` and then rerun the script

    **Important** - The registry keys are device-unique. Therefore, __*the script must be executed each time a new RealSense device is attached*__ to the PC.

  ###### Modifying the registry manually
  In case the script cannot be executed due to permissions, or other Host-related issue please follow the instructions to  update the registry manually:
  - Connect Intel® RealSense™ device to the host
  - Navigate to "Control Panel" -> "Device Manager"
  - Browse for Intel® RealSense™ devices
  - Select the first device from the list, e.g. `Intel® RealSense™ Camera SR300 Depth` (Step 1)
  - Find device's path (Step 2) and the additional interfaces (Step 3)

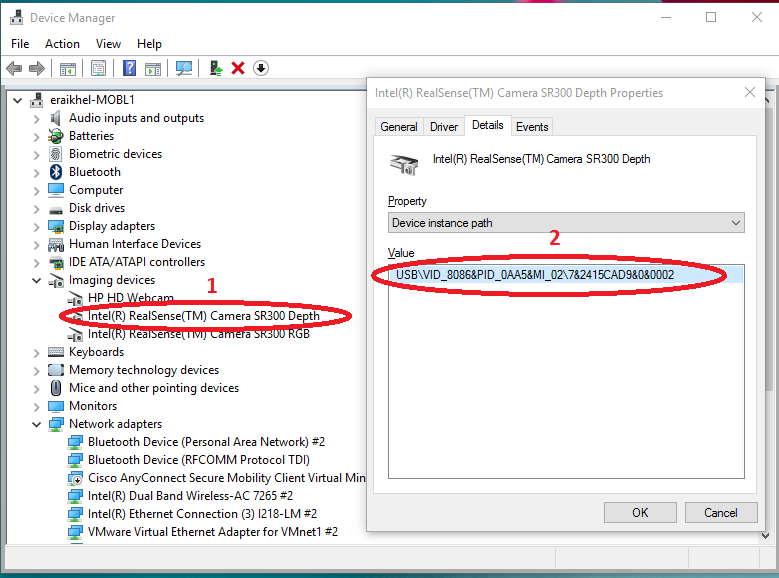
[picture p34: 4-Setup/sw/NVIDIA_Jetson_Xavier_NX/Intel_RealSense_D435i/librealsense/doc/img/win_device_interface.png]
win_dev_master_interface
    
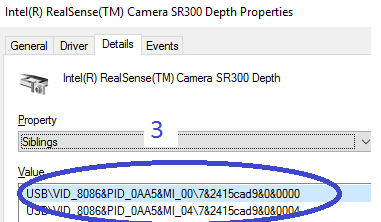
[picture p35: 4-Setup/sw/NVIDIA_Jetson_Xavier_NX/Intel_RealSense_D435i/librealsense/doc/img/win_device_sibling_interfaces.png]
win_dev_master_interface
    

- Modifying the Windows Registry:
  - For each interface found (Steps 2 and 3) perform
    - Using Registry Editing tool such as "regedit" navigate to	`HKLM\SYSTEM\CurrentControlSet\Control\DeviceClasses\{e5323777-f976-4f5b-9b55-b94699c46e44}` branch.
    - Browse into the subdirectory with the name identical to the `Device instance path` obtained from the previous step
      - Expand the entry into `#GLOBAL` -> `Device Parameters`
      - Add `DWORD 32bit` value named `MetadataBufferSizeInKB0` with value 5.
      - Add an additional `DWORD 32bit` value named `MetadataBufferSizeInKB1` with value 5 for RS400 device zero interface `##?##USB#VID_8086&PID... **MI_00**..`
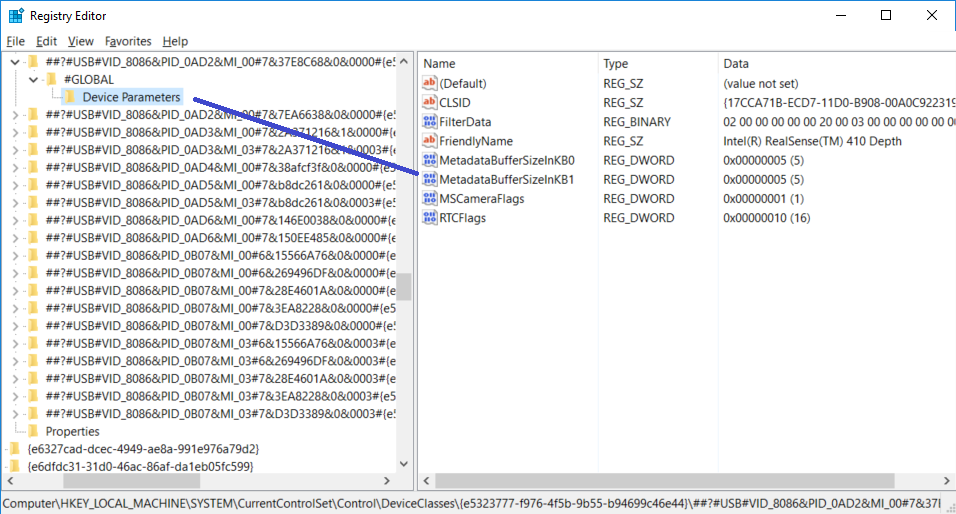
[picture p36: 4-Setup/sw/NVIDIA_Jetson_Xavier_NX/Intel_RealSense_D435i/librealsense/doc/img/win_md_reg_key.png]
win_md_reg_key
        

    - Repeat the previous step for   
      `HKLM\SYSTEM\CurrentControlSet\Control\DeviceClasses\{65E8773D-8F56-11D0-A3B9-00A0C9223196}` branch
- Repeat the procedure for all the additional RealSense devices (e.g. `Intel® RealSense™ Camera SR300 RGB`)

#### Compiling Librealsense with Metadata support:
During compilation the library will automatically detect and enable/disable metadata functionality according to the WinSDK version selected.
In case the installed WinSDK doesn't expose metadata the user will be notified that the build does not include metadata generation:  
`Librealsense notification: Featuring UVC Metadata requires WinSDK 10.0.10586.0 toolset.  
The library will be compiled without the metadata support!`

In order to ensure compilation with metadata support check the  `ENFORCE_METADATA` in the [Cmake configuration stage](#cmake_snapshot_win).
When set, the compiler will check the target WinSDK version, and abort the build if it is not compatible with metadata requirements.

**Note** In case of multiple WinSDK version installed, CMake automatically selects the latest version of SDK. In some cases, however, the automatic selection may fail. Then you need to manually retarget the solution for the proper WinSDK version:  
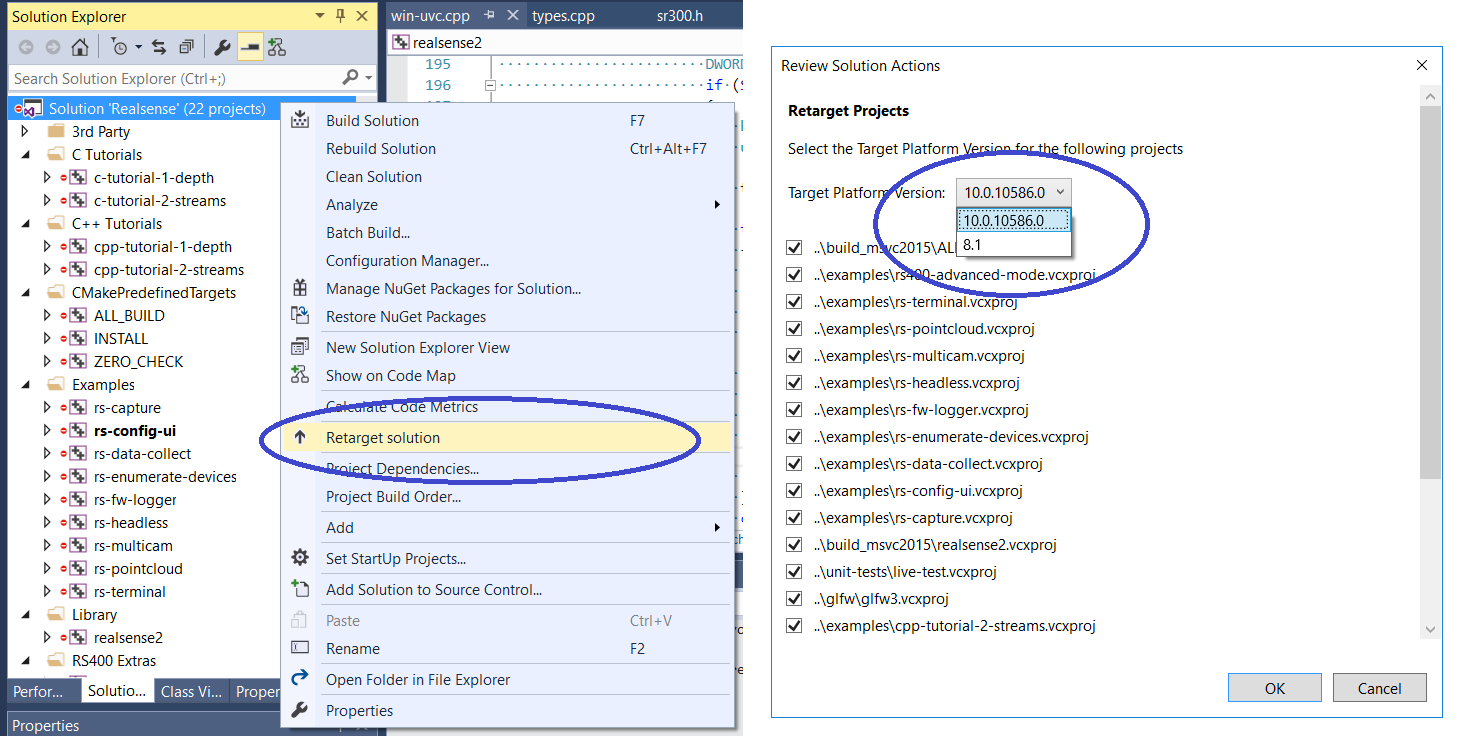
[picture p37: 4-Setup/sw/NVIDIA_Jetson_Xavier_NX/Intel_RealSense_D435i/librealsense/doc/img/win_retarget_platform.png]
win_retarget_platform


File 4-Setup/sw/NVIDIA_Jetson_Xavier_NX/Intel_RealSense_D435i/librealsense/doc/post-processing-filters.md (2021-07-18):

Librealsense Post-Processing Filters

## Table of Contents
* [Filters Description](#post-processing-filters)
  * [Decimation filter](#decimation-filter)
  * [Spatial Edge-Preserving filter](#spatial-filter)
  * [Temporal filter](#temporal-filter)
  * [Holes Filling filter](#hole-filling-filter)
* [Design and Implementation](#post-processing-implementation)
  * [Using Filters in application code](#post-processing-api-usage)

## Filters Description

Librealsense implementation includes post-processing filters to enhance the quality of depth data and reduce noise levels. All the filters are implemented in the library core as independent blocks to be used in the customer code

### Decimation filter
Effectively reduces the depth scene complexity.
The filter runs on kernel sizes [2x2] to [8x8] pixels. For patches sized 2 and 3 the median depth value is selected. For larger kernels, 4-8 pixels, the mean depth is used due to performance considerations.

The image size is scaled down proportionally in both dimensions to preserve the aspect ratio.
Internally, the filter imposes 4-pixel block alignment for the output frame size width and height. E.g. for input size (1280X720) and scale factor 3 the output size calculation is:  

[1280,720]/3 -> [<span style="color:red">426.6666667</span>, 240] -> [<span style="color:blue">428</span>,240]  
\*The padded rows/columns are zero-filled.

After the resulted frame is produced, the frame intrinsic parameters are recalculated to compensate for the resolution changes.  
The filter also provides some hole filling capability, as the filter uses  valid (non-zero) pixels only.  

| Controls  | Operation |  Range | Default |
:---------: | :-------- | :----- | :-----: |
| Filter Magnitude | The decimation linear scale factor | Discrete steps in [2-8] range | 2

### Spatial Edge-Preserving filter
\*The implementation is based on [paper](http://inf.ufrgs.br/~eslgastal/DomainTransform/) by Eduardo S. L. Gastal and Manuel M. Oliveira.

Key characteristics:
* 1D edge-preserving spatial filter using high-order domain transform.
* Linear-time compute, not affected by the choice of parameters.

The filter performs a series of 1D horizontal and vertical passes or iterations, to enhance the smoothness of the reconstructed data.

Controls | Operation |  Range | Default
:-------:|:----------| :---- | :-----:
Filter Magnitude | Number of filter iterations | [1-5] | 2
Smooth Alpha | The Alpha factor in an exponential moving average with Alpha=1 - no filter. Alpha = 0 - infinite filter | [0.25-1] | 0.5
Smooth Delta | Step-size boundary. Establishes the threshold used to preserve "edges" | Discrete [1-50] | 20
Hole Filling | An in-place heuristic symmetric hole-filling mode applied horizontally during the filter passes. Intended to rectify minor artefacts with minimal performance impact | [0-5] range mapped to [none,2,4,8,16,unlimited] pixels. | 0 (none)

### Temporal filter
The temporal filter is intended to improve the depth data persistency by manipulating per-pixel values based on previous frames.
The filter performs a single pass on the data, adjusting the depth values while also updating the tracking history. In cases where the pixel data is missing or invalid, the filter uses a user-defined persistency mode to decide whether the missing value should be rectified with stored data.
Note that due to its reliance on historic data the filter may introduce visible blurring/smearing artifacts, and therefore is best-suited for static scenes.

Controls | Operation |  Range | Default
:------: | :-------- | :---- | :----:
Smooth Alpha | The Alpha factor in an exponential moving average with Alpha=1 - no filter. Alpha = 0 - infinite filter | [0-1] | 0.4
Smooth Delta |  Step-size boundary. Establishes the threshold used to preserve surfaces (edges) | Discrete [1-100] | 20
Persistency index | A set of predefined rules (masks) that govern when missing pixels will be replaced with the last valid value so that the data will remain persistent over time:<br/> __*Disabled*__ - The Persistency filter is not activated and no hole filling occurs.<br/> __*Valid in 8/8*__ - Persistency activated if the pixel was valid in 8 out of the last 8 frames<br/> __*Valid in 2/last 3*__ - Activated if the pixel was valid in two out of the last 3 frames<br/> __*Valid in 2/last 4*__ - Activated if the pixel was valid in two out of the last 4 frames<br/> __*Valid in 2/8*__ - Activated if the pixel was valid in two out of the last 8 frames<br/> __*Valid in 1/last 2*__ - Activated if the pixel was valid in one of the last two frames<br/> __*Valid in 1/last 5*__ - Activated if the pixel was valid in one out of the last 5 frames<br/> __*Valid in 1/last 8*__ - Activated if the pixel was valid in one out of the last 8 frames<br/> __*Persist Indefinitely*__ - Persistency will be imposed regardless of the stored history (most aggressive filtering) | [0-8] enumerated  | 3 (__*Valid in 2/last 4*__)  

### Holes Filling filter

The filter implements several methods to rectify missing data in the resulting image.
The filter obtains the four immediate pixel "neighbors" (up, down, left, right), and selects one of them according to a user-defined rule.

Controls | Operation |  Range | Default
:------: | :-------- | :---- | :----:
Hole Filling| Control the data that will be used to fill the invalid pixels | [0-2] enumerated:<br/>__*fill_from_left*__ - Use the value from the left neighbor pixel to fill the hole<br/>__*farest_from_around*__ - Use the value from the neighboring pixel which is furthest away from the sensor<br/>__*nearest_from_around*__ - - Use the value from the neighboring pixel closest to the sensor| 1 (Farest from around)

## Design and Implementation
Post-processing modules are encapsulated into self-contained processing blocks, that provide for the following key requirements:
1. Synchronous/Asynchronous invocation
2. Internal frames memory/lifetime management

The filters are capable to receive and process frames from different sources, though in the general case it is not practical for the following reasons:
- Performance overhead as each time a new type/source of the frame is recognized, some filters require re-initialization.
- The Temporal filter effectiveness relies on the frame's history being preserved. Switching the frame sources invalidates the preserved history and incapacitates the filter.
Therefore establishing and maintaining a filter pipe per camera source is strongly recommended.

The filters preserve the original data and always generate a new (filtered) frame to pass on. The re-generation of new frames allows to share frame among different consumers (thread) without the risk of the data being overwritten by another user.

All filters support discreet as well as floating point input data formats.
The floating point inputs are utilized by D400 stereo-based Depth cameras that support Disparity data representation.
The discreet version of the filters is primarily used with SR300 camera, but also
can be applied to D400 devices (though not recommended)

## Using Filters in application code
The post-processing blocks are designed and built for concatenation into processing pipes.
There are no software-imposed constraints that mandate the order in which the filters shall be applied.
At the same time the recommended scheme used in librealsense tools and demos is elaborated below:  <br/>
**Depth Frame** >>  **Decimation Filter** >> **Depth2Disparity Transform**<span style="color:blue">\*\*</span> -> **Spatial Filter** >> **Temporal Filter** >> **Disparity2Depth Transform**<span style="color:blue">\*\*</span> >> **Hole Filling Filter** >>  **Filtered Depth**.  <br/>
<span style="color:blue">\*\*</span> Applicable for stereo-based depth cameras (D4XX).  
Note that even though the filter order in the demos is predefined, each filter is controlled individually and can be toggled on/off at run-time.

Demos and tools that have the post-processing code blocks embedded:
1. [RealSense-Viewer](https://github.com/IntelRealSense/librealsense/tree/master/tools/realsense-viewer)
2. [Depth Quality Tool](https://github.com/IntelRealSense/librealsense/tree/master/tools/depth-quality)
2. [Post-Processing Demo](https://github.com/IntelRealSense/librealsense/tree/master/examples/post-processing)

Filter initialization and activation flows:
Using `C` API calls:
```c
// Establishing a frame_queue object for each processing block that will receive the processed frames
rs2_frame_queue* decimated_queue = rs2_create_frame_queue(1, NULL);
rs2_frame_queue* spatial_queue = rs2_create_frame_queue(1, NULL);
...
// Creating processing blocks/ filters
rs2_processing_block* decimation_filter = rs2_create_decimation_filter_block(NULL);
rs2_processing_block* spatial_filter = rs2_create_spatial_filter_block(NULL);
...

// Direct the output of the filters to a dedicated queue
rs2_start_processing_queue(decimation_filter, decimated_queue, NULL);
rs2_start_processing_queue(spatial_filter, spatial_queue, NULL);
...
// Get depth frame from the device
rs2_frame* depth_frame = ...

// Apply decimation filter
rs2_process_frame(decimation_filter, depth_frame, NULL);
rs2_frame* decimated_frame = rs2_wait_for_frame(decimated_queue, 5000, NULL);
// Inject the decimated frame to spatial filter
rs2_process_frame(spatial_filter, decimated_frame, NULL);
// Get the filtered frame
rs2_frame* spatial_filter_frame = rs2_wait_for_frame(spatial_queue, 5000, NULL);
// Use the filtered data
...

// Control filter options
rs2_set_option((rs2_options*)decimation_filter, RS2_OPTION_FILTER_MAGNITUDE, 3, NULL);
rs2_set_option((rs2_options*)spatial_filter, RS2_OPTION_FILTER_SMOOTH_ALPHA, 0.5f, NULL);
```

Using `C++` API:  
```cpp
    // Streaming initialization
    rs2::pipeline pipe;
    ...
    // Declare filters
    rs2::decimation_filter dec_filter;
    rs2::spatial_filter spat_filter;

    // Configure filter parameters
    decimation_filter.set_option(RS2_OPTION_FILTER_MAGNITUDE, 3);
    ...
    spatial_filter.set_option(RS2_OPTION_FILTER_SMOOTH_ALPHA, 0.55f);
    ...

    // Main Loop
    while (true) {
       rs2::frameset data = pipe.wait_for_frames();
       rs2::frame depth_frame = data.get_depth_frame();
       ...
       rs2::frame filtered = depth_frame;
       // Note the concatenation of output/input frame to build up a chain
       filtered = dec_filter.process(filtered);
       filtered = spatial_filter.process(filtered);

    }
```

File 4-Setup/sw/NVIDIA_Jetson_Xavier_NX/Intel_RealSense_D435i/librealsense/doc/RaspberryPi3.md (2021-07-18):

# Intel&reg; RealSense&trade; D400 cameras with Raspberry Pi

This document describes how to use the Intel RealSense D400 cameras on Raspberry PI 3 Model B (which offers only USB2 interface).

> **Note:** Camera capabilities are severely reduced when connected to USB2 port due to lack of bandwidth.<br />USB2 interface over D400 cameras is supported from FW 5.08.14.0 and on. Later firmware updates add more functionality, such as streaming reduced RGB video and additional Depth resolutions



## Installation Instructions
1. Install [Ubuntu MATE](https://ubuntu-mate.org/) on your [Raspberry PI 3](https://www.raspberrypi.org/products/raspberry-pi-3-model-b/).

2. Clone and compile the latest [Intel&reg; RealSense&trade; SDK 2.0](https://github.com/IntelRealSense/librealsense/releases/latest) by following the instructions under [Linux Installation](https://github.com/IntelRealSense/librealsense/blob/development/doc/installation.md).
In the section [Prerequisites](https://github.com/IntelRealSense/librealsense/blob/development/doc/installation.md##prerequisites), proceed with the steps till (not including) the kernel patches instructions.

> **Note**: In some cases the RAM capacity is not sufficient to compile the SDK, so if the compilation process crashes or exits with an error-code try to create a [swap file](https://www.howtoforge.com/ubuntu-swap-file) and then recompile the SDK.

3. [Activate](https://ubuntu-mate.community/t/tutorial-activate-opengl-driver-for-ubuntu-mate-16-04/7094) the OpenGL driver.
4. Plug the D400 camera and play with RealSense SDK [examples](https://github.com/IntelRealSense/librealsense/tree/master/examples)/[tools](https://github.com/IntelRealSense/librealsense/tree/master/tools).

## Expected Output
1. Streaming Depth data with 480x270 resolution and 30 FPS using the [Intel RealSense Viewer](https://github.com/IntelRealSense/librealsense/tree/master/tools/realsense-viewer).


2. Streaming Depth and IR with 424x240 resolution and 30 FPS:


3. Point-cloud of depth and IR:


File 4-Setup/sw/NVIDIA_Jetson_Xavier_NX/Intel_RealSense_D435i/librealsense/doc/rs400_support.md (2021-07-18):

# Software Support Model - Intel® RealSense™ SDK 2.0

## Overview

With the release of the D400 series of Intel® RealSense™ devices, Intel RealSense Group is introducing a number of changes to the **librealsense** support.

Software support for Intel® RealSense™ technology will be split into two coexisting release lineups: **librealsense 1.x** and **librealsense 2+**.

 * **librealsense 1.x** will continue to provide support for RealSense™ devices: F200, R200 and ZR300.

 * **librealsense 2+** will support the next generation of RealSense™ devices, starting with the RS300 and RS400.

 ## API Changes

**librealsense2** brings the following improvements and new capabilities (which are incompatible with older RealSense devices):

### Streaming API
* **librealsense2** provides a more flexible interface for frame acquisition.  
Instead of a single `wait_for_frames` loop, the API is based on callbacks and queues:
```cpp
// Configure queue of size one and start streaming frames into it
rs2::frame_queue queue(1);
dev.start(queue);
// This call will block the current thread until new frames become available
auto frame = queue.wait_for_frame();
auto pixels = frame.get_data(); // pointer to frame data
```
* The same API can be used in a slightly different way for **low-latency** applications:
```cpp
// Configure direct callback for new frames:
dev.start([](rs2::frame frame){
    auto pixels = frame.get_data(); // pointer to frame data
});
// The application will be notified as soon as new frames become available.
```
**Note:** This approach allows users to bypass the buffering and synchronization that was done by `wait_for_frames`.

*  Users who do need to synchronize between different streams can take advantage of the `rs2::syncer` class:
```cpp
sycner sync;
dev.start(sync);
// The following call, using the frame timestamp, will block the
// current thread until the next coherent set of frames become available
auto frames = sync.wait_for_frames();
for (auto&& frame : frames)
{
    auto pixels = frame.get_data(); // pointer to frame data
}
```
* This version of `wait_for_frames` is **thread-safe** by design. You can safely pass a `rs::frame` object to a background thread. This is done without copying the frame data and without extra dynamic allocations.

### Multi-Streaming Model

**librealsense2** eliminates limitations imposed by previous versions with regard to multi-streaming:
* Multiple applications can use librealsense2 simultaneously, as long as no two users try to stream from the same camera endpoint.  
In practice, this means that you can:
  * Stream multiple cameras within a single process
  * Stream from camera A in one process and from camera B in another process
  * Stream depth from camera A in one process while streaming fisheye / motion from the same camera in another process
  * Stream from camera A in one process while issuing controls to camera A from another process
* The following streams of the RS400 act as independent endpoints: Depth, Fisheye, Motion-tracking, Color
* Each endpoint can be exclusively locked using `open/close` methods:
```cpp
// Configure depth to run at first permitted configuration
dev.open(dev.get_stream_profiles().front());
// From this point on, device streaming is exclusively locked.
dev.close(); // Release device ownership
```
* Alternatively, users can use the  `rs2::util::config` helper class to configure multiple endpoints at once:
```cpp
rs2::util::config config;
// Declare your preferences
config.enable_all(rs2::preset::best_quality);
// The config object resolves them into concrete capabilities for the supplied camera
auto stream = config.open(dev);
stream.start([](rs2::frame) {});
```

## New Functionality

* **librealsense2** will be shipped with a built-in [Python Wrapper](../wrappers/python/) for easier integration.
* New [troubleshooting tools](../tools/) are now part of the package, including a tool for hardware log collection.
* **librealsense2** is capable of handling device disconnects and the discovery of new devices at runtime.
* [Playback & Record](../src/media/readme.md) functionality is available out-of-the-box. 

## Transition to CMake
**librealsense2** does not provide hand-written Visual Studio, QT-Creator and XCode project files as you can build **librealsense** with the IDE of your choice using portable CMake scripts.  

## Intel® RealSense™ RS400 and the Linux Kernel

* The Intel® RealSense™ RS400 series (starting with kernel 4.4.0.59) does not require any kernel patches for streaming 
* Advanced camera features may still require kernel patches. Currently, getting **hardware timestamps** is dependent on a patch that has not yet been up-streamed. Without the patch applied you can still use the camera but you will receive a system-time instead of an optical timestamp.

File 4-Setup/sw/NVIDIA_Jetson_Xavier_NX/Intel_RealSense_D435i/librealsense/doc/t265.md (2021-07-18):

# T265 Tracking Camera

The **Intel® RealSense™ Tracking Camera T265** includes two greyscale cameras with fisheye lens, an IMU, and an Intel® Movidius™ Myriad™ 2 VPU. All of the V‑SLAM algorithms run directly on the VPU, allowing for very low latency and extremely efficient power consumption (1.5W).

RealSense SDK currently supports T265 on Windows and Linux as well as via our ROS wrapper.

## Notes / known issues

- For wheeled robots, odometer input is a requirement for robust and accurate tracking. The relevant APIs will be added to librealsense and ROS/realsense in upcoming releases. Currently, the API is available in the [underlying device driver](https://github.com/IntelRealSense/librealsense/blob/master/third-party/libtm/libtm/include/TrackingDevice.h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).
- The relocalization API should be considered unstable, and is planned to be updated in a future release
- Android support will come in a future release, as well as OpenVR integration.

## <a name="origin">Sensor origin and coordinate system</a>
To aid AR/VR integration, the T265 tracking device uses the defacto VR framework standard coordinate system instead of the SDK standard:

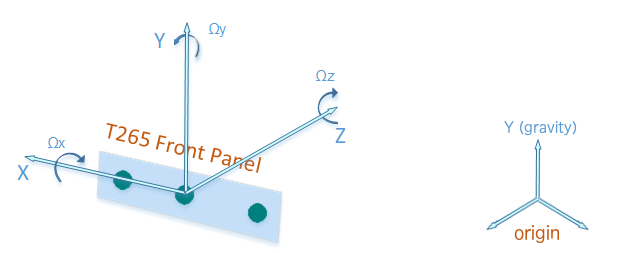
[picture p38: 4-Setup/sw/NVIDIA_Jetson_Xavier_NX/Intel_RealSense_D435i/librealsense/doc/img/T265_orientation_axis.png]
T265 Pose orientation
  
1.	Positive X direction is towards right imager
2.	Positive Y direction is upwards toward the top of the device
3.	Positive Z direction is inwards toward the back of the device

The center of tracking corresponds to the center location between the right and left monochrome imagers on the PCB.

When T265 tracking starts, an origin coordinate system is created and RealSense SDK provides T265 poses relative to it. World's Y axis is always aligned with gravity and points to the sky. World's X and Z axes are not globally set, but determined when tracking starts based on the initial orientation of the T265 device with the initial -Z world axis as the projection of the camera axis to the ground plane.  This does mean that the initial yaw can seem random when the device is started in a downward facing configuration, say on the drone.   All T265 (and librealsense) coordinate systems are right-handed.

## Calibration

The T265's sensors (including the IMU) are calibrated on the production line, so no further calibration process is required (unlike the IMU on the D435i). Refer to the [rs-ar-basic](../examples/ar-basic) example to see how to get and use sensor intrinsics and extrinsics for the cameras and IMU.

For reference, this is the orientation of each sensor:
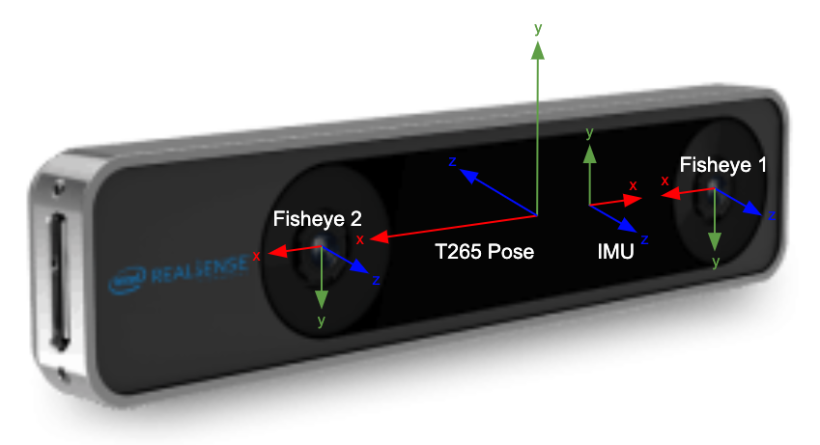
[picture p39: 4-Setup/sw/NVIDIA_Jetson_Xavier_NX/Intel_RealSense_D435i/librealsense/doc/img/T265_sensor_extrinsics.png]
T265 Sensor extrinsics


## Timestamps

The T265 always reports the time for all sensors in `RS2_TIMESTAMP_DOMAIN_GLOBAL_TIME`. This uses a time synchronization mechanism between the host computer and the T265 to provide all sensor data timestamps in millisecond accurate host clock time.

## Examples and tools

The following `librealsense` examples and tools work with T265 (see the full of [C++ examples](../examples/), [Python examples](../wrappers/python/examples/) and [tools](../tools/)):

### C++ Examples
 - [rs-pose](../examples/pose/) - A basic pose retrieval example
 - [rs-pose-predict](../examples/pose-predict) - Demonstrates pose prediction using librealsense global time and the callback API
 - [rs-pose-and-image](../examples/pose-and-image) - Demonstrates how to use tracking camera asynchroniously to obtain 200Hz poses and 30Hz images
 - [rs-pose-apriltag](../examples/pose-apriltag) - Demonstrates how to compute [Apriltag](https://github.com/AprilRobotics/apriltag/tree/3.1.1) pose from T265 fisheye image stream
 - [rs-ar-basic](../examples/ar-basic) - Shows how to use pose and fisheye frames to display a simple virtual object on the fisheye image
 - [rs-tracking-and-depth](../examples/tracking-and-depth) - Shows how to use the tracking camera together with a depth camera to display a 3D pointcloud with respect to a static reference frame
 - [rs-trajectory](../examples/trajectory) - This sample demonstrates how to draw the 3D trajectory of the device's movement based on pose data. 
 - [rs-capture](../examples/capture) - 2D visualization of sensor data.
 - [rs-save-to-disk](../examples/save-to-disk) - Shows how to configure the camera and save PNGs
 - [rs-multicam](../examples/multicam) - Work multiple cameras streams simultaneously, in separate windows
 - [rs-software-device](../examples/software-device) Shows how to create a custom `rs2::device`
 - [rs-sensor-control](../examples/sensor-control) - A tutorial for using the `rs2::sensor` API

### Python examples

 - [T265 Basic](../wrappers/python/examples/t265_example.py) - Demonstrates how to retrieve pose data from a T265
 - [T265 Coordinates](../wrappers/python/examples/t265_rpy.py) - This example shows how to change coordinate systems of a T265 pose
 - [T265 Stereo](../wrappers/python/examples/t265_stereo.py) - This example shows how to use T265 intrinsics and extrinsics in OpenCV to asynchronously compute depth maps from T265 fisheye images on the host.

### Tools

 - [enumerate-devices](../tools/enumerate-devices) - Console application providing information about connected devices
 - [recorder](../tools/recorder) - Simple command line raw data recorder
 - [data-collect](../tools/data-collect) - Collect statistics about various streams.

### Realsense viewer

As with all Realsense cameras, T265 works with [realsense-viewer](../tools/realsense-viewer). It provides visualization of all sensor streams, including a 3D visualization for pose samples:

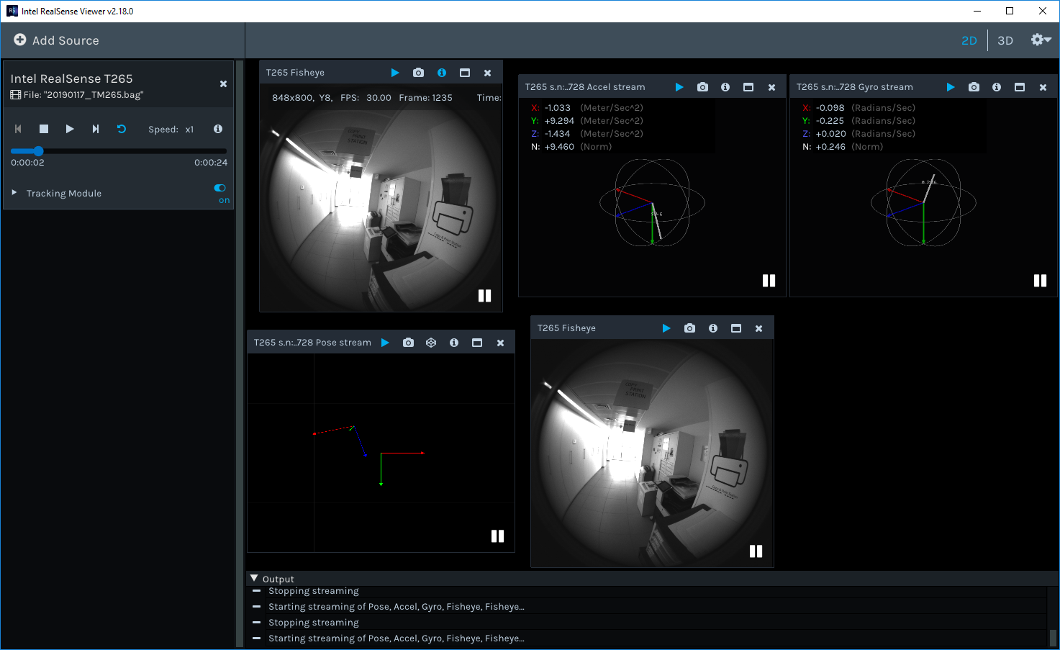
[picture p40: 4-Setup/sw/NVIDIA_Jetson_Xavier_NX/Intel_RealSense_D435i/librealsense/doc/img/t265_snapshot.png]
T265 2D Sensors


The IMU and tracking data streams are fully compatible with SDK's embedded recorder utility.

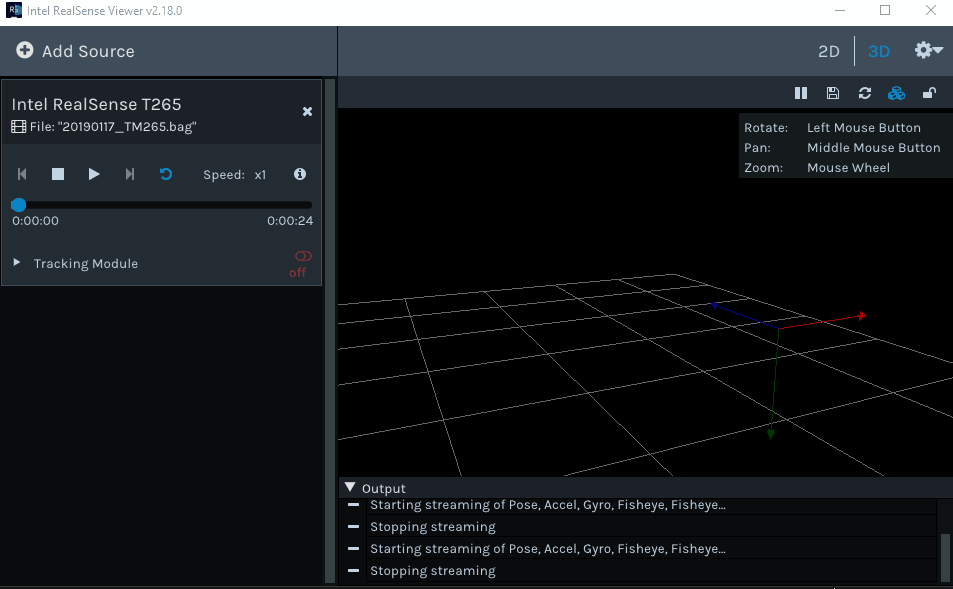
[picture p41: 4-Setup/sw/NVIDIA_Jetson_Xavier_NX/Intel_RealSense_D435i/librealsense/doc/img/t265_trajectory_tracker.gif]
T265 3D Pose Tracking


If you want to record raw sensor data including images in ROS `.bag` format, we recommend using [recorder](../tools/recorder)

## API
The pose and IMU data are treated by the SDK like any other supported sensor. Therefore the sensor access and invocation API calls are similar to those of the depth/rgb sensors of D400 and SR300:

```cpp
rs2::pipeline pipe;

rs2::config cfg;
cfg.enable_stream(RS2_STREAM_GYRO);
cfg.enable_stream(RS2_STREAM_ACCEL);
cfg.enable_stream(RS2_STREAM_POSE);

pipe.start(cfg);

while (app) // Application still alive?
{
    rs2::frameset frameset = pipe.wait_for_frames();

    // Find and retrieve IMU and/or tracking data
    if (rs2::motion_frame accel_frame = frameset.first_or_default(RS2_STREAM_ACCEL))
    {
        rs2_vector accel_sample = accel_frame.get_motion_data();
        //std::cout << "Accel:" << accel_sample.x << ", " << accel_sample.y << ", " << accel_sample.z << std::endl;
        //...
    }

    if (rs2::motion_frame gyro_frame = frameset.first_or_default(RS2_STREAM_GYRO))
    {
        rs2_vector gyro_sample = gyro_frame.get_motion_data();
        //std::cout << "Gyro:" << gyro_sample.x << ", " << gyro_sample.y << ", " << gyro_sample.z << std::endl;
        //...
    }

    if (rs2::pose_frame pose_frame = frameset.first_or_default(RS2_STREAM_POSE))
    {
        rs2_pose pose_sample = pose_frame.get_pose_data();
        //std::cout << "Pose:" << pose_sample.translation.x << ", " << pose_sample.translation.y << ", " << pose_sample.translation.z << std::endl;
        //...
    }
}
```

## FAQ

### Is this a depth camera?
No, the T265 does not offer any Depth information. It can provide position and orientation (6-DOF), IMU (accelerometer and gyroscope), and two monochrome fisheye streams.

### Can I use it together with a depth camera?
Yes, this device can be used with RealSense (and most likely any 3rd-party) depth cameras. It is passive and comes with an IR-cut filter.

### How can I use the camera intrinsics and extrinsics?

The T265 uses the [Kanalla-Brandt distortion model](http://www.ee.oulu.fi/research/mvmp/mvg/files/pdf/pdf_697.pdf). This model is supported in OpenCV as part of the fisheye model. There is a python example which uses the camera intrinsics and extrinsics to [compute depth from T265 images on the host using OpenCV](../wrappers/python/examples/t265_stereo.py). There is also a C++ example which uses the camera intrinsics and extrinsics to [display a virtual object](../examples/ar-basic).

### What platforms are supported?
The T265 is supported via librealsense on Windows, Linux, macOS and via ros-realsense. Android support are planned but not scheduled yet, as well as OpenVR integration.

### What are the system requirements?
Any board with USB2 capable of receiving pose data at 200 times a second should be sufficient. The device was validated on Intel NUC platform. To access the fisheye streams, USB3 is required.

### Will the same SLAM be available for the D435i as a software package?
We are still looking into it, please stay tuned.

### What is wheel odometry and how does it help T265 navigate?

Wheel odometry is the use of sensors to measure how much a wheel turns, it can be used to estimate changes in a wheeled robots position. T265 has wheel odometry support built in, allowing it to use the data from these sensors to refine the position data of the robot. Providing robotic wheel odometer or velocimeter data over USB to TM2 and the corresponding calibration data will make the tracking much more robust on wheeled robots, which otherwise can experience many tracking failures. The calibration file format is described in the [section below](#wheel-odometry-calibration-file-format). We consider odometer input to be a requirement for robust tracking on wheeled robots.

### Can T265 work indoors and outdoors?

Yes, T265 can work both indoors and outdoors. Just like a person, it can be blinded by light that shines straight into its eyes, and it can’t see in absolute darkness.

### Do multiple T265 devices interfere with each other?

No, you can use as many T265 devices in a space as you like.

### Are there any T265 specific options?

Yes, there are.

 - `RS2_OPTION_ENABLE_MAPPING`  - The internal map allows the device to recognize places it's been before so that it can give a consistent pose for that location.   The map has a fixed finite size and will keep the most often/recently seen locations.  Without this it will be operating completely open loop (i.e. just doing VIO) and will have more drift.   The device will use the map to close modest loops and recover from small drifts.  Enabling this option will not cause pose jumps without `RS2_OPTION_ENABLE_POSE_JUMPING`.
 - `RS2_OPTION_ENABLE_POSE_JUMPING` - This option allows the device to discontinuously jump its pose whenever it discovers its pose is inconsistent with one it has given before.   For example, after walking in a circle or covering the camera (getting a small drift) and uncovering it.  Currently this will only affect the translation and not the rotation nor any of the velocities or accelerations.
 - `RS2_OPTION_ENABLE_RELOCALIZATION` - This allows the device to solve the Kidnapped Robot Problem, i.e. it will allow connecting the current map to a loaded map or connecting the current map to itself after accumulating a large drift, say after closing a large loop or covering the camera and walking around.  This is independent of jumping the pose.  When fooled this feature can lead to much larger errors than are likely via the basic mapping.
 - `RS2_OPTION_ENABLE_MAP_PRESERVATION` - This option will allow the device to preserve its current map across stop/start calls.  The device will act as if the map was saved after stop and loaded back before the subsequent start.  This was the default in versions <= 2.29.0.

## Appendix

### Wheel odometry calibration file format
Below is a sample calibration file with inline comments (not a valid file format! Remove "//comments" to make valid) that explain each field. Please note that this is an intermediate solution and a more unified interface will be coming.
```
{
    "velocimeters": [ // array of velocity sensors (currently max. 2 supported)
        {
            "scale_and_alignment": [ // 3-by-3 matrix, row-major (multiplies measurement)
                1.0,
                0.0000000000000000,
                0.0000000000000000,
                0.0000000000000000,
                1.0,
                0.0000000000000000,
                0.0000000000000000,
                0.0000000000000000,
                1.0
            ],
            "noise_variance": 0.004445126050420168, // measurement covariance (to be determined/tuned)
            "extrinsics": { // relative transformation of sensor frame w.r.t. T265 body frame
                "T": [ // translation (in meters)
                    -0.5059,
                    -0.6294,
                    -0.6873
                ],
                "T_variance": [ // currently not used, please ignore
                    9.999999974752427e-7, 
                    9.999999974752427e-7, 
                    9.999999974752427e-7
                ],
                "W": [ // orientation in axis-angle representation, axis x angle (in rad)
                    -1.1155,
                    -1.1690,
                    -1.2115
                ],
                "W_variance": [ // currently not used, please ignore
                    9.999999974752427e-5, 
                    9.999999974752427e-5, 
                    9.999999974752427e-5
                ]
            }
        }
    ]
}
```
### Extrinsic Calibration for Wheeled Odometry Examples

 - All calibration metrics are relative to T265 origin frame. I.e.: They are offsets/rotations *from* the T265 origin *to* the robot's origin. Said another way, we transform a point from frame B (Robot Odometry) to frame A (T265 Pose) or A_p = H_AB * B_p, where A_p is the point expressed in frame A, B_p is the point expressed in frame B, and H_AB is the corresponding homogeneous transformation.

 - In order for the T265 to consume and use odometry data correctly it must know where the robot's origin is relative to itself. This is accomplished by feeding a calibration (json) file into the librealsense API with this initial data.

 In this basic sample robot setup, for simplicity, we assume the X-axis of the camera and robot's coordinate system are aligned (+X coming out of the screen) and only concern ourselves with the Y and Z axis. 

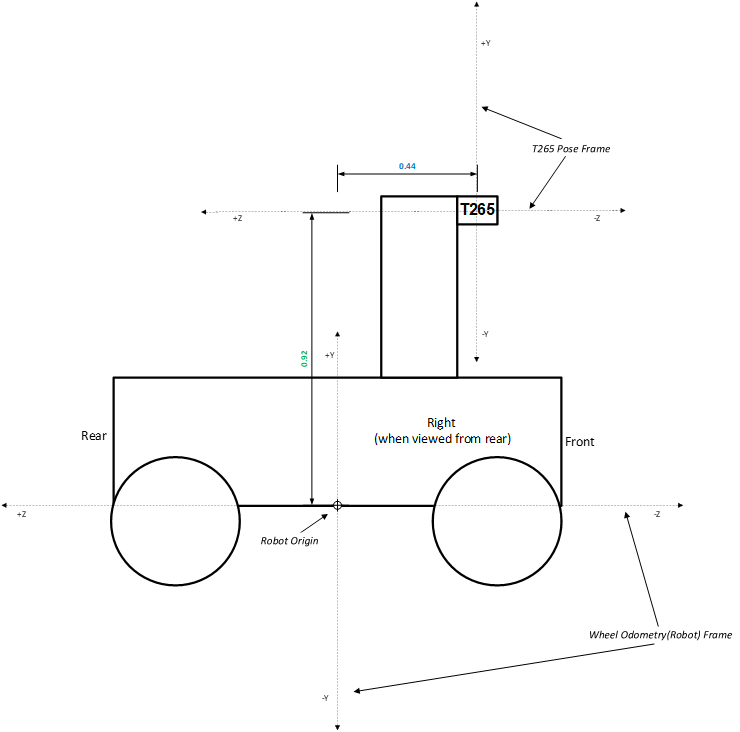
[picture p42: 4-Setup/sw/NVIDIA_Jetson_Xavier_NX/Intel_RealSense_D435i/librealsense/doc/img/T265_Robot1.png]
T265 Robot 1


 Corresponsing JSON:
 ```
 {
    "velocimeters": [
        {
            "scale_and_alignment": [
                1.0,
                0.0,
                0.0,
                0.0,
                1.0,
                0.0,
                0.0,
                0.0,
                1.0
            ],
            "noise_variance": 0.00004445126050420168,
            "extrinsics": {
                "T": [
                    0.0,      // No Translation.
                    -0.92,   // 0.92m below (-Y) the camera.
                    0.44    // 0.44m behind (+Z) the camera.
                ],
                "T_variance": [
                    9.999999974752427e-7,
                    9.999999974752427e-7,
                    9.999999974752427e-7
                ],
                "W": [
                    0.0,
                    0.0,
                    0.0
                ],
                "W_variance": [
                    9.999999974752427e-5,
                    9.999999974752427e-5,
                    9.999999974752427e-5
                ]
            }
        }
    ]
}
```

 In this example, we take the above setup and add a rotation around the camera's X-axis.
 
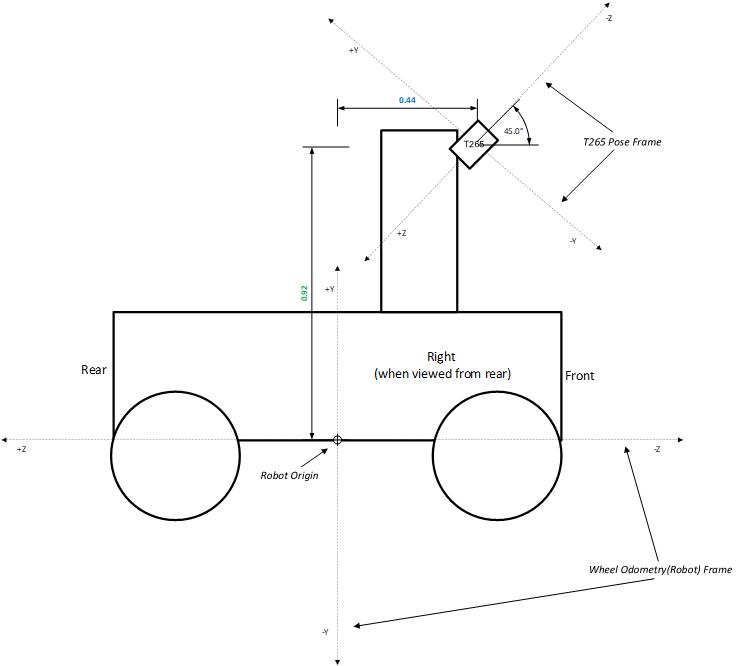
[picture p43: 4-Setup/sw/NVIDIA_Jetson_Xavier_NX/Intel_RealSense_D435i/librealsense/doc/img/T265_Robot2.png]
T265 Robot 2


 Corresponding JSON:
 
 ```
 {
    "velocimeters": [
        {
            "scale_and_alignment": [
                1.0,
                0.0,
                0.0,
                0.0,
                1.0,
                0.0,
                0.0,
                0.0,
                1.0
            ],
            "noise_variance": 0.00004445126050420168,
            "extrinsics": {
                "T": [
                    0.0,      // No Translation.
                    -0.3394,  // 0.3394m below (-Y) the camera.
                    0.9617    // 0.9617m behind (+Z) the camera.
                ],
                "T_variance": [
                    9.999999974752427e-7,
                    9.999999974752427e-7,
                    9.999999974752427e-7
                ],
                "W": [
                    -0.7853982,  // -0.78rad (-pi/4) around the camera x-axis.
                    0.0,
                    0.0
                ],
                "W_variance": [
                    9.999999974752427e-5,
                    9.999999974752427e-5,
                    9.999999974752427e-5
                ]
            }
        }
    ]
}
 ```

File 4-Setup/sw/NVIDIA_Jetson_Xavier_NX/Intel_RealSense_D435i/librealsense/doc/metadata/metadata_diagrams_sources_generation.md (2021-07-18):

> **Note** - github is currently lacks embedded support for drawing diagrams
Therefore, in order to generate and embed diagrams into the readme we employ the following technique:

- Generate and Draw chart with https://stackedit.io/editor .The site's [main page](https://stackedit.io/) provides a comprehensive list of examples for formatting both text and diagrams.
Expo
- Export the diagram into svg with this [online tool](https://bramp.github.io/js-sequence-diagrams/)
- Use external tool ,such as [Inkscape](https://inkscape.org/en/download/windows/) to convert from svg to png, or other raster format.  
- Embed the resulted raster image into Markdown file

Source code for diagram generators
```sequence
title: RS4xx - Registration for metadata attributes
Participant C++ main
Participant rs2_context
Participant rs2_device
Participant rs2_metadata_handler
Participant OS
Participant Device
Device->OS: new device found
Note over OS: device is enumerated
Note over OS,C++ main: ..........      system is in idle state  ...............
Note over C++ main: Librealsense2 is started
C++ main->rs2_context: create context
rs2_context-->C++ main:
rs2_context->OS: Query connected devices
OS-->C++ main: List of device info
C++ main->rs2_device: create rs4xx object
rs2_device->rs2_device: ctor: register for metadata
rs2_device->rs2_metadata_handler: ctor: Instantiate handler
rs2_metadata_handler-->rs2_device:
rs2_device->rs2_device: ctor: map handler to an attribute
rs2_device-->C++ main:
Note over C++ main: device with metadata support is ready
```

```sequence
title: RS4xx - Metadata attributes propagation and query flow
Participant User Code
Participant rs2_device
Participant rs2_frame_callback
Participant rs2_frame
Participant rs2_backend
Participant Kernel/OS Driver
User Code->User Code: Initialize librealsense
Note over User Code,rs2_device:  Acquire Device handle
User Code->rs2_device: Start Stream (user-defined callback)
Note over rs2_device,rs2_frame_callback: Store callback handle
rs2_device->rs2_backend: Start Polling frames
Note over rs2_backend,Kernel/OS Driver: Polling frame
rs2_backend->rs2_frame: unpack and store frame pixels
rs2_backend->rs2_frame: check and store metadata payload
rs2_frame-->rs2_backend: frame is ready for dispatch
rs2_backend->rs2_frame_callback: invoke user-defined callback(rs2_frame)
rs2_frame_callback->rs2_frame_callback: User code is invoked
rs2_frame_callback->rs2_frame: Check metadata attribute support
rs2_frame-->rs2_frame_callback: result (true/false)
rs2_frame_callback->rs2_frame: query metadata attribute value
rs2_frame-->rs2_frame_callback: value(/exception)
```

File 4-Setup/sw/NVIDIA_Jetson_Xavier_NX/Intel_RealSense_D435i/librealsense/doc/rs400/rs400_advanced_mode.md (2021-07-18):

# RS400 Advanced Mode

## Overview
RS400 is the newest in the series of stereo-based RealSense devices. It is provided in a number distinct models, all sharing the same depth-from-stereo ASIC. The models differ in optics, global vs. rolling shutter, and the projector capabilities. In addition, different use-cases may introduce different lighting conditions, aim at different range, etc...
As a result, depth-from-stereo algorithm in the hardware has to be able to adjust to vastly different stereo input images.

To achieve this goal, RS400 ASIC provides an extended set of controls aimed at advanced users, allowing to fine-tune the depth generation process. (and some other like **color-correction**)

Advanced mode hardware APIs are designed to be **safe**, in the sense that the user can't brick the device. You always have the option to exit advanced mode, and fall back to default mode of operation.
However, while tinkering with the advanced controls, depth quality and stream frame-rate are not guarantied. You are making changes on your own risk.

## Long-term vs. Short-term
* In the short-term, librealsense provides a set of advanced APIs you can use to access advanced mode. Since, this includes as much as 100 new parameters we also provide a way to serialize and load these parameters, using JSON file structure. We encourage the community to explore the range of possibilities and share interesting presets for different use-cases. The limitation of this approach is that the existing protocol is cumbersome and not efficient. We can't provide clear estimate on how much time it will take until any set of controls will take effect, and the controls are not standard in any way in the OS.
* In the long-term, Intel algorithm developers will come up with best set of recommended presets, as well as most popular presets from our customers, and these will be hard-coded into the camera firmware.
This will provide fast, reliable way to optimize the device for a specific use case.

## Programming Interface
 Here are some examples of how to use the advanced-mode API via C and C++.<br>
 
 ### Advanced Mode C API
 The following code sample checking if the connected device is in advanced-mode and moving it to advance-mode if it's not.
```c
/* Include the librealsense C header files */
#include <librealsense2/rs.h>
#include <librealsense2/rs_advanced_mode.h>

#include <stdio.h> // printf
#include <stdlib.h> // exit

/* Function calls to librealsense may raise errors of type rs_error*/
void check_error(rs2_error* e)
{
    if (e)
    {
        printf("rs_error was raised when calling %s(%s):\n", rs2_get_failed_function(e), rs2_get_failed_args(e));
        printf("    %s\n", rs2_get_error_message(e));
        exit(1);
    }
}

int main()
{
    rs2_error* e = 0;

    // Create a context object. This object owns the handles to all connected realsense devices.
    // The returned object should be released with rs2_delete_context(...)
    rs2_context* ctx = rs2_create_context(RS2_API_VERSION, &e);
    check_error(e);

    /* Get a list of all the connected devices. */
    // The returned object should be released with rs2_delete_device_list(...)
    rs2_device_list* device_list = rs2_query_devices(ctx, &e);
    check_error(e);

    int dev_count = rs2_get_device_count(device_list, &e);
    check_error(e);
    printf("There are %d connected RealSense devices.\n", dev_count);
    if (0 == dev_count)
        return 1;

    // Get the first connected device
    // The returned object should be released with rs2_delete_device(...)
    rs2_device* dev = rs2_create_device(device_list, 0, &e);
    check_error(e);

    // Check if Advanced-Mode is enabled
    int is_advanced_mode_enabled;
    rs2_is_enabled(dev, &is_advanced_mode_enabled, &e);
    check_error(e);

    if (!is_advanced_mode_enabled)
    {
        // Enable advanced-mode
        rs2_toggle_advanced_mode(dev, 1, &e);
        check_error(e);
    }

    rs2_delete_device(dev);
    rs2_delete_device_list(device_list);
    rs2_delete_context(ctx);
}
```

The following code sample showing how to serialize the current values of advanced mode controls to a JSON file,
and also how to load and apply it to the device.
```c
/* Include the librealsense C header files */
#include <librealsense2/rs.h>
#include <librealsense2/rs_advanced_mode.h>

#include <stdio.h> // printf
#include <stdlib.h> // exit

/* Function calls to librealsense may raise errors of type rs_error*/
void check_error(rs2_error* e)
{
    if (e)
    {
        printf("rs_error was raised when calling %s(%s):\n", rs2_get_failed_function(e), rs2_get_failed_args(e));
        printf("    %s\n", rs2_get_error_message(e));
        exit(1);
    }
}

int main()
{
    rs2_error* e = 0;

    // Create a context object. This object owns the handles to all connected realsense devices.
    // The returned object should be released with rs2_delete_context(...)
    rs2_context* ctx = rs2_create_context(RS2_API_VERSION, &e);
    check_error(e);

    /* Get a list of all the connected devices. */
    // The returned object should be released with rs2_delete_device_list(...)
    rs2_device_list* device_list = rs2_query_devices(ctx, &e);
    check_error(e);

    int dev_count = rs2_get_device_count(device_list, &e);
    check_error(e);
    printf("There are %d connected RealSense devices.\n", dev_count);
    if (0 == dev_count)
        return 1;

    // Get the first connected device
    // The returned object should be released with rs2_delete_device(...)
    rs2_device* dev = rs2_create_device(device_list, 0, &e);
    check_error(e);

    // Serialize current values of advanced mode controls to a JSON content
    rs2_raw_data_buffer* raw_data_buffer = rs2_serialize_json(dev, &e);
    check_error(e);

    // Get raw data size
    int raw_data_size = rs2_get_raw_data_size(raw_data_buffer, &e);
    check_error(e);

    // Get the pointer of the raw data
    const unsigned char* raw_data =  rs2_get_raw_data(raw_data_buffer, &e);
    check_error(e);

    // Write the raw_data to a JSON file
    const char* full_file_path = "./advanced_mode_controls.json";
    FILE *f = fopen(full_file_path, "w");
    if (f == NULL)
    {
        printf("Error opening file!\n");
        exit(1);
    }

    fwrite(raw_data, sizeof(unsigned char), raw_data_size, f);
    fclose(f);

    // Load the JSON raw data and apply the control values
    rs2_load_json(dev, raw_data, raw_data_size, &e);
    check_error(e);

    rs2_delete_raw_data(raw_data_buffer);
    rs2_delete_device(dev);
    rs2_delete_device_list(device_list);
    rs2_delete_context(ctx);
}
```

The following code sample showing how to retrieve the advanced-mode control values. 
```c
/* Include the librealsense C header files */
#include <librealsense2/rs.h>
#include <librealsense2/rs_advanced_mode.h>

#include <stdio.h> // printf
#include <stdlib.h> // exit

/* Function calls to librealsense may raise errors of type rs_error*/
void check_error(rs2_error* e)
{
    if (e)
    {
        printf("rs_error was raised when calling %s(%s):\n", rs2_get_failed_function(e), rs2_get_failed_args(e));
        printf("    %s\n", rs2_get_error_message(e));
        exit(1);
    }
}

int main()
{
    rs2_error* e = 0;

    // Create a context object. This object owns the handles to all connected realsense devices.
    // The returned object should be released with rs2_delete_context(...)
    rs2_context* ctx = rs2_create_context(RS2_API_VERSION, &e);
    check_error(e);

    /* Get a list of all the connected devices. */
    // The returned object should be released with rs2_delete_device_list(...)
    rs2_device_list* device_list = rs2_query_devices(ctx, &e);
    check_error(e);

    int dev_count = rs2_get_device_count(device_list, &e);
    check_error(e);
    printf("There are %d connected RealSense devices.\n", dev_count);
    if (0 == dev_count)
        return 1;

    // Get the first connected device
    // The returned object should be released with rs2_delete_device(...)
    rs2_device* dev = rs2_create_device(device_list, 0, &e);
    check_error(e);

    const int curr_val_mode = 0; // 0 - Get current values mode
    STDepthControlGroup curr_depth_control_group;
    // Get current values of depth control group
    rs2_get_depth_control(dev, &curr_depth_control_group, curr_val_mode, &e);
    check_error(e);

    const int min_val_mode = 1; // 1 - Get minimum values mode
    STDepthControlGroup min_depth_control_group;
    // Get minimum values of depth control group
    rs2_get_depth_control(dev, &min_depth_control_group, min_val_mode, &e);
    check_error(e);

    const int max_val_mode = 2; // 2 - Get maximum values mode
    STDepthControlGroup max_depth_control_group;
    // Get maximum values of depth control group
    rs2_get_depth_control(dev, &max_depth_control_group, max_val_mode, &e);
    check_error(e);

    // Set the maximum values to depth control group
    rs2_set_depth_control(dev, &max_depth_control_group, &e);
    check_error(e);

    rs2_delete_device(dev);
    rs2_delete_device_list(device_list);
    rs2_delete_context(ctx);

    return 0;
}
```

### Advanced Mode C++ API
The following sample code showing how to enable advanced-mode in a connected D400 device.
```cpp
/* Include the librealsense CPP header files */
#include <librealsense2/rs.hpp>
#include <librealsense2/rs_advanced_mode.hpp>

#include <iostream>

using namespace std;
using namespace rs2;

int main(int argc, char** argv) try
{
    // Obtain a list of devices currently present on the system
    context ctx;
    auto devices = ctx.query_devices();
    size_t device_count = devices.size();
    if (!device_count)
    {
        cout <<"No device detected. Is it plugged in?\n";
        return EXIT_SUCCESS;
    }

    // Get the first connected device
    auto dev = devices[0];

    if (dev.is<rs400::advanced_mode>())
    {
        auto advanced_mode_dev = dev.as<rs400::advanced_mode>();
        // Check if advanced-mode is enabled
        if (!advanced_mode_dev.is_enabled())
        {
            // Enable advanced-mode
            advanced_mode_dev.toggle_advanced_mode(true);
        }
    }
    else
    {
        cout << "Current device doesn't support advanced-mode!\n";
        return EXIT_FAILURE;
    }

    return EXIT_SUCCESS;
}
catch (const rs2::error & e)
{
    cerr << "RealSense error calling " << e.get_failed_function() << "(" << e.get_failed_args() << "):\n    " << e.what() << endl;
    return EXIT_FAILURE;
}
catch (const exception & e)
{
    cerr << e.what() << endl;
    return EXIT_FAILURE;
}
```

The following code sample showing how to retrieve the advanced-mode control values. 
```cpp
/* Include the librealsense CPP header files */
#include <librealsense2/rs.hpp>
#include <librealsense2/rs_advanced_mode.hpp>

#include <iostream>

using namespace std;
using namespace rs2;

int main(int argc, char** argv) try
{
    // Obtain a list of devices currently present on the system
    context ctx;
    auto devices = ctx.query_devices();
    size_t device_count = devices.size();
    if (!device_count)
    {
        cout <<"No device detected. Is it plugged in?\n";
        return EXIT_SUCCESS;
    }

    // Get the first connected device
    auto dev = devices[0];

    // Check if current device supports advanced mode
    if (dev.is<rs400::advanced_mode>())
    {
        // Get the advanced mode functionality
        auto advanced_mode_dev = dev.as<rs400::advanced_mode>();
        const int max_val_mode = 2; // 0 - Get maximum values
        // Get the maximum values of depth controls
        auto depth_control_group = advanced_mode_dev.get_depth_control(max_val_mode);

        // Apply the depth controls maximum values
        advanced_mode_dev.set_depth_control(depth_control_group);
    }
    else
    {
        cout << "Current device doesn't support advanced-mode!\n";
        return EXIT_FAILURE;
    }

    return EXIT_SUCCESS;
}
catch (const rs2::error & e)
{
    cerr << "RealSense error calling " << e.get_failed_function() << "(" << e.get_failed_args() << "):\n    " << e.what() << endl;
    return EXIT_FAILURE;
}
catch (const exception & e)
{
    cerr << e.what() << endl;
    return EXIT_FAILURE;
}
```
*Note: It is recommended to set advanced mode controls when not streaming.*

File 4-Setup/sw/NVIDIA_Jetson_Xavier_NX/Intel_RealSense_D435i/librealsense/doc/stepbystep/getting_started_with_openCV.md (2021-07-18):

# Getting Started with OpenCV

## Displaying Color Frame

In this demo, you will acquire color frame from the RealSense camera and display it using OpenCV.
Before you start, make sure you have librealsense and OpenCV installed and working properly on your system.
Using the editor of your choice create BGR_sample.cpp and copy-paste the following code-snippet:

```cpp
// include the librealsense C++ header file
#include <librealsense2/rs.hpp>

// include OpenCV header file
#include <opencv2/opencv.hpp>

using namespace std;
using namespace cv;

int main()
{
    //Contruct a pipeline which abstracts the device
    rs2::pipeline pipe;

    //Create a configuration for configuring the pipeline with a non default profile
    rs2::config cfg;

    //Add desired streams to configuration
    cfg.enable_stream(RS2_STREAM_COLOR, 640, 480, RS2_FORMAT_BGR8, 30);

    //Instruct pipeline to start streaming with the requested configuration
    pipe.start(cfg);

    // Camera warmup - dropping several first frames to let auto-exposure stabilize
    rs2::frameset frames;
    for(int i = 0; i < 30; i++)
    {
        //Wait for all configured streams to produce a frame
        frames = pipe.wait_for_frames();
    }

    //Get each frame
    rs2::frame color_frame = frames.get_color_frame();

    // Creating OpenCV Matrix from a color image
    Mat color(Size(640, 480), CV_8UC3, (void*)color_frame.get_data(), Mat::AUTO_STEP);

    // Display in a GUI
    namedWindow("Display Image", WINDOW_AUTOSIZE );
    imshow("Display Image", color);

    waitKey(0);

    return 0;
}
```

Compile and run the application from terminal using the following command line:

```shell
g++ -std=c++11 BGR_sample.cpp -lrealsense2 -lopencv_core -lopencv_highgui -o BGR && ./BGR
```

**Result:**

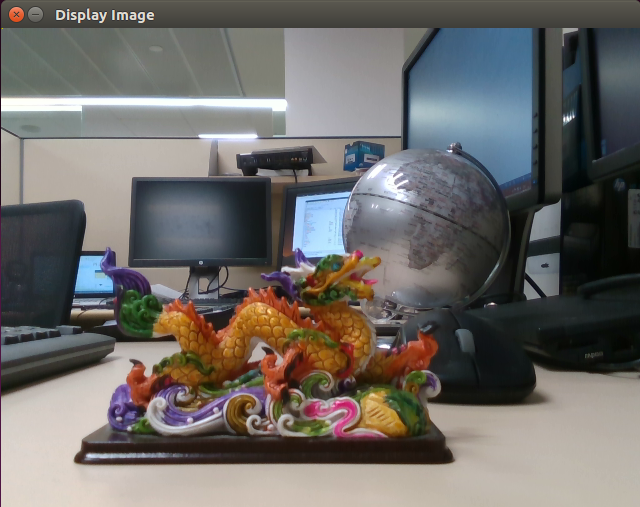
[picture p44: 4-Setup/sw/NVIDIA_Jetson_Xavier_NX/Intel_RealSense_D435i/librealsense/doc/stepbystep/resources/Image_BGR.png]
BGR_Image


## Displaying Infrared Frame

Displaying Infrared and Depth data is not very different from Color data. Infrared frame is a single channel, 8 bits-per-pixel image.
Copy the following code snippet into IR_sample.cpp:

```cpp
// include the librealsense C++ header file
#include <librealsense2/rs.hpp>

// include OpenCV header file
#include <opencv2/opencv.hpp>

using namespace std;
using namespace cv;

int main()
{
    //Contruct a pipeline which abstracts the device
    rs2::pipeline pipe;

    //Create a configuration for configuring the pipeline with a non default profile
    rs2::config cfg;

    //Add desired streams to configuration
    cfg.enable_stream(RS2_STREAM_INFRARED, 640, 480, RS2_FORMAT_Y8, 30);
    cfg.enable_stream(RS2_STREAM_DEPTH, 640, 480, RS2_FORMAT_Z16, 30);

    //Instruct pipeline to start streaming with the requested configuration
    pipe.start(cfg);

    // Camera warmup - dropping several first frames to let auto-exposure stabilize
    rs2::frameset frames;
    for(int i = 0; i < 30; i++)
    {
        //Wait for all configured streams to produce a frame
        frames = pipe.wait_for_frames();
    }

    //Get each frame
    rs2::frame ir_frame = frames.first(RS2_STREAM_INFRARED);
    rs2::frame depth_frame = frames.get_depth_frame();

    // Creating OpenCV matrix from IR image
    Mat ir(Size(640, 480), CV_8UC1, (void*)ir_frame.get_data(), Mat::AUTO_STEP);

    // Apply Histogram Equalization
    equalizeHist( ir, ir );
    applyColorMap(ir, ir, COLORMAP_JET);

    // Display the image in GUI
    namedWindow("Display Image", WINDOW_AUTOSIZE );
    imshow("Display Image", ir);

    waitKey(0);

    return 0;
}
```

Compile and run the program from the terminal, with the following command:

```shell
g++ -std=c++11 IR_sample.cpp -lrealsense2 -lopencv_core -lopencv_imgproc -lopencv_highgui -o ir && ./ir
```

**Result :**

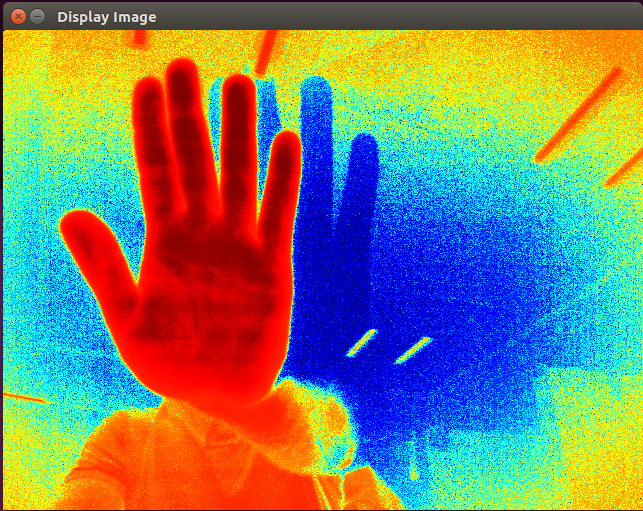
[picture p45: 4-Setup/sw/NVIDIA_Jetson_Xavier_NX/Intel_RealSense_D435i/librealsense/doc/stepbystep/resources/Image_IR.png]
IR_Image2


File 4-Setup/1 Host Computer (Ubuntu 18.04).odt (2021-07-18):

Host Computer

Any computer running Ubuntu (https://ubuntu.com/) 18.04 with a working internet connection will do as the host computer for the software setup. But if the host computer is also intended for development later on, then a recent desktop computer with an NVIDIA graphics card would be required. We used a desktop computer with: i7 CPU, SSD drive, 32GB RAM and NVIDIA GeForce GTX 1660 GPU.

# Ubuntu

Install Ubuntu 18.04 LTS

Firefox: https://releases.ubuntu.com/18.04

> Click 64-bit PC (AMD64) desktop image

> Save File

Downloads/ubuntu-18.04.5-desktop-amd64.iso

Insert USB flash drive

Ubuntu: Startup Disk Creator

> Select Source disc image (.iso) Ubuntu 18.04.5 LTS

> Select Disk to use USB

> Click Make Startup Disk

Take out USB flash drive

Put USB flash drive into host computer

Power up

During boot enter BIOS setup (DEL)

> BIOS: Set date/time (Settings / System Status)

> BIOS: Change boot sequence to start with USB flash drive

Ubuntu: Click Install Ubuntu

> Select English

> Select Keyboard layout English US English US

> Select Normal installation

> Select Download updates while installing Ubuntu

> Check Erase disk and install Ubuntu

> Select Select drive: SSD

> Select Where are you?

> Enter Your name

> Enter Your computer's name

> Enter Pick a username

> Enter Choose a password

Ubuntu: reboot

Take out USB flash drive

During boot enter BIOS setup (DEL)

> BIOS: Change boot sequence to start with SSD

$: sudo apt update

$: sudo apt upgrade

# OPTIONAL: Software Setup

## Hookup

Set up the sensors & processing board without the cover as described in the hardware assembly.

Connect the SparkFun RedBoard Turbo Development Board from its USB port with a 90° micro USB to USB cable to a USB port on the Host Computer. Connect the USB cable from the Intel RealSense D435i to a USB port on the Host Computer. Connect the USB cable from the GroupGets Pure Thermal 2 to a USB port on the Host Computer.

## Our SensorBox Repository

Clone our SensorBox repository from GitHub

DATA/projects$: git clone https://github.com/AIWerkstatt/SensorBox.git

DATA/projects$: cd SensorBox/4-Setup

## NVIDIA Graphics Card

Install NVIDIA Graphics Card Driver

Ubuntu: Software & Updates

> Select"Additional Drivers"

> Check "NVIDIA Corporation: TU116[GeForce GTX 1660]" "Using NVIDIA driver meta package from nvidia-driver-450 (proprietary, tested)"

> Click "Apply changes"

Ubuntu: Reboot

$: nvidia-smi

+-----------------------------------------------------------------------------------------------+

| NVIDIA-SMI 450.80.02 Driver Version: 450.80.02 CUDA Version: 11.0 |

…

## Scripts

The scripts specific to the host computer are located in the folder sw/Host_Computer/Scripts.

Run all install scripts

sw/Host_Computer/Scripts$: bash install.sh

Reboot

## Docker

Install Docker

sw/Host_Computer/Docker$: bash install-Docker.sh

Install NVIDIA Container Toolkit

sw/Host_Computer/Docker$: bash install-NVIDIA_Container_Toolkit.sh

Create a Docker identification (https://hub.docker.com/signup).

The Dockerfiles specific to the host computer are located in the folder sw/Host_Computer/Docker.

Build a Docker image with all Dockerfiles

sw/Host_Computer/Docker$: bash build-Docker.sh

We based the development environment on the NVIDIA’s Ubuntu 18.04 LTS with CUDA and OpenGL Image (https://ngc.nvidia.com/catalog/containers/nvidia:cudagl).

Set up udev rules on Docker Host (only once)

sw/Host_Computer/Docker$: bash install-udev_rules-Host.sh

Reboot

Run the Docker container

sw/Host_Computer/Docker$: bash run-Docker.sh

The Docker container is run as a bash terminal (interactive mode) under the current user (same user id, group id and home folder), using the same network as the host computer and forwarding the display to the X server on the host computer with the proper access to the host computers resources.

aiWerkstatt (http://www.aiwerkstatt.com/)TM SensorBoxTM v1.0 3/3

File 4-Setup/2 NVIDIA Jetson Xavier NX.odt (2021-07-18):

NVIDIA Jetson Xavier NX

We use the (https://www.nvidia.com/)NVIDIA (https://www.nvidia.com/) Jetson Xavier NX development kit (https://www.nvidia.com/en-us/autonomous-machines/embedded-systems/jetson-xavier-nx/).

Join the NVIDIA DEVELOPER Membership program (https://developer.nvidia.com/developer-program) to get access to all NVIDIA resources.

NVIDIA Jetson Xavier NX resources:

- User G (https://developer.download.nvidia.com/assets/embedded/secure/jetson/Xavier%20NX/Jetson_Xavier_NX_Developer_Kit_User_Guide.pdf)u (https://developer.download.nvidia.com/assets/embedded/secure/jetson/Xavier%20NX/Jetson_Xavier_NX_Developer_Kit_User_Guide.pdf)ide (https://developer.download.nvidia.com/assets/embedded/secure/jetson/Xavier%20NX/Jetson_Xavier_NX_Developer_Kit_User_Guide.pdf)
- Carrier Board Specification (https://developer.download.nvidia.com/assets/embedded/secure/jetson/Xavier%20NX/Jetson_Xavier_NX_DevKit_Carrier_Board_Specification_v1.0.pdf)
- SDK Manager (https://docs.nvidia.com/sdk-manager)
- J (https://docs.nvidia.com/jetson/l4t/index.html)etson Linux Developer Guide (https://docs.nvidia.com/jetson/l4t/index.html)
- C (https://developer.nvidia.com/embedded/jetson-cloud-native)loud-Native on Jetson (https://developer.nvidia.com/embedded/jetson-cloud-native)

Jetsonhacks (https://www.jetsonhacks.com/) provides useful information and YouTube (https://www.youtube.com/channel/UCQs0lwV6E4p7LQaGJ6fgy5Q) videos on how to use the NVIDIA Jetson.

# Hookup

Set up the sensors & processing board without the cover as described in the hardware assembly.

# NVIDIA SDK Manager

We use the NVIDIA SDK Manager (https://docs.nvidia.com/sdk-manager) to flash the NVIDIA Jetson Xavier NX and to set up the NVIDIA development environment on the host computer and the NVIDIA Jetson Xavier NX.

Set up NVIDIA Jetson Xavier NX development board

Connect the USB dongle of the Dual USB & Bluetooth Keyboard and Mouse (https://www.amazon.com/gp/product/B0899DRDYR/ref=ppx_yo_dt_b_asin_title_o07_s00?ie=UTF8&psc=1) to a USB port of the NVIDIA Jetson Xavier NX Development Board.

Insert the micro SD card (https://www.amazon.com/Samsung-MicroSD-Adapter-MB-ME64GA-AM/dp/B06XX29S9Q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) into the micro SD slot on the underside (facing the front of the SensorBox) of the NVIDIA Jetson Xavier NX module.

Use a Circuit Jumper Cap (https://www.amazon.com/gp/product/B077957RN7/ref=ppx_yo_dt_b_search_asin_title?ie=UTF8&psc=1&fpw=alm) or Jumper Wire (https://www.amazon.com/Elegoo-EL-CP-004-Multicolored-Breadboard-arduino/dp/B01EV70C78) to place a jumper across the Force Recovery Mode pins 9 and 10 on the button header J14 on the NVIDIA Jetson Xavier NX Development Board.

Power on the NVIDIA Jetson Xavier NX by pushing the push button. The NVIDIA Jetson Xavier NX powers on in Force Recovery Mode.

Remove the jumper from the Force Recover Mode pins.

Download and run SDK Manager on the Host Computer

$: lsusb

ID 0955:7020 NVidia Corp.

Firefox: https://login.developer.nvidia.com

> Click Account

> Enter Email and Password

Firefox: https://developer.nvidia.com/nvidia-sdk-manager

> Download NVIDIA SDK Manager 1.5 > .deb Ubuntu

> Save File

An already downloaded copy can be found here:

sw/Host_Computer/NVIDIA_SDKManager/sdkmanager_1.5.0-7774_amd64.deb

sw/Host_Computer/NVIDIA_SDKManager$: sudo apt install ./sdkmanager_1.5.0-7774_amd64.deb

$: sdkmanager

Ubuntu: Right-Click SDK Manager icon and select Add to Favorites

> Login to NVIDIA Developer

> Login & Password

> Step 01

> Select Target Hardware Jetson Xavier NX [developer Kit version] (detected)

> Select Linux Jetpack 4.5.1

> Check DeepStream

> Step 02

> Check I accept the terms and conditions of the license agreements.

> SUDO Password

Step 03 … takes quite some time

> Select Manual Setup

> Flash

Configure Linux for Tegra (L4T)

Ubuntu System Configuration on NVIDIA Jetson Xavier NX

> Accept NVIDIA Jetson software EULA

> Select system language, keyboard layout, and time zone

> Your name: nx

> Your computer’s name: nx

> Username:nx

> Password:nx

> Check Log in automatically

> Accept max APP Partition Size

> Mode_15W_6Core

Finish running the SDK Manager

SDK Manager on Host Computer

> Enter Username: nx

> Enter Password: nx

> Install ... takes quite some time

Step 04

> Finish and Exit

Power off/on the NVIDIA Jetson Xavier NX

$: shutdown -h now

Cut the power off using the push button.

Power on the NVIDIA Jetson Xavier NX using the push button.

Update Software

Ubuntu: Software Updater

> Click Install Now

$: sudo apt-get update

$: sudo apt-get upgrade

Open Access

Ubuntu: Click on System Settings Icon (left)

> Click on Brightness & Lock

> Select Turn screen off when active for Never

> Select Lock Off

> Un-check Require my password when waking from suspense

Disable Keychain

When selecting log in automatically in the Ubuntu configuration, you will be asked to enter the keychain password each time after booting when you want to use the Chromium internet browser. If you set the password to blank this goes away.

Ubuntu: Search for password and keys

> Right-click Login > Change Password

> Enter the old password

> Enter a blank new password

# Wifi

Ubuntu: Click on Network Icon (top right) and select network

> Enter password

Now you can disconnect the USB cable (https://www.amazon.com/gp/product/B00HSS9L6G/ref=ppx_yo_dt_b_asin_title_o04_s00?ie=UTF8&psc=1) from your host computer.

# Bluetooth Keyboard and Mouse

Ubuntu: Click on Bluetooth Icon (top right) and select Bluetooth Settings

> Click on + icon to search for new devices

Keyboard: Turn on

Keyboard: Press Bluetooth 1 key (top right) for 5 seconds

> Select Dual-mode Keyboard (using mouse)

> Next

> Click on + icon to search for new devices

Mouse: Turn on

Mouse: Use button to select Bluetooth 1

Mouse: Press button for 5 seconds

> Select Dual-mode Mouse (using Tab and arrows keys on the keyboard)

> Hit Enter

Unplug the USB dongle from the USB port of the NVIDIA Jetson Xavier NX.

# SSD Drive

The NVIDIA Jetson Xavier NX does not allow yet to boot directly from the SSD drive, so we copy the rootfs from the SD card to the SSD drive and install a service that switches the rootfs to the SSD drive after booting. The NVIDIA Jetson Xavier NX is still booting from the SD card, but runs from the SSD drive. This setup should be done on fresh installs of the SD card.

We followed JetsonHacks (https://www.jetsonhacks.com/) instructions from Run from SSD (https://www.jetsonhacks.com/2020/05/29/jetson-xavier-nx-run-from-ssd/) and used their scripts from their GitHub rootOnNVMe (https://github.com/jetsonhacks/rootOnNVMe) repository.

The SSD drive was already installed during hardware assembly.

Format the SSD drive

Ubuntu: Disks

> Select 500 GB Disk (Samsung SSD 970 EVO Plus 500GB)

> Click menu icon top right and select Format Disk

> Click Format…

> Click Format

> Click on + icon to add a partition

> Select 500GB

> Enter Volume Name: ssd

> Check Internal disk for use with Linux systems only (Ext4)

> Click Create

Clone the scripts from JetsonHacks GitHub repository

sw/NVIDIA_Jetson_Xavier_NX/SSD$: git clone https://github.com/jetsonhacks/rootOnNVMe.git

An already cloned repository can be found here:

sw/NVIDIA_Jetson_Xavier_NX/SSD/rootOnNVMe

Copy the rootfs from the SD card to the SSD drive

sw/NVIDIA_Jetson_Xavier_NX/SSD/rootOnNVMe$: bash copy-rootfs-ssd.sh

Set up the service that switches the rootfs to the SSD drive after booting

sw/NVIDIA_Jetson_Xavier_NX/SSD/rootOnNVMe$: bash setup-service.sh

$: reboot

To start over with a fresh installation (basically your installation on the SD card) just remove the file /etc/setssdroot.conf from the SD card, which sets the rootfs back to the SD card after the next boot. Then follow these instruction to install the SSD drive again.

# Power Management

Check out power management (https://docs.nvidia.com/jetson/l4t/index.html) in the Jetson Linux Developer Guide.

We chose the 15W 6 CPU @1400MHz profile.

$: sudo /usr/sbin/nvpmodel -m 2

$: sudo /usr/sbin/nvpmodel -q

NV Fan Mode:quiet

NV Power Mode: MODE_15W_6CORE

2

# System Monitoring

Check out software-based power consumption modeling (https://docs.nvidia.com/jetson/l4t/index.html) in the Jetson Linux Developer Guide for using the INA3221 power monitor at I2C address 0x40.

Channel 0: System 5V

$: cat /sys/bus/i2c/drivers/ina3221x/7-0040/iio\:device0/in_current0_input

976 [mA]

$: cat /sys/bus/i2c/drivers/ina3221x/7-0040/iio\:device0/in_voltage0_input

5144 [mV]

$: cat /sys/bus/i2c/drivers/ina3221x/7-0040/iio\:device0/in_power0_input

4979 [mW]

Channel 1: CPU & GPU combined power

$: cat /sys/bus/i2c/drivers/ina3221x/7-0040/iio\:device0/in_current1_input

136 [mA]

$: cat /sys/bus/i2c/drivers/ina3221x/7-0040/iio\:device0/in_voltage1_input

5144 [mV]

$: cat /sys/bus/i2c/drivers/ina3221x/7-0040/iio\:device0/in_power1_input

699 [mW]

Channel 2: SoC power rail

$: cat /sys/bus/i2c/drivers/ina3221x/7-0040/iio\:device0/in_current2_input

248 [mA]

$: cat /sys/bus/i2c/drivers/ina3221x/7-0040/iio\:device0/in_voltage2_input

5136 [mV]

$: cat /sys/bus/i2c/drivers/ina3221x/7-0040/iio\:device0/in_power2_input

1314 [mW]

Check out (https://docs.nvidia.com/jetson/l4t/index.html)tegrastats utility (https://docs.nvidia.com/jetson/l4t/index.html) in Jetson Linux Developer Guide.

$: tegrastats

RAM 2088/7766MB (lfb 612x4MB) SWAP 0/3883MB (cached 0MB) CPU [13%@1420,14%@1420,8%@1420,14%@1420,14%@1420,9%@1420] EMC_FREQ 0% GR3D_FREQ 0% AO@42C GPU@42C PMIC@100C AUX@43C CPU@42.5C thermal@42.55C

## jtop

Raffaello Bonghi (https://github.com/rbonghi) provides jetson_stats, a python package to monitor and control the Jetson platform, on GitHub (https://github.com/rbonghi/jetson_stats).

Install jetson-stats

$: sudo apt-get install python-pip

$: sudo -H pip install -U jetson-stats

reboot

Monitor the system

$: jtop

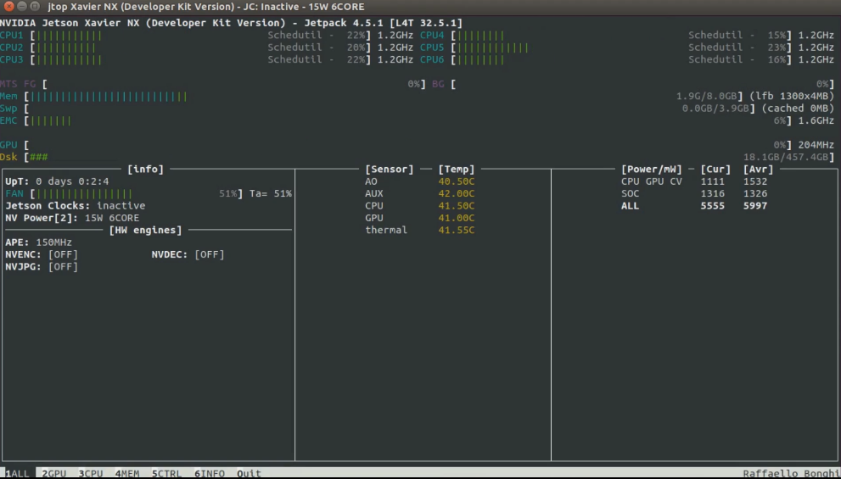
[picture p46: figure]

# Software Setup

## Our SensorBox Repository

Clone our SensorBox repository from GitHub

DATA/projects$: git clone https://github.com/AIWerkstatt/SensorBox.git

DATA/projects$: cd SensorBox/4-Setup

## Scripts

The scripts are located in the folder sw/NVIDIA_Jetson_Xavier_NX/Scripts.

Run all install scripts

sw/NVIDIA_Jetson_Xavier_NX/Scripts$: bash install.sh

Reboot

Run Basic Ubuntu installation script

sw/NVIDIA_Jetson_Xavier_NX/Scripts$: bash install-1-Ubuntu.sh

## Docker

NVIDIA JetPack includes NVIDIA container runtime with Docker (https://www.docker.com/) integration, enabling GPU accelerated containerized applications on the Jetson platform.

Create a Docker identification (https://hub.docker.com/signup).

The Dockerfiles are located in the folder sw/NVIDIA_Jetson_Xavier_NX/Docker.

Build a Docker image with all Dockerfiles

sw/NVIDIA_Jetson_Xavier_NX/Docker$: bash build-Docker.sh

We based the development environment on the NVIDIA' (https://ngc.nvidia.com/catalog/containers/nvidia:l4t-base)s (https://ngc.nvidia.com/catalog/containers/nvidia:l4t-base) L4T Base Image (https://ngc.nvidia.com/catalog/containers/nvidia:l4t-base).

Set up udev rules on Docker Host (only once)

sw/NVIDIA_Jetson_Xavier_NX/Docker$: bash install-udev_rules-Host.sh

Reboot

Run the Docker container

sw/NVIDIA_Jetson_Xavier_NX/Docker$: bash run-Docker.sh

The Docker container is run as a bash terminal (interactive mode) under the current user (same user id, group id and home folder), using the same network as the host computer and forwarding the display to the X server on the host computer with the proper access to the host computers resources.

Basic Ubuntu Dockerfile

sw/NVIDIA_Jetson_Xavier_NX/Docker/Dockerfile-1-Ubuntu

aiWerkstatt (http://www.aiwerkstatt.com/)TM SensorBoxTM v1.0 6/7

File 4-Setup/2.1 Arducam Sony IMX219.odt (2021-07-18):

Arducam Sony IMX219 Camera Modules

We use two (2) Arducam (https://www.arducam.com/) Sony (https://www.arducam.com/product/b0191-arducam-imx219-visible-light-fixed-focus-camera-module-nvidia-jetson-nano-raspberry-pi-compute-module/)IMX219 Camera Modul (https://www.arducam.com/product/b0191-arducam-imx219-visible-light-fixed-focus-camera-module-nvidia-jetson-nano-raspberry-pi-compute-module/)es (https://www.arducam.com/product/b0191-arducam-imx219-visible-light-fixed-focus-camera-module-nvidia-jetson-nano-raspberry-pi-compute-module/). The NVIDIA Jetson XAVIER NX supports the IMX219 MIPI (Mobile Industry Processor Interface) - CSI (Camera Serial Interface) out-of-the-box.

# Script

Run Arducam Sony IMX219 Camera Module installation script

sw/NVIDIA_Jetson_Xavier_NX/Scripts$ bash install-3-Arducam_Sony_IMX219.sh

# Dockerfile

Arducam Sony IMX219 Camera Module Dockerfile

sw/NVIDIA_Jetson_Xavier_NX/Docker/Dockerfile-3-Arducam_Sony_IMX219

# v4l-utils

v4l-utils (https://linuxtv.org/wiki/index.php/V4l-utils) provides linux utilities and libraries to handle video devices.

List all video devices

$: v4l2-ctl --list-devices

vi-output, imx219 9-0010 (platform:15c10000.vi:0):

/dev/video0

vi-output, imx219 10-0010 (platform:15c10000.vi:2):

/dev/video1

PureThermal (fw:v1.3.0) (usb-3610000.xhci-2.1):

/dev/video5

Intel® RealSense(TM) Depth Ca (usb-3610000.xhci-3.2):

/dev/video2

/dev/video3

/dev/video4

Query a video device’s information

$: v4l2-ctl -d0 -D

Driver Info (not using libv4l2):

Driver name : tegra-video

Card type : vi-output, imx219 9-0010

Bus info : platform:15c10000.vi:0

Driver version: 4.9.201

Capabilities : 0x84200001

Video Capture

Streaming

Extended Pix Format

Device Capabilities

Device Caps : 0x04200001

Video Capture

Streaming

Extended Pix Format

# gstreamer

The Arducam Sony IMX219 camera module works out-of-the-box with gstreamer (https://gstreamer.freedesktop.org/).

List video devices

$: ls /dev/video*

View Imagery

$: gst-launch-1.0 nvarguscamerasrc sensor-id=0 ! 'video/x-raw(memory:NVMM),width=3264, height=2464, framerate=21/1, format=NV12' ! nvvidconv flip-method=0 ! 'video/x-raw, width=816, height=616' ! nvvidconv ! nvegltransform ! nveglglessink -e

$: gst-launch-1.0 nvarguscamerasrc sensor-id=1 ! 'video/x-raw(memory:NVMM),width=3264, height=2464, framerate=21/1, format=NV12' ! nvvidconv flip-method=0 ! 'video/x-raw, width=816, height=616' ! nvvidconv ! nvegltransform ! nveglglessink -e

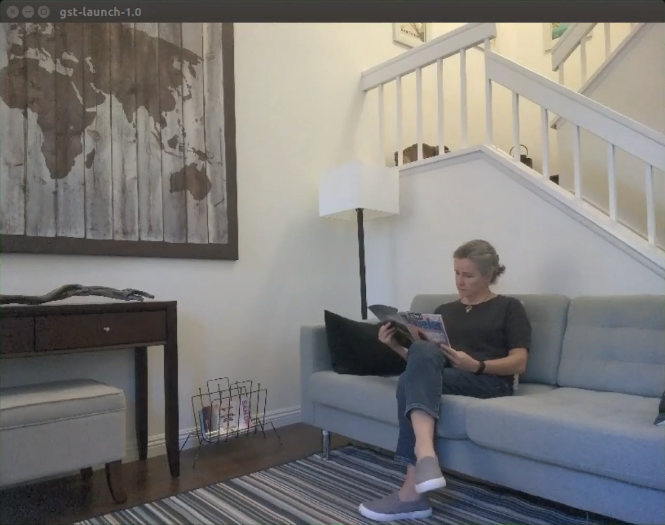
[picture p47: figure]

aiWerkstatt (http://www.aiwerkstatt.com/)TM SensorBoxTM v1.0 2/2

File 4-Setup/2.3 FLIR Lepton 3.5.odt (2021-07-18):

FLIR Lepton 3.5

We use the FLIR (https://www.flir.com/) Lepton 3.5 (https://store.groupgets.com/collections/frontpage/products/flir-lepton-3-5) with GroupGets (https://groupgets.com/manufacturers/getlab) PureT (https://store.groupgets.com/products/purethermal-2)h (https://store.groupgets.com/products/purethermal-2)ermal 2 FLIR Lepton Smart I/O Module (https://store.groupgets.com/products/purethermal-2) that provides a USB 2 interface for the FLIR Lepton product series.

FLIR Lepton 3.5 resources:

- FLIR Lepton 3.5 (https://www.flir.com/products/lepton/?model=3.5%20Lepton)
- FLIR Lepton Datasheet (https://groupgets-files.s3.amazonaws.com/lepton/Resources/500-0659-00-09%20Rev204%20Lepton%20Engineering%20Datasheet.pdf)
- FLIR Lepton Google Group (https://groups.google.com/g/flir-lepton)

GroupGets PureThermal 2 resources:

- PureThermal 2 (https://groupgets.com/manufacturers/getlab/products/purethermal-2-flir-lepton-smart-i-o-module)
- PureThermal 2 Datasheet (https://groupgets-files.s3.amazonaws.com/PT2/PureThermal%202%20-%20Datasheet%20-%201.6.pdf)
- PureThermal 1/2/mini Firmware (https://github.com/groupgets/purethermal1-firmware)
- PureThermal 2 libuvc (https://github.com/groupgets/libuvc)
- libuvc Documentation (https://ken.tossell.net/libuvc/doc/)
- PureThermal (https://github.com/groupgets/purethermal1-uvc-capture)2 (https://github.com/groupgets/purethermal1-uvc-capture)UVC Capture Examples (https://github.com/groupgets/purethermal1-uvc-capture)
- GetThermal (https://github.com/groupgets/GetThermal)

# Script

Run FLIR Lepton installation script

sw/NVIDIA_Jetson_Xavier_NX/Scripts$ bash install-5-FLIR_Lepton_3.5.sh

# Dockerfile

FLIR Lepton Dockerfile

sw/NVIDIA_Jetson_Xavier_NX/Docker/Dockerfile-5-FLIR_Lepton_3.5

# PureThermal 2 Firmware v1.3.0 (USB via DFU-Mode)

GroupGets provides the source code and binaries of the firmware on GitHub (https://github.com/groupgets/purethermal1-firmware).

Download binaries of the firmware v1.3.0

Firefox: https://github.com/groupgets/purethermal1-firmware/releases

> Click pt1-v1.3.0.tar.gz (https://github.com/groupgets/purethermal1-firmware/releases/download/1.3.0/pt1-v1.3.0.tar.gz)

$: tar -xf pt1-v1.3.0.tar.gz

An already downloaded copy can be found here:

sw/NVIDIA_Jetson_Xavier_NX/FLIR_Lepton_3.5/pt1-v1.3.0

Enter bootloader DFU-Mode

> Press and hold the BOOT button while plugging the USB cable from PureThermal 2 into the host computer

> Press and release the RST button

> Release the BOOT button

LED stops blinking and dim to half brightness

Flash

$: sudo apt-get install dfu-util

$: dfu-util --list

Found DFU: [0483:df11]

$: cd sw/NVIDIA_Jetson_Xavier_NX/FLIR_Lepton_3.5/pt1-v1.3.0

.../pt1-v1.3.0$: dfu-util -a 0 -d 0483:df11 -D pt1-v1.3.0.bin -s 0x08000000

# v4l-utils

v4l-utils (https://linuxtv.org/wiki/index.php/V4l-utils) provides linux utilities and libraries to handle video devices.

List all video devices

$: v4l2-ctl --list-devices

vi-output, imx219 9-0010 (platform:15c10000.vi:0):

/dev/video0

vi-output, imx219 10-0010 (platform:15c10000.vi:2):

/dev/video1

PureThermal (fw:v1.3.0) (usb-3610000.xhci-2.1):

/dev/video5

Intel® RealSense(TM) Depth Ca (usb-3610000.xhci-3.2):

/dev/video2

/dev/video3

/dev/video4

Query a video device’s information

$: v4l2-ctl -d5 -D

Driver Info (not using libv4l2):

Driver name : uvcvideo

Card type : PureThermal (fw:v1.3.0)

Bus info : usb-3610000.xhci-2.1

Driver version: 4.9.201

Capabilities : 0x84200001

Video Capture

Streaming

Extended Pix Format

Device Capabilities

Device Caps : 0x04200001

Video Capture

Streaming

Extended Pix Format

# gstreamer

The FLIR Lepton 3.5 with the GroupGets PureThermal 2 works out-of-the-box with gstreamer (https://gstreamer.freedesktop.org/).

View Imagery

$: gst-launch-1.0 v4l2src device=/dev/video5 ! videoconvert ! xvimagesink

When running the realsense-viewer for the Intel RealSense D435i, the video device /dev/video5 of the thermal camera disappears and can no longer be accessed directly. uvc-radiometry.py and GetThermal still work. Reboot and the video devices reappear.

# USB video class (UVC)

GroupGets provides a modified version of the libuvc (https://ken.tossell.net/libuvc/doc/) for the PureThermal 2 on GitHub (https://github.com/groupgets/libuvc).

Clone libuvc repository from GitHub

sw/NVIDIA_Jetson_Xavier_NX/FLIR_Lepton_3.5$: git clone https://github.com/groupgets/libuvc

Un-comment the following lines in the CMakeLists.txt:

find_package(jpeg QUIET)

if(NOT JPEG_FOUND)

find_path(JPEG_INCLUDE_DIR jpeglib.h)

if(JPEG_INCLUDE_DIR)

set(JPEG_FOUND ON)

set(JPEG_LIBRARIES -ljpeg)

endif()

endif()

$: lsusb

Bus 003 Device 006: ID 1e4e:0100 Cubeternet WebCam

Add a 99-pt2.rules file with the following content:

SUBSYSTEMS=="usb", ATTRS{idVendor}=="1e4e", ATTRS{idProduct}=="0100", SYMLINK+="pt2", GROUP="usb", MODE="0666"

An already downloaded and modified copy can be found here:

sw/NVIDIA_Jetson_Xavier_NX/FLIR_Lepton_3.5/libuvc

The libuvc is put under /opt/FLIR_Lepton_3.5/libuvc and is installed under usr/local.

# GroupGets UVC capture examples

GroupGets provides UVC capture examples on GitHub (https://github.com/groupgets/purethermal1-uvc-capture).

Clone UVC capture examples repository from GitHub

sw/NVIDIA_Jetson_Xavier_NX/FLIR_Lepton_3.5$: git clone https://github.com/groupgets/purethermal1-uvc-capture.git

Modify python/uvc-radiometry.py to change from Kelvin to Celsius

def display_temperature(img, val_k, loc, color):

val = ktoc(val_k)

cv2.putText(img,"{0:.1f} degC".format(val), loc, cv2.FONT_HERSHEY_SIMPLEX, 0.75, color, 2)

An already downloaded and modified copy can be found here:

sw/NVIDIA_Jetson_Xavier_NX/FLIR_Lepton_3.5/purethermal1-uvc-capture

The UVC capture examples are put under /opt/FLIR_Lepton_3.5/purethermal1-uvc-capture.

Print the Lepton's software and hardware version information

$: /opt/FLIR_Lepton_3.5/purethermal1-uvc-capture/python/uvc-deviceinfo.py

Version gpp: 3.3.26 dsp: 3.3.26

FLIR part #: 500-0771-01

FLIR serial #: '\xe037\x01\x00\x00\x00\x00'

Run OpenCV example

$: /opt/FLIR_Lepton_3.5/purethermal1-uvc-capture/python/opencv-capture.py

If Camera not found!, unplug and reconnect USB cable.

It searches from video index 9 down to 0, so when multiple cameras are connected, it only connects to the last one, which might not be the thermal camera.

Run min/max temperature example

$: /opt/FLIR_Lepton_3.5/purethermal1-uvc-capture/python/uvc-radiometry.py

Version gpp: 3.3.26 dsp: 3.3.26

FLIR part #: 500-0771-01

FLIR serial #: '\xe037\x01\x00\x00\x00\x00'

format: UYVY

frame 160x120 @ 9fps

format: Y16

frame 160x120 @ 9fps

frame 160x122 @ 9fps

format: Y8

frame 160x120 @ 9fps

format: RGBP

frame 160x120 @ 9fps

format: }�6�

frame 160x120 @ 9fps

Estimated / selected altsetting bandwith : 18 / 642.

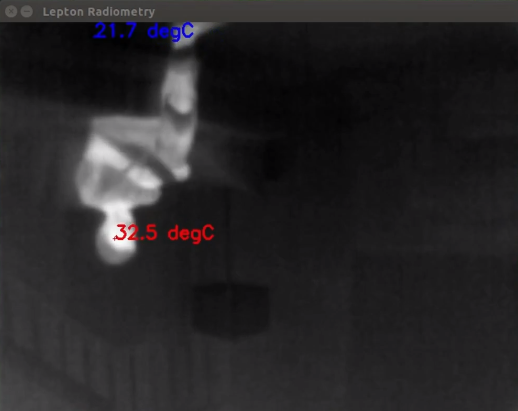
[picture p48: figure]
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

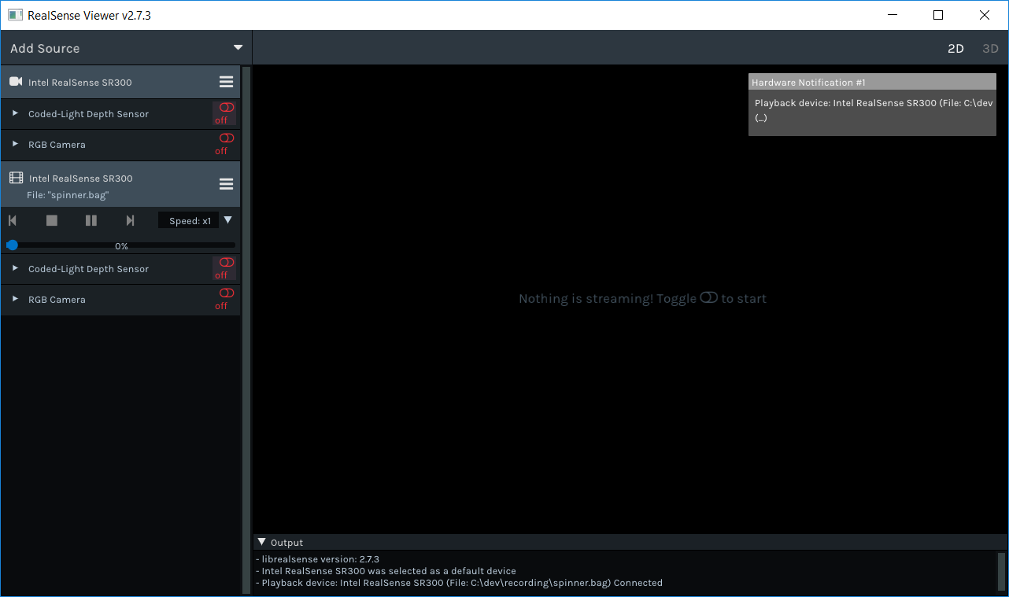
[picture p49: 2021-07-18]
4-Setup/sw/NVIDIA_Jetson_Xavier_NX/Intel_RealSense_D435i/librealsense/doc/img/playback_screenshot.png

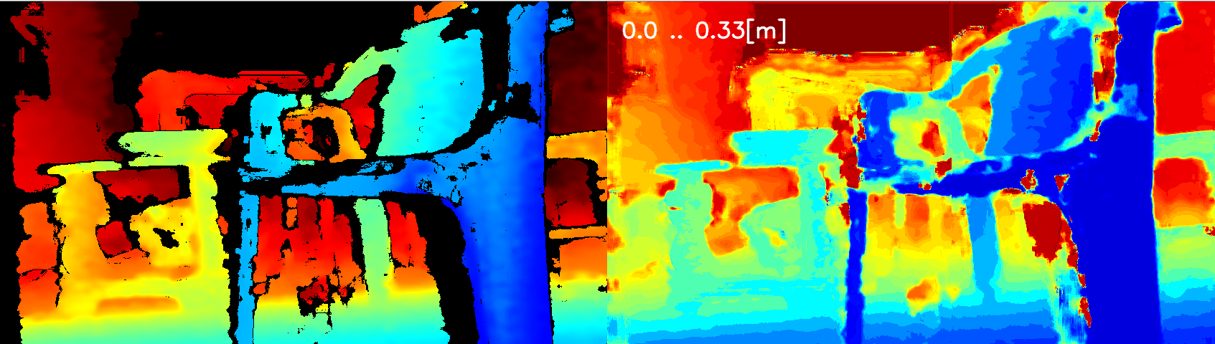
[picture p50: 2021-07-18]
4-Setup/sw/NVIDIA_Jetson_Xavier_NX/Intel_RealSense_D435i/librealsense/wrappers/tensorflow/images/camera_simulation_05.PNG

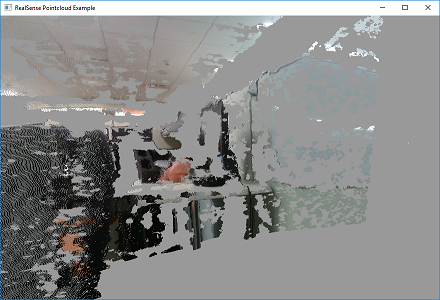
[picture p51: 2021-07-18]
4-Setup/sw/NVIDIA_Jetson_Xavier_NX/Intel_RealSense_D435i/librealsense/doc/img/windows_pointcloud_preview.PNG

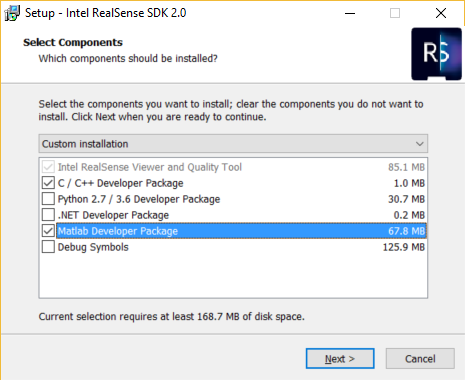
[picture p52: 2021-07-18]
4-Setup/sw/NVIDIA_Jetson_Xavier_NX/Intel_RealSense_D435i/librealsense/doc/img/matlab_select.png

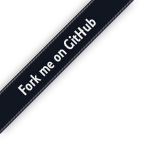
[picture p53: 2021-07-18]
4-Setup/sw/NVIDIA_Jetson_Xavier_NX/Intel_RealSense_D435i/librealsense/wrappers/unity/Assets/RealSenseSDK2.0/Misc/Textures/forkme_left_darkblue_121621.png

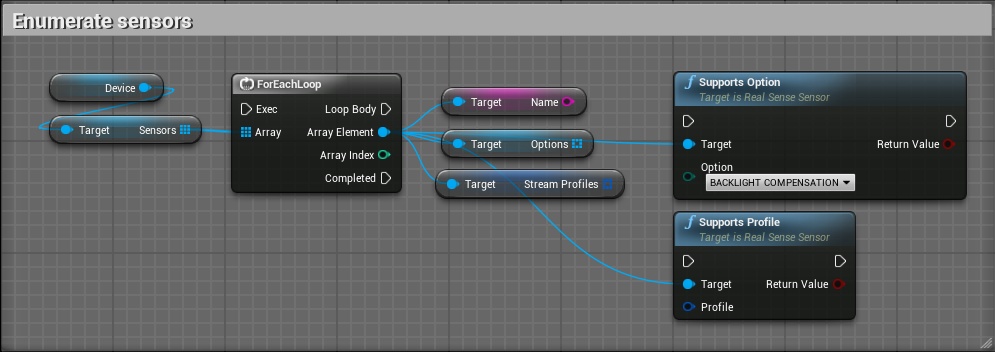
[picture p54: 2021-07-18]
4-Setup/sw/NVIDIA_Jetson_Xavier_NX/Intel_RealSense_D435i/librealsense/wrappers/unrealengine4/doc/img/bp_enum_sensors.jpg

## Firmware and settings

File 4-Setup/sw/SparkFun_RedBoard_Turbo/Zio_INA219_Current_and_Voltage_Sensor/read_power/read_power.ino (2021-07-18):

/* 
  Read current in Ampere, voltage in Volt and power in Watt at 1Hz 
  from the Zio INA219 Current and Voltage Sensor.
  
  MIT License
  Copyright (C) 2021 aiWerkstatt(TM)
  www.aiWerkstatt.com
*/

#include <Wire.h>
#include <Adafruit_INA219.h>

Adafruit_INA219 power_sensor;

void setup() 
{
  SerialUSB.begin(115200);
  while(!SerialUSB);

  Wire.begin();
  Wire.setClock(400000);
  delay(500);
        
  /* Connect to Zio INA 219 Current and Voltage Sensor */
  if (!power_sensor.begin()) {
    SerialUSB.println("Can not connect to Zio INA 219 Current and Voltage Sensor");
    while(1);
  }  
  
  SerialUSB.println("Zio INA 219 Current and Voltage Sensor");
  delay(100);
}

void loop(void) 
{
  float shuntvoltage = 0.0;
  float busvoltage = 0.0;
  float current_mA = 0.0;
  float loadvoltage = 0.0;
  float power_mW = 0.0;

  shuntvoltage = power_sensor.getShuntVoltage_mV();
  busvoltage = power_sensor.getBusVoltage_V();
  current_mA = power_sensor.getCurrent_mA();
  power_mW = power_sensor.getPower_mW();
  loadvoltage = busvoltage + (shuntvoltage / 1000.0);
  
  SerialUSB.print("Bus Voltage [V]: "); 
  SerialUSB.print(busvoltage);
  SerialUSB.print(" Shunt Voltage [mV]: "); 
  SerialUSB.print(shuntvoltage);
  SerialUSB.print(" Load Voltage [V]: "); 
  SerialUSB.print(loadvoltage);
  SerialUSB.print(" Current [mA]: "); 
  SerialUSB.print(current_mA);
  SerialUSB.print(" Power [mW]: "); 
  SerialUSB.print(power_mW);
  SerialUSB.println();

  delay(1000);
}

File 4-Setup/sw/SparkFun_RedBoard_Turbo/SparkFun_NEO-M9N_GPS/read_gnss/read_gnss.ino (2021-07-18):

/*
  Read latitude in degrees, longitude in degrees, altitude in meter,
  fix type (no fix, dead reckoning, 2D, 3D, GNSS + Dead reckoning, Time only),
  ground speed in meter per seconds, heading in degrees,
  dilution of precision, number of satellites used in fix,
  and date and time at 1Hz
  from the SparkFun NEO-M9N GPS.

  MIT License
  Copyright (C) 2021 aiWerkstatt(TM)
  www.aiWerkstatt.com
 */

#include <Wire.h>
#include <SparkFun_u-blox_GNSS_Arduino_Library.h>

SFE_UBLOX_GNSS gnss;

long last_time = 0;

void setup()
{
  SerialUSB.begin(115200);
  while (!SerialUSB);
  
  Wire.begin();
  Wire.setClock(400000);
  delay(500);

  if (!gnss.begin())
  {
    SerialUSB.println("Can not connect to SparkFun NEO-M9N GPS");
    while (1);
  }
  
  SerialUSB.println("SparkFun NEO-M9N GPS");
  delay(100);

  gnss.setI2COutput(COM_TYPE_UBX);
  gnss.setNavigationFrequency(1);
    
  uint8_t rate = gnss.getNavigationFrequency();
  SerialUSB.print("Current update rate: ");
  SerialUSB.println(rate);  
}

void loop()
{ 
  if (millis() - last_time > 1000)
  {
    last_time = millis();

    long latitude = gnss.getLatitude();
    SerialUSB.print(F("Lat [degrees]: "));
    SerialUSB.print(latitude / 10000000.0);

    long longitude = gnss.getLongitude();
    SerialUSB.print(F(" Long [degrees]: "));
    SerialUSB.print(longitude / 10000000.0);

    long altitude = gnss.getAltitude();
    SerialUSB.print(F(" Alt [m]: "));
    SerialUSB.print(altitude / 1000.0);
    
    long altitudeMSL = gnss.getAltitudeMSL();
    SerialUSB.print(F(" AltMSL [m]: "));
    SerialUSB.print(altitudeMSL / 1000.0);

    byte fixType = gnss.getFixType();
    SerialUSB.print(F(" Fix: "));
    if(fixType == 0) SerialUSB.print(F("No fix"));
    else if(fixType == 1) SerialUSB.print(F("Dead reckoning"));
    else if(fixType == 2) SerialUSB.print(F("2D"));
    else if(fixType == 3) SerialUSB.print(F("3D"));
    else if(fixType == 4) SerialUSB.print(F("GNSS + Dead reckoning"));
    else if(fixType == 5) SerialUSB.print(F("Time only"));
    
    long speed = gnss.getGroundSpeed();
    SerialUSB.print(F(" Speed [m/s]: "));
    SerialUSB.print(speed / 1000.0);

    long heading = gnss.getHeading();
    SerialUSB.print(F(" Heading [degrees]: "));
    SerialUSB.print(heading / 100000);

    int pDOP = gnss.getPDOP();
    SerialUSB.print(F(" pDOP: "));
    SerialUSB.print(pDOP / 100.0, 2);
    
    byte SIV = gnss.getSIV();
    SerialUSB.print(F(" SIV: "));
    SerialUSB.print(SIV);

    SerialUSB.print(" ");
    SerialUSB.print(gnss.getYear());
    SerialUSB.print("-");
    SerialUSB.print(gnss.getMonth());
    SerialUSB.print("-");
    SerialUSB.print(gnss.getDay());
    SerialUSB.print(" ");
    SerialUSB.print(gnss.getHour());
    SerialUSB.print(":");
    SerialUSB.print(gnss.getMinute());
    SerialUSB.print(":");
    SerialUSB.print(gnss.getSecond());

    SerialUSB.print("  Time is ");
    if (!gnss.getTimeValid())
    {
      SerialUSB.print("not ");
    }
    SerialUSB.print("valid  Date is ");
    if (!gnss.getDateValid())
    {
      SerialUSB.print("not ");
    }
    SerialUSB.print("valid");
    
    SerialUSB.println();
  }    
}

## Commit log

2021-07-18 general docs: overview, licence and bill of materials
2021-07-18 CAD design
    [Air_Holes.FCStd, Air_Holes.step, Back_Wall.FCStd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]
2021-07-18 3D print
2021-07-18 hardware assembly
2021-07-18 basic software setup
    [H_t265_d400.cfg, bracket_t265nd435_external.stl, rs-save-to-disk-output-DEPTH-metadata.csv]
